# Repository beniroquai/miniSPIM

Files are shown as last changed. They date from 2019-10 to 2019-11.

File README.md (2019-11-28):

# miniSPIM
An attempt to democratize light-sheet microscopy. 

This is the repository for the open-source low-cost light-sheet microscope based on a monochromatic cellphone CMOS sensor and commercially available laser-scanning video projector.

<p align="center">
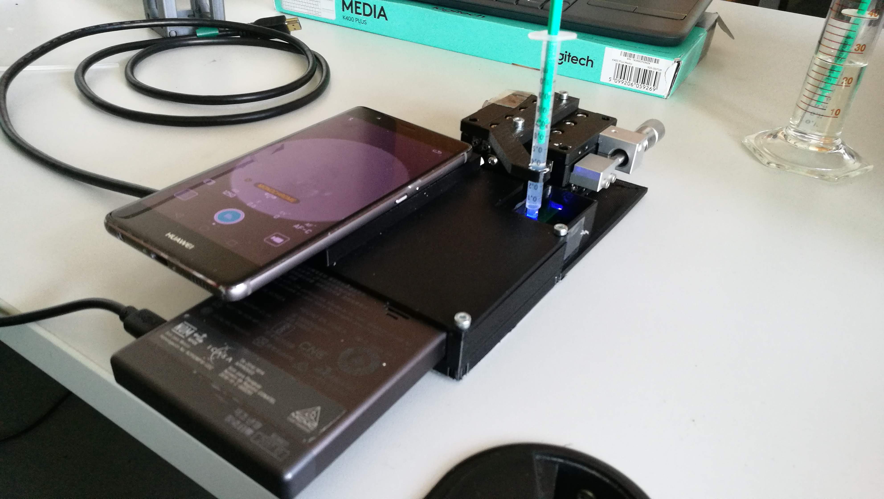
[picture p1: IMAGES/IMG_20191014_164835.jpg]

</p>

Disucssion can also be found in [Twitter](https://twitter.com/beniroquai/status/1185129736726560768)

Everything on your own risk, no guarantees that it works or that it harms you! It's just a fun project without any professional use in mind! 

## Motivation

*  Low price (<500€) 
*  Portable
*  Small footprint
*  ready for the incubator 
*  Isotropic resolution of about 3µm 
*  Excitation Wavelength: 450, 530, 605nm 
*  Mechanical X/Y-Stage for coarse sample movevement 
*  Electrical X/Y-Stage for fine through-focus series of the sample 

## ANDROID APP
**NEW**: Now we support the system with a stand-alone Android App which takes care of the following:

- Image acquisition (monochrome Huawei, RAW, manual texp, ISO-settings)
- Hardware control of the X/Y-stage for through-focus series (MQTT-based) 
- Control of the Light-sheet displayed on the Laser-projector

Everything can be found in the folder [ANDROID](.\ANDROID). It has been tested with a HUAWEI P9.
To display the pattern using a smartphone, one need to connect the laser-projector to the Phone using a HDMI-HML adapter (i.e. USB-c to HDMI), available for 8€ at Ebay. 

The 
<p align="center">
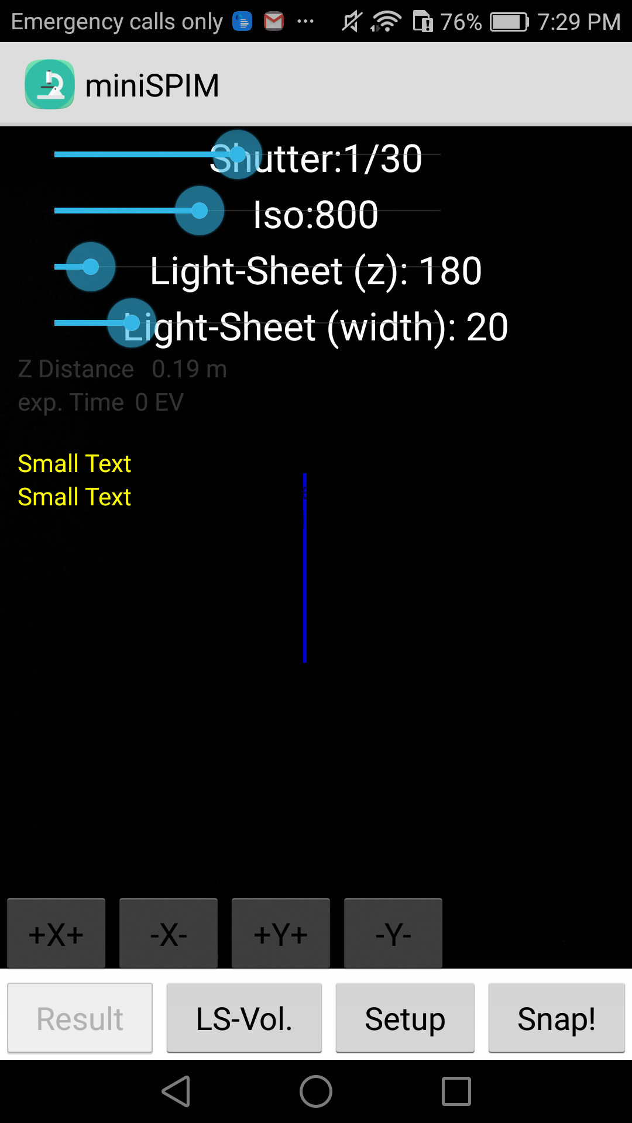
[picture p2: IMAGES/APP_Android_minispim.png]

</p>

The blue stripe is the secondary screen displayed in debug mode. 

## Setup

### Optical Setup

The 
<p align="center">
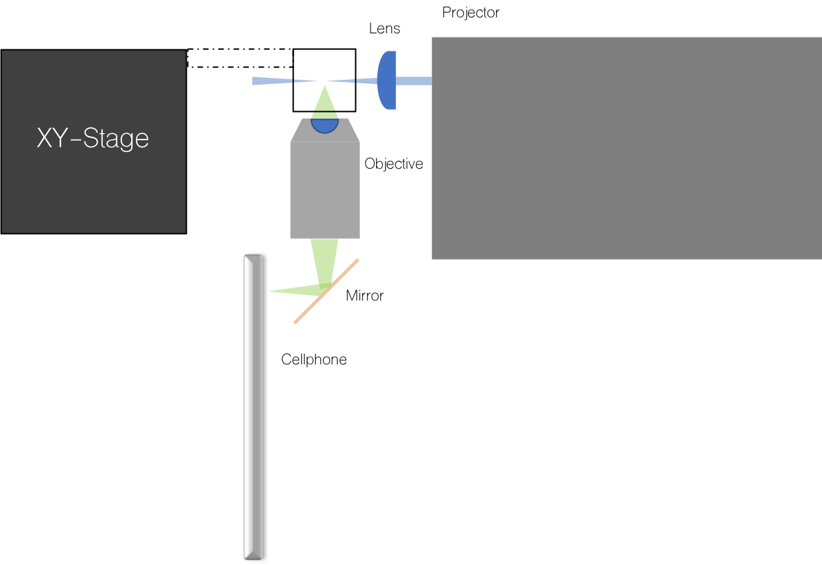
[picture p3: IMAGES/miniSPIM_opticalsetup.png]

</p>

### Remove the lens of the Huawei P9 (at your own risk!!)

In this setup, we had to remove the lens to have bare accessoto the Sony IMX286 monochromatic chip. A minimum set of tools was necessary. A brief description with pictures is shown below

#### Open the cellphone
<p align="center">
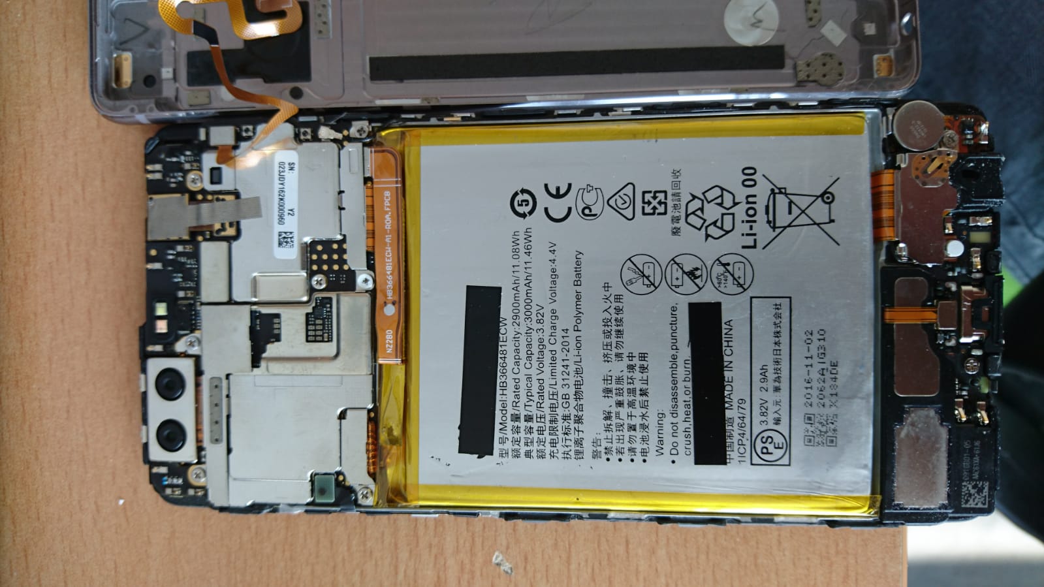
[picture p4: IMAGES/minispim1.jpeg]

</p>

#### Get out the camera module
<p align="center">
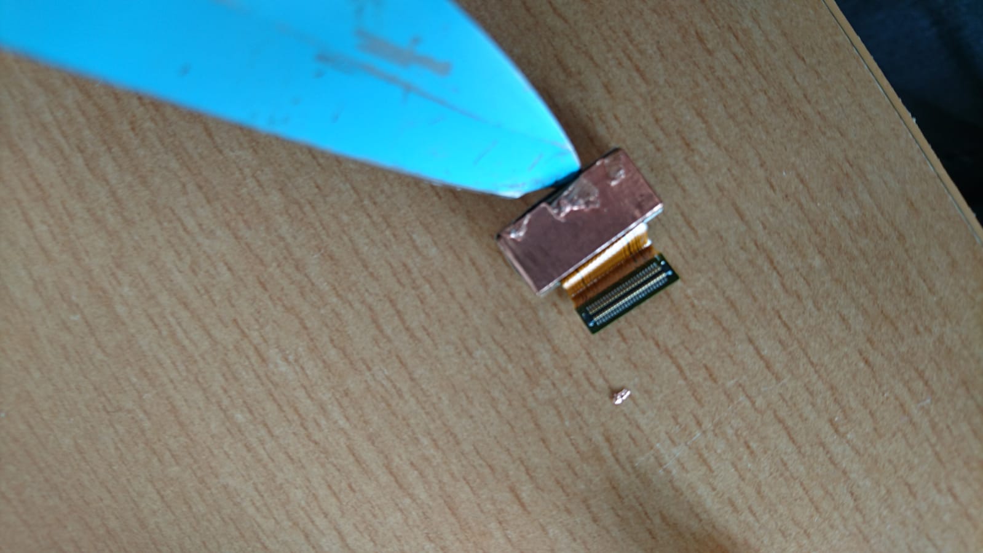
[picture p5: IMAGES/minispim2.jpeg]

</p>

#### Get out the camera module II
<p align="center">
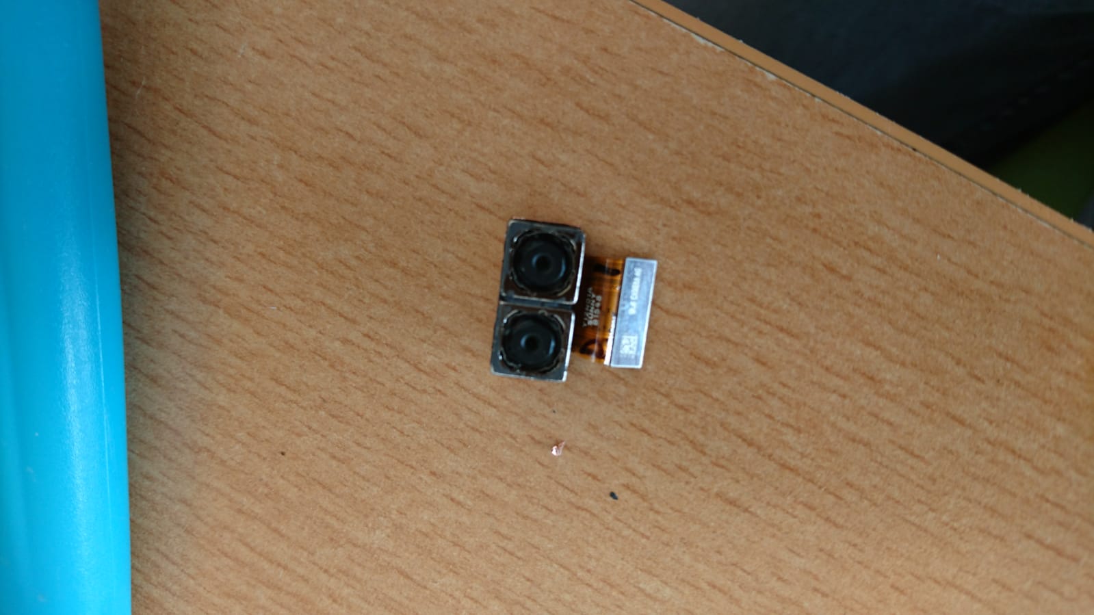
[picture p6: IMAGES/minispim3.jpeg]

</p>

#### Get rid of the left (!) lens module - take a knife to remove the soldering gently (!)
<p align="center">
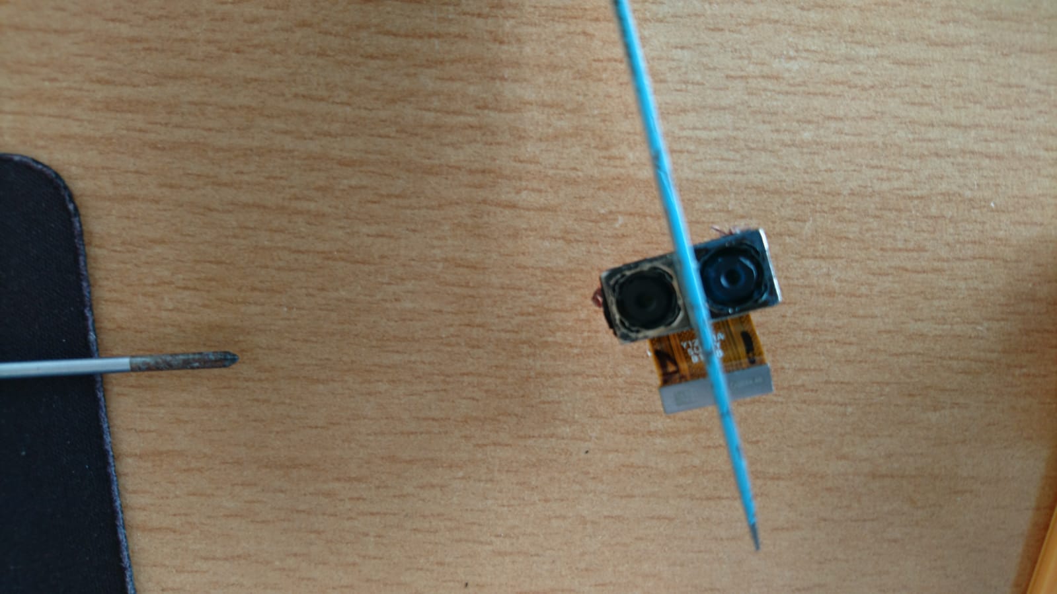
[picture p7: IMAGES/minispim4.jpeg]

</p>

#### Get rid of the lens module 
<p align="center">
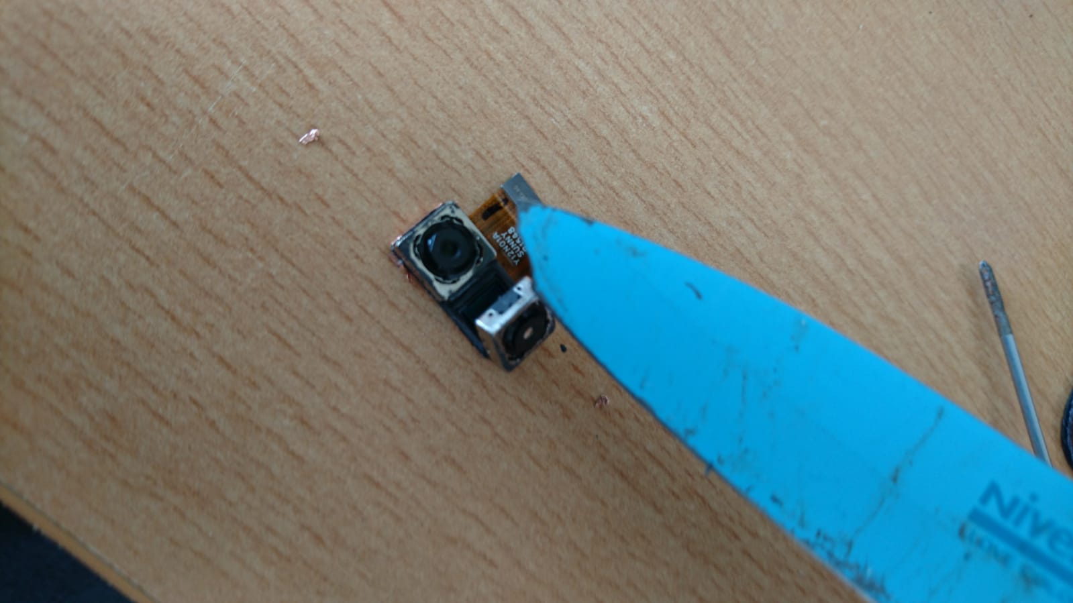
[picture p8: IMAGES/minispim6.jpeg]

</p>

#### Put the lens module back into the cellphone
<p align="center">
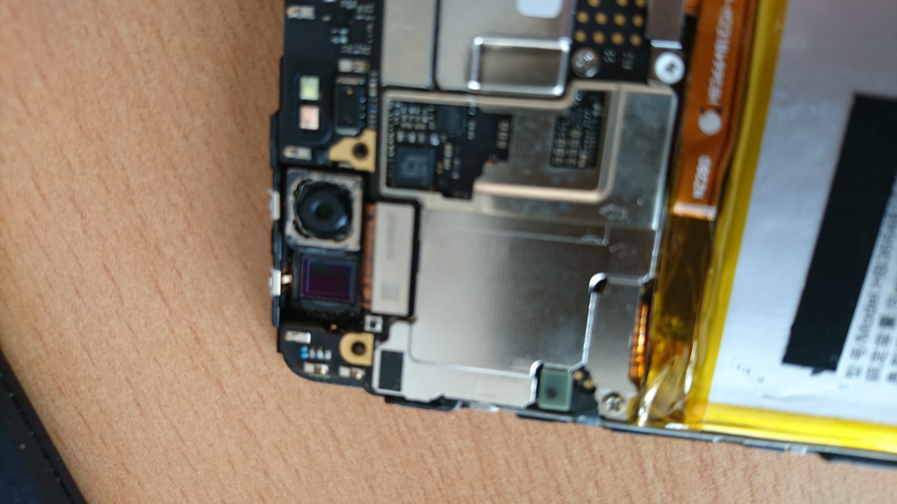
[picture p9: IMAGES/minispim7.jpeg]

</p>

#### Hope that everything went well!
<p align="center">
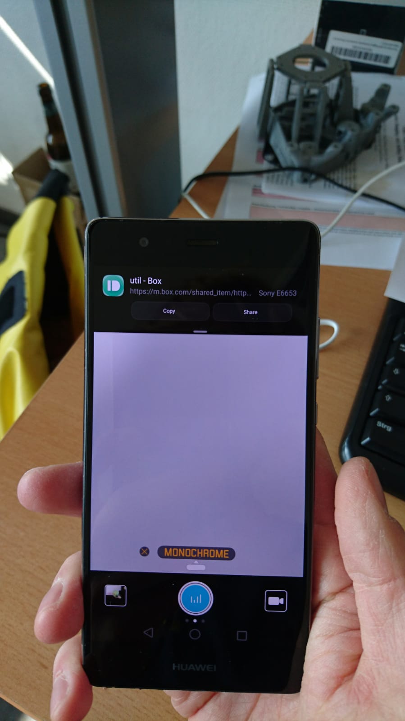
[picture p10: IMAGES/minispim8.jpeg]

</p>

### Mechanical Setup

The Setup is relatively simple to assemble. A base-plate holds the Projector, the lenses (CCTV as objective and 25mm lens as illumination objective) as well as the mirror. The lid holds everything in place and the smartphone adapter keeps the cellphone in the correct distance from the CCTV lens.

#### Sample mount 

One can use asimple syrringe for to prepare a sample e.g. in agarose. To reduce scattering, we provide a simple sample chaber which an be filled with water. The tip of the agarose can be put inside the water. 

### Electronic setup

For the wiring of the two bipolar motors from the low-cost XY-stage, we used an Arduino Nano equipped with two H-bridges directly connected to the motor. 

The following gives you a very brief introduction of the workin principle of the low-cost, but very precise Z-stage which is used in our setups. You can find a more detailed version of the description at [aliexpress](https://aliexpress.com/item/Micro-stepping-motor-cross-platform-small-mobile-digital-microscope-XY-axis-table-experiment-two-slide/32790147861.html) (chineses though). 
I have absolutely no clue where this piece is actually coming from, but it is working really great! 

It is equipped with two bipolar stepper motors for X and Y direction. The wiring follows (from left to right):

	1 -- A+	
	2 -- B+	
	3 -- A-	
	4 -- B-
	
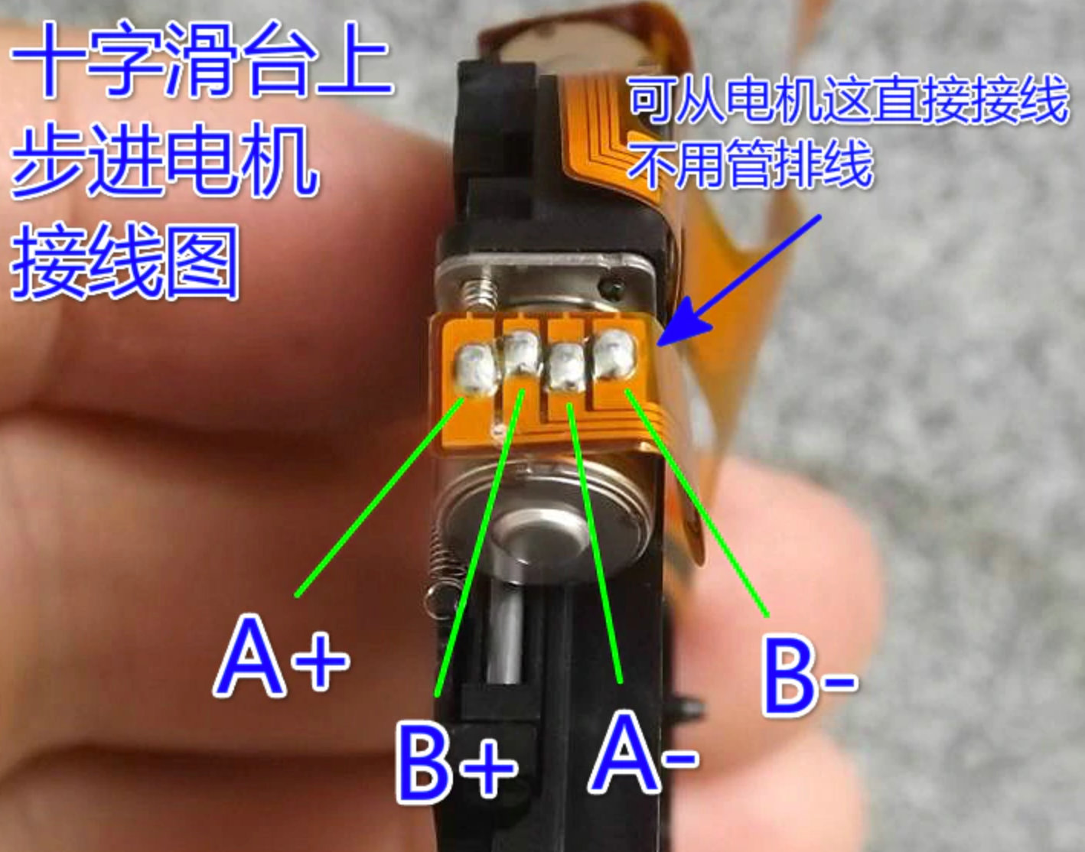
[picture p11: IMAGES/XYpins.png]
xypins


It can be controlled with an ESP32 or Arduino for example. Code is very easy as it relies on the $stepper.h$ library in Arduion IDE. We tested seveal H-Bridges to amplify the current coming from the Arduino GPIOs. The L293m works fine, but the DRV8833 is also good and even much smaller. The complete tutorial for can also be found at [Adafruit](https://learn.adafruit.com/adafruit-drv8833-dc-stepper-motor-driver-breakout-board/stepper-motor-usage). 

The motor can be connected as follows:

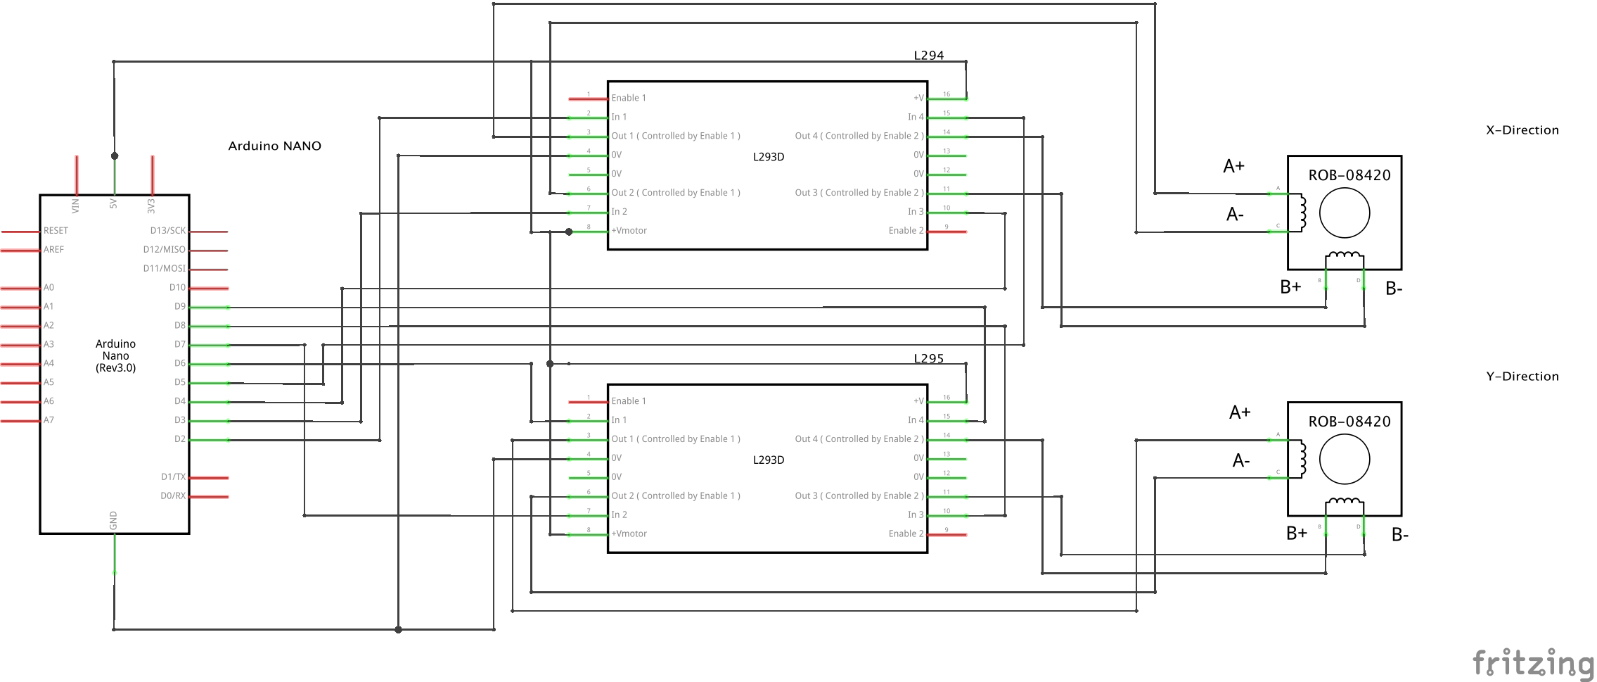
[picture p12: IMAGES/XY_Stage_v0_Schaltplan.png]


If one uses an H-Bridge one simply need to make sure, that A+/A- and B+/B- are connected to MOTOR A and MOTOR B respectively. 

#### Properties
	- Impedance: ~45 ohm
	- Stepsize: 18 degree
	- Voltage: 5 V
	- Peak Current: 100mA 
	- Movement X/Y: 2.4 mm

### Code 
The code is from the Adafruit example with the wiring explained above:

	#include <Stepper.h>
 
	// change this to the number of steps on your motor
	#define STEPS 200
	 
	// create an instance of the stepper class, specifying
	// the number of steps of the motor and the pins it's
	// attached to
	Stepper stepper(STEPS, 4, 5, 6, 7);

	void setup()
	{
	  Serial.begin(9600);
	  Serial.println("Stepper test!");
	  // set the speed of the motor to 30 RPMs
	  stepper.setSpeed(60);
	}
	 
	void loop()
	{
	  Serial.println("Forward");
	  stepper.step(STEPS);
	  Serial.println("Backward");
	  stepper.step(-STEPS);
	}

### NOTES
Make sure you're releasing the Motor after usage, otherwise it can get quiet hot!

## Experiments

In order to perform an experiment one need to do the following steps:

* Generate the light-sheet pattern using a computer by displaying a single-pixel line on a full-screen image (e.g. black screen, blue line (RGB=0,0,255))
* Eventually move the line periodically to find the best position of the light sheet (use the PPT in the presentation folder) 
* Align the smartphone, so that the round-circle is in the center of the CMOS camera sensor (therefore take a light-source and shine light inside the smaple chamber, i.e. inline with the CCTV lens)
* Insert the syringe in the sample holder
* Move the X/Y move so that the sample is in focus by placing a light source perpendicular to the light-sheet or in-line with the detection objective 
* Let the electric X/Y stage oscillate back and forth to acquire a through-focus series 
* Acquire a video sequence of the sample

## Parts 

### 3D printed parts 
All files can be found in the folder [STL](./STL). 

* 1x [Base Plate](./STL/0_MiniSPIM_Base_v1.stl)
* 1x [Sample Chamber](./STL/10_MiniSPIM_Samplechamber.stl)
* 1x [Space for Smartphone](./STL/10_MiniSPIM_Smarthponebase.stl)
* 1x [Lid for the Baseplate](./STL/10_MiniSPIM_Lid.stl)
* 1x [Adapter for the XY-Stage: Arm which holds the syrringe](./STL/10_MiniSPIM_XY_Stageplate.stl)
* 1x [Adapter for the XY-Stage: Arm which holds the electronic XY-stage](./STL/10_MiniSPIM_XY_Stageplate.stl)

### Bill of materials

(Links to the shops are not sponsored!)

* 1x cellphone (Huawei P9, remove the lens from the monochromatic camera) - ***150€***
* 1x XY-Stage (60x60xmm range) - ***60€***
* 1x motorized XY-Stage ([aliexpress](https://aliexpress.com/item/Micro-stepping-motor-cross-platform-small-mobile-digital-microscope-XY-axis-table-experiment-two-slide/32790147861.html) ) - ***3€***
* 1x ESP32 - ***5€***
* Set of M3 screws - ***1€***
* 3x Coverglass, 18x18mm - ***1€***
* 1x Laser-scanning projector, SONY MP-CL1A [Link to Sony](https://www.sony.com/electronics/projector/mp-cl1a) - ***250€***
* Filterset ***1€***
* Wires, USB-Cable, HDMI-Cable - ***15€***
* Comar Mirror d=10mm - ***20€***
* 1x CCTV Lens (f=4mm, f#=1.8) - ***10€***
* 1x 25mm lens, diameter: 15mm

## Results

### Acquisition using the cellphone 

The Huawei P9 does not allow the acquisition of monochromatic videos by default. Therefore we used the open-source app ***FreeDCam*** available from [github](https://github.com/KillerInk/FreeDcam/tree/cellstorm) or the playstore. In order to reduce the bouncing effect caused by intereference of the scan-speed of the laser (60 Hz), one need to select a frame-rate t_exp < 1/60 s respectively. ISO settings should be selected to get enough signal (usally 1000-2000) for high-quality samples. 

### Use MP4 in Fiji 

Since Fiji does not accept ```.mp4```-files by default, one need to transcode the video into a sequence of images which can be imported through Fiji. This can conveniently be done by using ```ffmpeg``` (freely available from Windows, MAC and Linux!). A standard command to extract the frames into a folder is the following: 

```ffmpeg -i MOV_2019_10_24_07_33_13.mp4 -filter:v "crop=1024:1024:512:512" -vsync 0  MOV_2019_10_24_07_33_13/cropped%06d.png```

### Lens-tissue Focus-Sweep

Here a lens-tissue "labelled" with fluorescent marker (Stabilo, Fluorescent Yellow) was swept through the focus. A theater filter blocks the light of the blue exciting laser. 

<p align="center">
<img src="./IMAGES/miniSPIM_Focus_Sweep_Lenstissue.gif" width="400">
</p>

A 3D projection of the result in ClearVolume looks like this: 
<p align="center">
<img src="./IMAGES/miniSPIM_lenstissue.png" width="400">
</p>

### Bright-field and light-sheet mode of Pollen

<p align="center">
<img src="./IMAGES/IMG_20191014_163941.jpg" width="400">
</p>

<p align="center">
<img src="./IMAGES/IMG_20191014_164712.jpg" width="400">
</p>

Better images are coming soon! 

## License
Hardware follows the CERN license. Everything else is licensed under CC-BY-NC. 

Everything is free to use - but we would like to ask you for any suggestions and comments. This makes sure, that we can improve this project. 

Everything was developed in the [@Heintzmann-Lab](www.nanoimaging.de) around Rainer Heintzmann at the IPHT Jena. 

## Contribution

We need proper samples! If you know how to prepare easy to use cleared fluorescent samples ready for the SPIM, please contact us!! :) 

In case you have any questions, please fiel an issue or write us an email. We try to improve the setup. 

There is high potential to automate everything - if you have time and want to do that: We hire (but don't have any money - sorry ;-)

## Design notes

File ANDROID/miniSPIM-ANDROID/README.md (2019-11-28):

Machine-learned Phase-Contrast using a 3D printed microscope based on DPC
=========================================================================

Derived from code snippets used in the paper paper by Lei Tian, Jingyan Wang, and Laura Waller

The app takes a series of images, where the "Presentation API" from Android displays a specific pattern on a projector. The images are getting processed to feed a neural network trained in Tensorflow to produce an optimized illumination shape to enhance the phase contrast of an arbitrary object.

The version here is distributed under the GPL v3 license. If you have any questions, please get back to us by contacting us: https://nanoimaging.de

## INSTRUCTIONS 
A set of instructions can be found here:
[PDF Tutorial:](https://github.com/bionanoimaging/Beamerscope_CAD/blob/master/Beamerscope_Instructions.pdf)

If you need any further details, please contact us via our [website](nanoimaging.de).

CAD Drawing Beamerscope

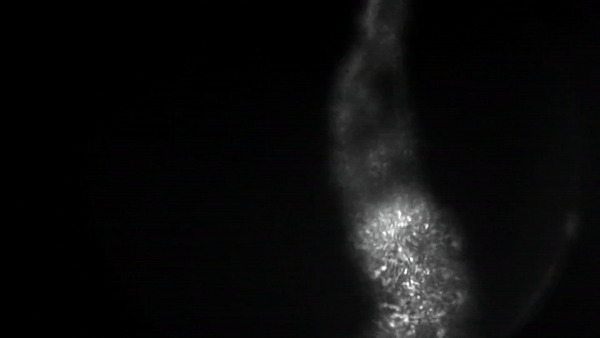
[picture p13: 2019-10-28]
IMAGES/miniSPIM_Focus_Sweep_Lenstissue.gif

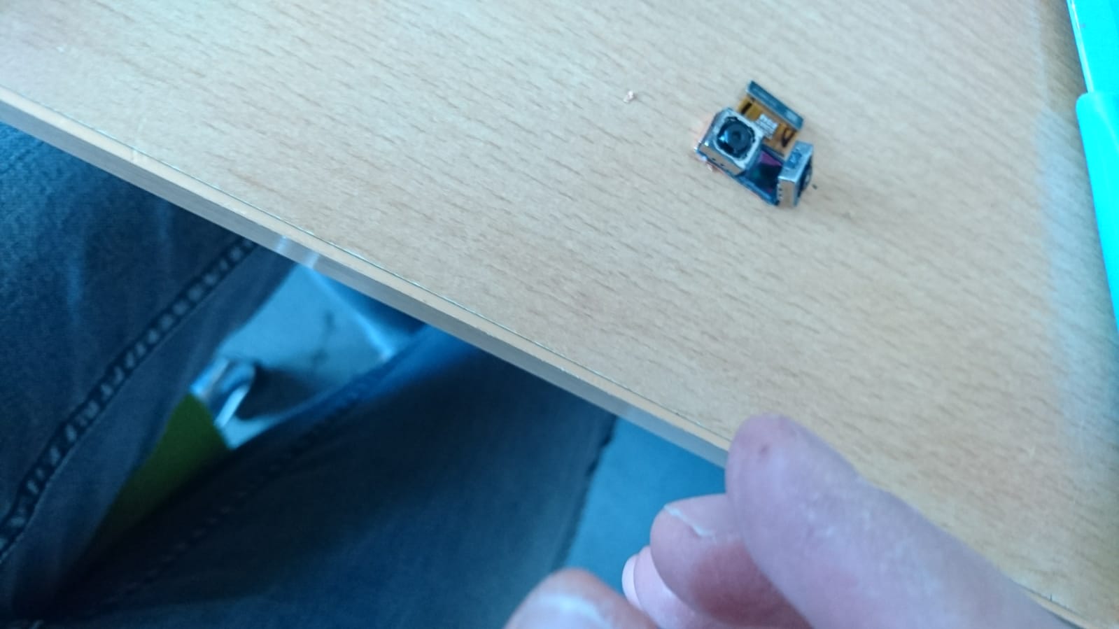
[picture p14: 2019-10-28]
IMAGES/minispim5.jpeg

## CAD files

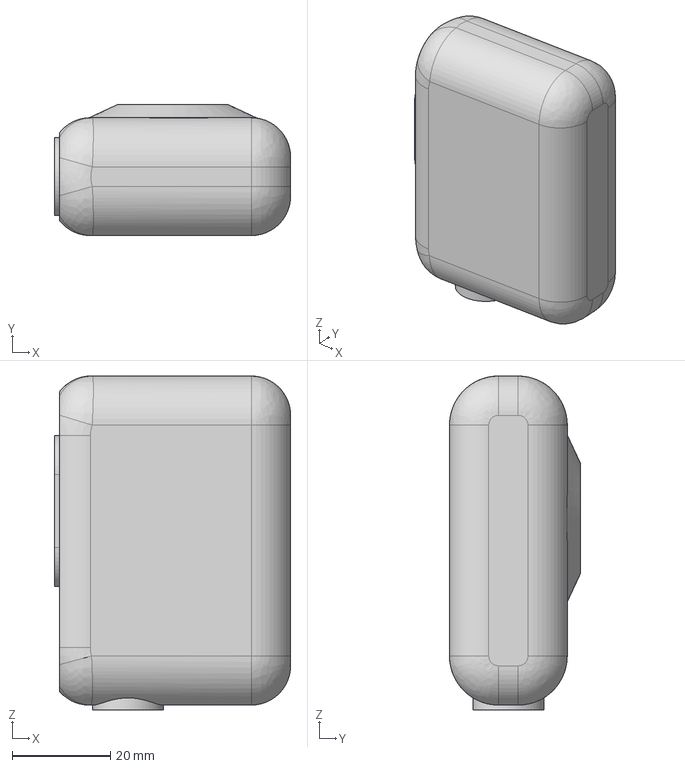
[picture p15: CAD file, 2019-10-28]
INVENTOR/100_DXO_Camera v2.step
48.1 x 26.7 x 68.0 mm

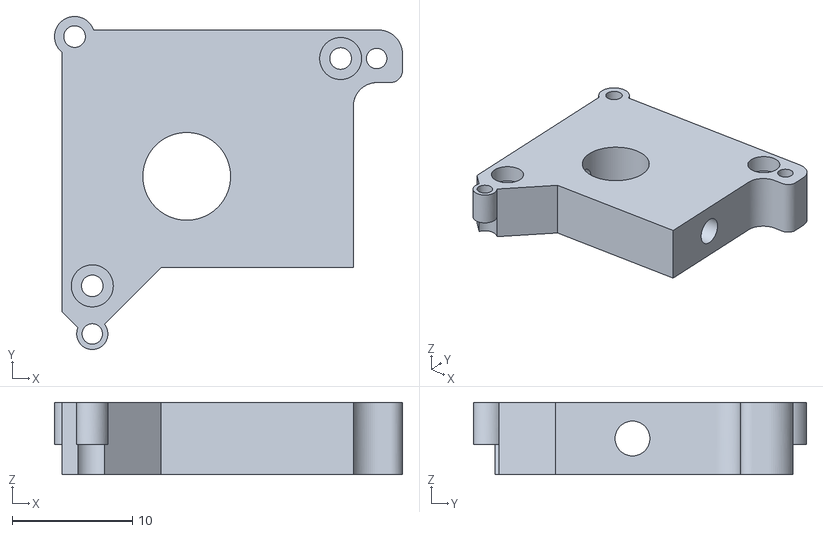
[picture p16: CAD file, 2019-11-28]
STL/110_Syrringeholder_XY_Stage.stl
29.0 x 27.7 x 6.00

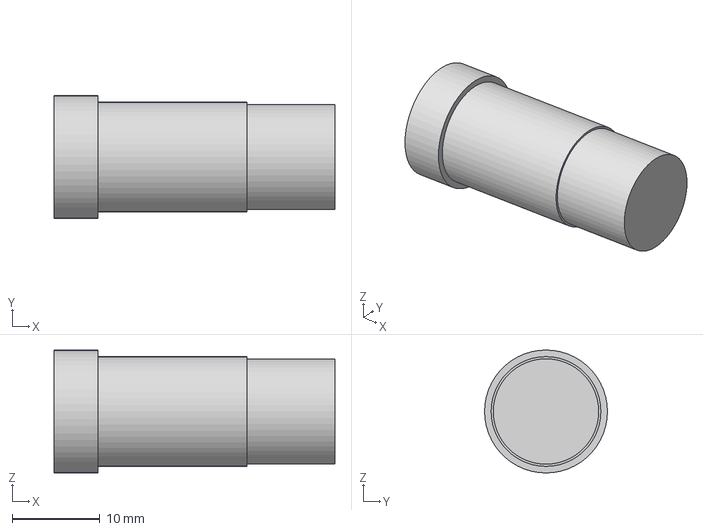
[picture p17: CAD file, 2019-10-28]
INVENTOR/104_CCTV_Lens_f2.8_#1.4 v2.step
32.0 x 14.0 x 14.0 mm

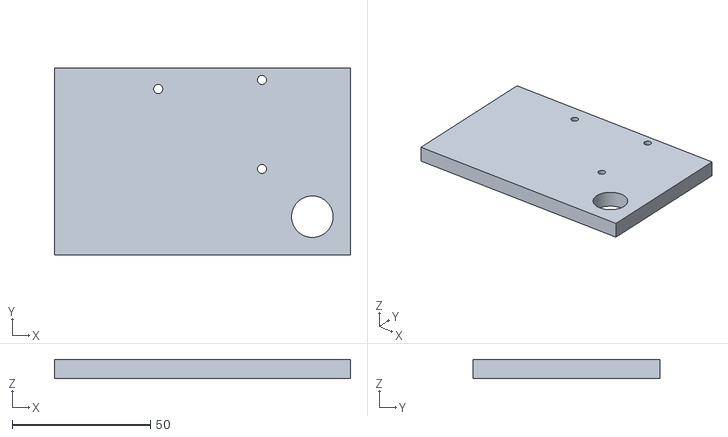
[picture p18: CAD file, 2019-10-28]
STL/10_MiniSPIM_Smarthponebase.stl
107.0 x 67.5 x 6.90

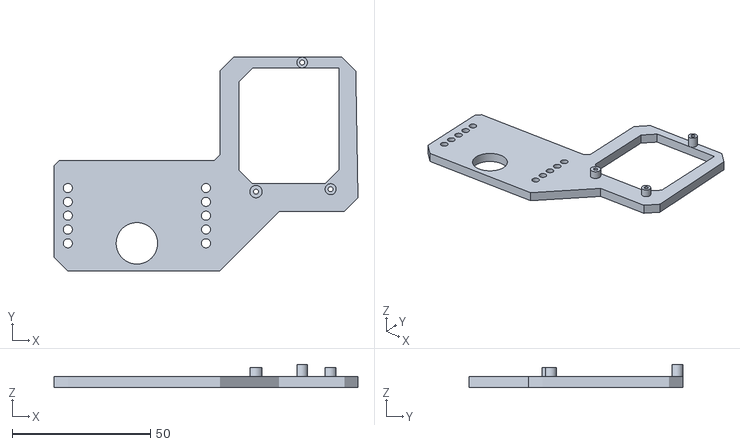
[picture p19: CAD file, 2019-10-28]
STL/10_MiniSPIM_XY_Stageplate.stl
110.0 x 77.3 x 8.50

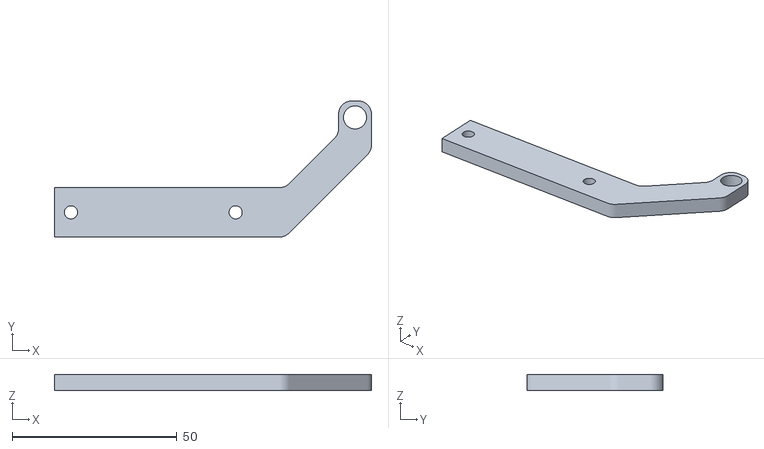
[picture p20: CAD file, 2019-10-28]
STL/10_MiniSPIM_Sampleholder.stl
96.2 x 41.3 x 5.00

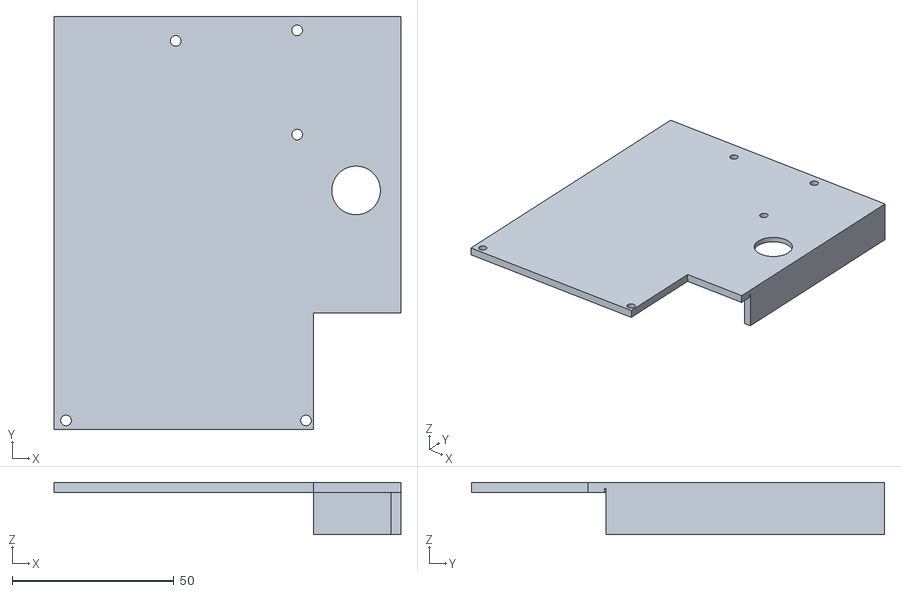
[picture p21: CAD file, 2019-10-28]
STL/10_MiniSPIM_Lid.stl
107.0 x 127.5 x 16.2

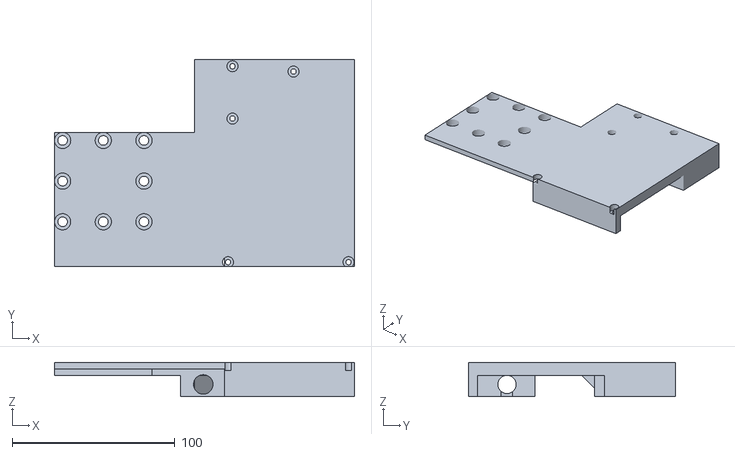
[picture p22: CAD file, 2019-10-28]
STL/10_MiniSPIM_Base_v1.stl
184.4 x 127.5 x 21.1

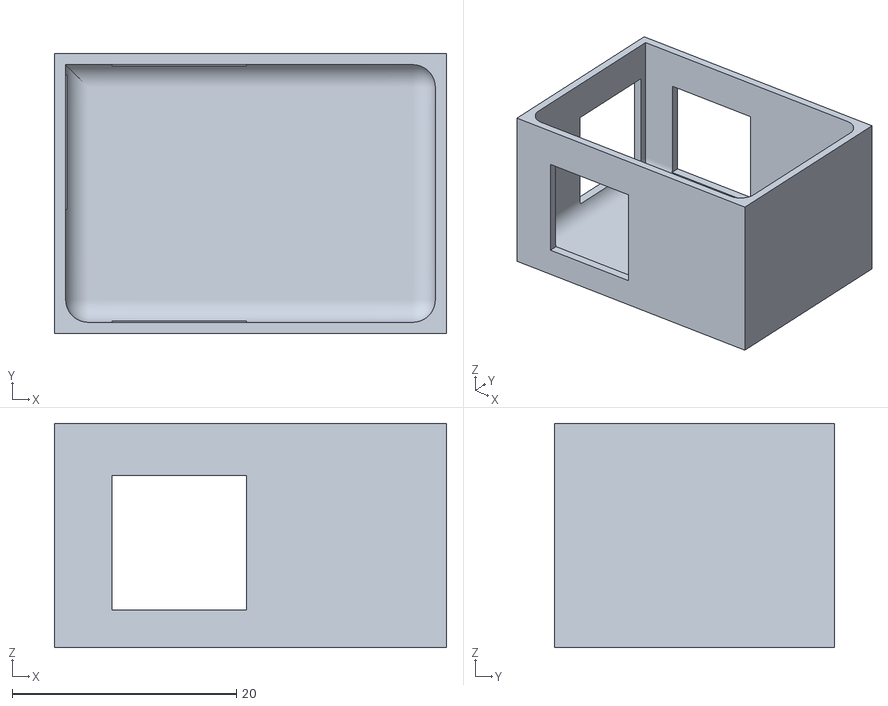
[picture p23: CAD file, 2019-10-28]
STL/10_MiniSPIM_Samplechamber.stl
35.0 x 25.0 x 20.0

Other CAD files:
INVENTOR/00_Huawei_P9.ipt
INVENTOR/00_Laserpointer_450nm_blue.ipt
INVENTOR/00_Lens_f_25mm.ipt
INVENTOR/00_Lightpath.ipt
INVENTOR/00_Mirror_10mmDia.ipt
INVENTOR/00_Sony_MDL_Projector.ipt
INVENTOR/00_XY-Tisch_Chinaware_Benedict-Diederich.ipt
INVENTOR/00_XY_stage-CHUO_SEIKI_LD-647-R1-Bottom.ipt
INVENTOR/00_XY_stage-CHUO_SEIKI_LD-647-R1-Middle.ipt
INVENTOR/00_XY_stage-CHUO_SEIKI_LD-647-R1-Top.ipt
INVENTOR/00_XY_stage-CHUO_SEIKI_LD-647-R1.iam
INVENTOR/100_DXO_Camera v2.ipt
INVENTOR/101_CCTV_Lens_Thread.ipt
INVENTOR/102_Z_Focus_CCTV_Camera.ipt
INVENTOR/103_CCTV_Lens_f2.8_f#1.4 v1.f3d
INVENTOR/103_CCTV_Lens_f2.8_f#1.ipt
INVENTOR/104_CCTV_Lens_f2.8_#1.ipt
INVENTOR/105_CCTV_Lens_f6_f#1.ipt
INVENTOR/106_Glassslab.ipt
INVENTOR/109_Chinese_XY_stage.ipt
INVENTOR/10_Baseplate_Minispim.ipt
INVENTOR/10_Lid_Minispim.ipt
INVENTOR/10_Lidplate_Minispim.ipt
INVENTOR/10_MiniSPIM_Base_v1.ipt
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

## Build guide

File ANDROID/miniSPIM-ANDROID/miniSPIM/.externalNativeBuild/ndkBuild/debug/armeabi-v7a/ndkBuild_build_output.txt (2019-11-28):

rm -f /Users/Bene/Dropbox/Dokumente/OpticalDesign/Beamerscope/Android/BeamerscopeIlloptimization/holoscope/build/intermediates/ndkBuild/debug/lib/armeabi-v7a/lib*.so
rm -f /Users/Bene/Dropbox/Dokumente/OpticalDesign/Beamerscope/Android/BeamerscopeIlloptimization/holoscope/build/intermediates/ndkBuild/debug/lib/armeabi-v7a/gdbserver
rm -f /Users/Bene/Dropbox/Dokumente/OpticalDesign/Beamerscope/Android/BeamerscopeIlloptimization/holoscope/build/intermediates/ndkBuild/debug/lib/armeabi-v7a/gdb.setup
echo [armeabi-v7a] "Compile++ thumb": "native_microscope <= cvComplex.cpp"
/Users/Bene/Library/Android/sdk/ndk-bundle/toolchains/arm-linux-androideabi-4.9/prebuilt/darwin-x86_64/bin/arm-linux-androideabi-g++ -MMD -MP -MF /Users/Bene/Dropbox/Dokumente/OpticalDesign/Beamerscope/Android/BeamerscopeIlloptimization/holoscope/.externalNativeBuild/ndkBuild/debug/obj/local/armeabi-v7a/objs/native_microscope/cvComplex.o.d -fpic -ffunction-sections -funwind-tables -fstack-protector-strong -no-canonical-prefixes  -g -march=armv7-a -mfpu=vfpv3-d16 -mfloat-abi=softfp  -fno-exceptions -fno-rtti -mthumb -Os -DNDEBUG  -I"/Users/Bene/Android/opencv3/sdk/native/jni/include/opencv" -I"/Users/Bene/Android/opencv3/sdk/native/jni/include" -I/Users/Bene/Android/opencv3/sdk/native/jni/include/ -I/Users/Bene/Dropbox/Dokumente/OpticalDesign/Beamerscope/Android/BeamerscopeIlloptimization/holoscope/src/main/jni -I/Users/Bene/Library/Android/sdk/ndk-bundle/sources/cxx-stl/gnu-libstdc++/4.9/include -I/Users/Bene/Library/Android/sdk/ndk-bundle/sources/cxx-stl/gnu-libstdc++/4.9/libs/armeabi-v7a/include -I/Users/Bene/Library/Android/sdk/ndk-bundle/sources/cxx-stl/gnu-libstdc++/4.9/include/backward -I/Users/Bene/Dropbox/Dokumente/OpticalDesign/Beamerscope/Android/BeamerscopeIlloptimization/holoscope/src/main/jni -DANDROID -fPIC -DANDROID -fsigned-char -Wa,--noexecstack -Wformat -Werror=format-security    -frtti -fexceptions  -isystem /Users/Bene/Library/Android/sdk/ndk-bundle/platforms/android-19/arch-arm/usr/include -c  /Users/Bene/Dropbox/Dokumente/OpticalDesign/Beamerscope/Android/BeamerscopeIlloptimization/holoscope/src/main/jni/cvComplex.cpp -o /Users/Bene/Dropbox/Dokumente/OpticalDesign/Beamerscope/Android/BeamerscopeIlloptimization/holoscope/.externalNativeBuild/ndkBuild/debug/obj/local/armeabi-v7a/objs/native_microscope/cvComplex.o 
echo [armeabi-v7a] "Compile++ thumb": "native_microscope <= common.cpp"
/Users/Bene/Library/Android/sdk/ndk-bundle/toolchains/arm-linux-androideabi-4.9/prebuilt/darwin-x86_64/bin/arm-linux-androideabi-g++ -MMD -MP -MF /Users/Bene/Dropbox/Dokumente/OpticalDesign/Beamerscope/Android/BeamerscopeIlloptimization/holoscope/.externalNativeBuild/ndkBuild/debug/obj/local/armeabi-v7a/objs/native_microscope/common.o.d -fpic -ffunction-sections -funwind-tables -fstack-protector-strong -no-canonical-prefixes  -g -march=armv7-a -mfpu=vfpv3-d16 -mfloat-abi=softfp  -fno-exceptions -fno-rtti -mthumb -Os -DNDEBUG  -I"/Users/Bene/Android/opencv3/sdk/native/jni/include/opencv" -I"/Users/Bene/Android/opencv3/sdk/native/jni/include" -I/Users/Bene/Android/opencv3/sdk/native/jni/include/ -I/Users/Bene/Dropbox/Dokumente/OpticalDesign/Beamerscope/Android/BeamerscopeIlloptimization/holoscope/src/main/jni -I/Users/Bene/Library/Android/sdk/ndk-bundle/sources/cxx-stl/gnu-libstdc++/4.9/include -I/Users/Bene/Library/Android/sdk/ndk-bundle/sources/cxx-stl/gnu-libstdc++/4.9/libs/armeabi-v7a/include -I/Users/Bene/Library/Android/sdk/ndk-bundle/sources/cxx-stl/gnu-libstdc++/4.9/include/backward -I/Users/Bene/Dropbox/Dokumente/OpticalDesign/Beamerscope/Android/BeamerscopeIlloptimization/holoscope/src/main/jni -DANDROID -fPIC -DANDROID -fsigned-char -Wa,--noexecstack -Wformat -Werror=format-security    -frtti -fexceptions  -isystem /Users/Bene/Library/Android/sdk/ndk-bundle/platforms/android-19/arch-arm/usr/include -c  /Users/Bene/Dropbox/Dokumente/OpticalDesign/Beamerscope/Android/BeamerscopeIlloptimization/holoscope/src/main/jni/common.cpp -o /Users/Bene/Dropbox/Dokumente/OpticalDesign/Beamerscope/Android/BeamerscopeIlloptimization/holoscope/.externalNativeBuild/ndkBuild/debug/obj/local/armeabi-v7a/objs/native_microscope/common.o 
echo [armeabi-v7a] "Compile++ thumb": "native_microscope <= jni_qDPC.cpp"
/Users/Bene/Library/Android/sdk/ndk-bundle/toolchains/arm-linux-androideabi-4.9/prebuilt/darwin-x86_64/bin/arm-linux-androideabi-g++ -MMD -MP -MF /Users/Bene/Dropbox/Dokumente/OpticalDesign/Beamerscope/Android/BeamerscopeIlloptimization/holoscope/.externalNativeBuild/ndkBuild/debug/obj/local/armeabi-v7a/objs/native_microscope/jni_qDPC.o.d -fpic -ffunction-sections -funwind-tables -fstack-protector-strong -no-canonical-prefixes  -g -march=armv7-a -mfpu=vfpv3-d16 -mfloat-abi=softfp  -fno-exceptions -fno-rtti -mthumb -Os -DNDEBUG  -I"/Users/Bene/Android/opencv3/sdk/native/jni/include/opencv" -I"/Users/Bene/Android/opencv3/sdk/native/jni/include" -I/Users/Bene/Android/opencv3/sdk/native/jni/include/ -I/Users/Bene/Dropbox/Dokumente/OpticalDesign/Beamerscope/Android/BeamerscopeIlloptimization/holoscope/src/main/jni -I/Users/Bene/Library/Android/sdk/ndk-bundle/sources/cxx-stl/gnu-libstdc++/4.9/include -I/Users/Bene/Library/Android/sdk/ndk-bundle/sources/cxx-stl/gnu-libstdc++/4.9/libs/armeabi-v7a/include -I/Users/Bene/Library/Android/sdk/ndk-bundle/sources/cxx-stl/gnu-libstdc++/4.9/include/backward -I/Users/Bene/Dropbox/Dokumente/OpticalDesign/Beamerscope/Android/BeamerscopeIlloptimization/holoscope/src/main/jni -DANDROID -fPIC -DANDROID -fsigned-char -Wa,--noexecstack -Wformat -Werror=format-security    -frtti -fexceptions  -isystem /Users/Bene/Library/Android/sdk/ndk-bundle/platforms/android-19/arch-arm/usr/include -c  /Users/Bene/Dropbox/Dokumente/OpticalDesign/Beamerscope/Android/BeamerscopeIlloptimization/holoscope/src/main/jni/jni_qDPC.cpp -o /Users/Bene/Dropbox/Dokumente/OpticalDesign/Beamerscope/Android/BeamerscopeIlloptimization/holoscope/.externalNativeBuild/ndkBuild/debug/obj/local/armeabi-v7a/objs/native_microscope/jni_qDPC.o 
echo [armeabi-v7a] "Compile++ thumb": "native_microscope <= jni_illpattern.cpp"
/Users/Bene/Library/Android/sdk/ndk-bundle/toolchains/arm-linux-androideabi-4.9/prebuilt/darwin-x86_64/bin/arm-linux-androideabi-g++ -MMD -MP -MF /Users/Bene/Dropbox/Dokumente/OpticalDesign/Beamerscope/Android/BeamerscopeIlloptimization/holoscope/.externalNativeBuild/ndkBuild/debug/obj/local/armeabi-v7a/objs/native_microscope/jni_illpattern.o.d -fpic -ffunction-sections -funwind-tables -fstack-protector-strong -no-canonical-prefixes  -g -march=armv7-a -mfpu=vfpv3-d16 -mfloat-abi=softfp  -fno-exceptions -fno-rtti -mthumb -Os -DNDEBUG  -I"/Users/Bene/Android/opencv3/sdk/native/jni/include/opencv" -I"/Users/Bene/Android/opencv3/sdk/native/jni/include" -I/Users/Bene/Android/opencv3/sdk/native/jni/include/ -I/Users/Bene/Dropbox/Dokumente/OpticalDesign/Beamerscope/Android/BeamerscopeIlloptimization/holoscope/src/main/jni -I/Users/Bene/Library/Android/sdk/ndk-bundle/sources/cxx-stl/gnu-libstdc++/4.9/include -I/Users/Bene/Library/Android/sdk/ndk-bundle/sources/cxx-stl/gnu-libstdc++/4.9/libs/armeabi-v7a/include -I/Users/Bene/Library/Android/sdk/ndk-bundle/sources/cxx-stl/gnu-libstdc++/4.9/include/backward -I/Users/Bene/Dropbox/Dokumente/OpticalDesign/Beamerscope/Android/BeamerscopeIlloptimization/holoscope/src/main/jni -DANDROID -fPIC -DANDROID -fsigned-char -Wa,--noexecstack -Wformat -Werror=format-security    -frtti -fexceptions  -isystem /Users/Bene/Library/Android/sdk/ndk-bundle/platforms/android-19/arch-arm/usr/include -c  /Users/Bene/Dropbox/Dokumente/OpticalDesign/Beamerscope/Android/BeamerscopeIlloptimization/holoscope/src/main/jni/jni_illpattern.cpp -o /Users/Bene/Dropbox/Dokumente/OpticalDesign/Beamerscope/Android/BeamerscopeIlloptimization/holoscope/.externalNativeBuild/ndkBuild/debug/obj/local/armeabi-v7a/objs/native_microscope/jni_illpattern.o 
echo [armeabi-v7a] "Compile++ thumb": "native_microscope <= jni_illparameter.cpp"
/Users/Bene/Library/Android/sdk/ndk-bundle/toolchains/arm-linux-androideabi-4.9/prebuilt/darwin-x86_64/bin/arm-linux-androideabi-g++ -MMD -MP -MF /Users/Bene/Dropbox/Dokumente/OpticalDesign/Beamerscope/Android/BeamerscopeIlloptimization/holoscope/.externalNativeBuild/ndkBuild/debug/obj/local/armeabi-v7a/objs/native_microscope/jni_illparameter.o.d -fpic -ffunction-sections -funwind-tables -fstack-protector-strong -no-canonical-prefixes  -g -march=armv7-a -mfpu=vfpv3-d16 -mfloat-abi=softfp  -fno-exceptions -fno-rtti -mthumb -Os -DNDEBUG  -I"/Users/Bene/Android/opencv3/sdk/native/jni/include/opencv" -I"/Users/Bene/Android/opencv3/sdk/native/jni/include" -I/Users/Bene/Android/opencv3/sdk/native/jni/include/ -I/Users/Bene/Dropbox/Dokumente/OpticalDesign/Beamerscope/Android/BeamerscopeIlloptimization/holoscope/src/main/jni -I/Users/Bene/Library/Android/sdk/ndk-bundle/sources/cxx-stl/gnu-libstdc++/4.9/include -I/Users/Bene/Library/Android/sdk/ndk-bundle/sources/cxx-stl/gnu-libstdc++/4.9/libs/armeabi-v7a/include -I/Users/Bene/Library/Android/sdk/ndk-bundle/sources/cxx-stl/gnu-libstdc++/4.9/include/backward -I/Users/Bene/Dropbox/Dokumente/OpticalDesign/Beamerscope/Android/BeamerscopeIlloptimization/holoscope/src/main/jni -DANDROID -fPIC -DANDROID -fsigned-char -Wa,--noexecstack -Wformat -Werror=format-security    -frtti -fexceptions  -isystem /Users/Bene/Library/Android/sdk/ndk-bundle/platforms/android-19/arch-arm/usr/include -c  /Users/Bene/Dropbox/Dokumente/OpticalDesign/Beamerscope/Android/BeamerscopeIlloptimization/holoscope/src/main/jni/jni_illparameter.cpp -o /Users/Bene/Dropbox/Dokumente/OpticalDesign/Beamerscope/Android/BeamerscopeIlloptimization/holoscope/.externalNativeBuild/ndkBuild/debug/obj/local/armeabi-v7a/objs/native_microscope/jni_illparameter.o 
echo [armeabi-v7a] "SharedLibrary  ": "libnative_microscope.so"
/Users/Bene/Library/Android/sdk/ndk-bundle/toolchains/arm-linux-androideabi-4.9/prebuilt/darwin-x86_64/bin/arm-linux-androideabi-g++ -Wl,-soname,libnative_microscope.so -shared --sysroot=/Users/Bene/Library/Android/sdk/ndk-bundle/platforms/android-19/arch-arm /Users/Bene/Dropbox/Dokumente/OpticalDesign/Beamerscope/Android/BeamerscopeIlloptimization/holoscope/.externalNativeBuild/ndkBuild/debug/obj/local/armeabi-v7a/objs/native_microscope/cvComplex.o /Users/Bene/Dropbox/Dokumente/OpticalDesign/Beamerscope/Android/BeamerscopeIlloptimization/holoscope/.externalNativeBuild/ndkBuild/debug/obj/local/armeabi-v7a/objs/native_microscope/common.o /Users/Bene/Dropbox/Dokumente/OpticalDesign/Beamerscope/Android/BeamerscopeIlloptimization/holoscope/.externalNativeBuild/ndkBuild/debug/obj/local/armeabi-v7a/objs/native_microscope/jni_qDPC.o /Users/Bene/Dropbox/Dokumente/OpticalDesign/Beamerscope/Android/BeamerscopeIlloptimization/holoscope/.externalNativeBuild/ndkBuild/debug/obj/local/armeabi-v7a/objs/native_microscope/jni_illpattern.o /Users/Bene/Dropbox/Dokumente/OpticalDesign/Beamerscope/Android/BeamerscopeIlloptimization/holoscope/.externalNativeBuild/ndkBuild/debug/obj/local/armeabi-v7a/objs/native_microscope/jni_illparameter.o /Users/Bene/Library/Android/sdk/ndk-bundle/sources/cxx-stl/gnu-libstdc++/4.9/libs/armeabi-v7a/libgnustl_static.a -lgcc /Users/Bene/Dropbox/Dokumente/OpticalDesign/Beamerscope/Android/BeamerscopeIlloptimization/holoscope/.externalNativeBuild/ndkBuild/debug/obj/local/armeabi-v7a/libopencv_java3.so -no-canonical-prefixes -march=armv7-a -Wl,--fix-cortex-a8   -Wl,--build-id -Wl,--no-undefined -Wl,-z,noexecstack -Wl,-z,relro -Wl,-z,now -Wl,--warn-shared-textrel -Wl,--fatal-warnings   -L/Users/Bene/Library/Android/sdk/ndk-bundle/platforms/android-19/arch-arm/usr/lib -llog -ldl -lc -lm -o /Users/Bene/Dropbox/Dokumente/OpticalDesign/Beamerscope/Android/BeamerscopeIlloptimization/holoscope/.externalNativeBuild/ndkBuild/debug/obj/local/armeabi-v7a/libnative_microscope.so
echo [armeabi-v7a] "Install        ": "libnative_microscope.so => /Users/Bene/Dropbox/Dokumente/OpticalDesign/Beamerscope/Android/BeamerscopeIlloptimization/holoscope/build/intermediates/ndkBuild/debug/lib/armeabi-v7a/libnative_microscope.so"
install -p /Users/Bene/Dropbox/Dokumente/OpticalDesign/Beamerscope/Android/BeamerscopeIlloptimization/holoscope/.externalNativeBuild/ndkBuild/debug/obj/local/armeabi-v7a/libnative_microscope.so /Users/Bene/Dropbox/Dokumente/OpticalDesign/Beamerscope/Android/BeamerscopeIlloptimization/holoscope/build/intermediates/ndkBuild/debug/lib/armeabi-v7a/libnative_microscope.so
/Users/Bene/Library/Android/sdk/ndk-bundle/toolchains/arm-linux-androideabi-4.9/prebuilt/darwin-x86_64/bin/arm-linux-androideabi-strip --strip-unneeded  /Users/Bene/Dropbox/Dokumente/OpticalDesign/Beamerscope/Android/BeamerscopeIlloptimization/holoscope/build/intermediates/ndkBuild/debug/lib/armeabi-v7a/libnative_microscope.so
echo [armeabi-v7a] "Install        ": "libopencv_java3.so => /Users/Bene/Dropbox/Dokumente/OpticalDesign/Beamerscope/Android/BeamerscopeIlloptimization/holoscope/build/intermediates/ndkBuild/debug/lib/armeabi-v7a/libopencv_java3.so"
install -p /Users/Bene/Dropbox/Dokumente/OpticalDesign/Beamerscope/Android/BeamerscopeIlloptimization/holoscope/.externalNativeBuild/ndkBuild/debug/obj/local/armeabi-v7a/libopencv_java3.so /Users/Bene/Dropbox/Dokumente/OpticalDesign/Beamerscope/Android/BeamerscopeIlloptimization/holoscope/build/intermediates/ndkBuild/debug/lib/armeabi-v7a/libopencv_java3.so
/Users/Bene/Library/Android/sdk/ndk-bundle/toolchains/arm-linux-androideabi-4.9/prebuilt/darwin-x86_64/bin/arm-linux-androideabi-strip --strip-unneeded  /Users/Bene/Dropbox/Dokumente/OpticalDesign/Beamerscope/Android/BeamerscopeIlloptimization/holoscope/build/intermediates/ndkBuild/debug/lib/armeabi-v7a/libopencv_java3.so

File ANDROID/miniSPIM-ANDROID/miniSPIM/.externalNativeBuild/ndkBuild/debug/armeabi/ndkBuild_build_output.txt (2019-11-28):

rm -f /Users/Bene/Dropbox/Dokumente/OpticalDesign/Beamerscope/Android/BeamerscopeIlloptimization/holoscope/build/intermediates/ndkBuild/debug/lib/armeabi/lib*.so
rm -f /Users/Bene/Dropbox/Dokumente/OpticalDesign/Beamerscope/Android/BeamerscopeIlloptimization/holoscope/build/intermediates/ndkBuild/debug/lib/armeabi/gdbserver
rm -f /Users/Bene/Dropbox/Dokumente/OpticalDesign/Beamerscope/Android/BeamerscopeIlloptimization/holoscope/build/intermediates/ndkBuild/debug/lib/armeabi/gdb.setup
echo [armeabi] "Compile++ thumb": "native_microscope <= cvComplex.cpp"
/Users/Bene/Library/Android/sdk/ndk-bundle/toolchains/arm-linux-androideabi-4.9/prebuilt/darwin-x86_64/bin/arm-linux-androideabi-g++ -MMD -MP -MF /Users/Bene/Dropbox/Dokumente/OpticalDesign/Beamerscope/Android/BeamerscopeIlloptimization/holoscope/.externalNativeBuild/ndkBuild/debug/obj/local/armeabi/objs/native_microscope/cvComplex.o.d -fpic -ffunction-sections -funwind-tables -fstack-protector-strong -no-canonical-prefixes  -g -march=armv5te -mtune=xscale -msoft-float  -fno-exceptions -fno-rtti -mthumb -Os -DNDEBUG  -I"/Users/Bene/Android/opencv3/sdk/native/jni/include/opencv" -I"/Users/Bene/Android/opencv3/sdk/native/jni/include" -I/Users/Bene/Android/opencv3/sdk/native/jni/include/ -I/Users/Bene/Dropbox/Dokumente/OpticalDesign/Beamerscope/Android/BeamerscopeIlloptimization/holoscope/src/main/jni -I/Users/Bene/Library/Android/sdk/ndk-bundle/sources/cxx-stl/gnu-libstdc++/4.9/include -I/Users/Bene/Library/Android/sdk/ndk-bundle/sources/cxx-stl/gnu-libstdc++/4.9/libs/armeabi/include -I/Users/Bene/Library/Android/sdk/ndk-bundle/sources/cxx-stl/gnu-libstdc++/4.9/include/backward -I/Users/Bene/Dropbox/Dokumente/OpticalDesign/Beamerscope/Android/BeamerscopeIlloptimization/holoscope/src/main/jni -DANDROID -fPIC -DANDROID -fsigned-char -Wa,--noexecstack -Wformat -Werror=format-security    -frtti -fexceptions  -isystem /Users/Bene/Library/Android/sdk/ndk-bundle/platforms/android-19/arch-arm/usr/include -c  /Users/Bene/Dropbox/Dokumente/OpticalDesign/Beamerscope/Android/BeamerscopeIlloptimization/holoscope/src/main/jni/cvComplex.cpp -o /Users/Bene/Dropbox/Dokumente/OpticalDesign/Beamerscope/Android/BeamerscopeIlloptimization/holoscope/.externalNativeBuild/ndkBuild/debug/obj/local/armeabi/objs/native_microscope/cvComplex.o 
echo [armeabi] "Compile++ thumb": "native_microscope <= common.cpp"
/Users/Bene/Library/Android/sdk/ndk-bundle/toolchains/arm-linux-androideabi-4.9/prebuilt/darwin-x86_64/bin/arm-linux-androideabi-g++ -MMD -MP -MF /Users/Bene/Dropbox/Dokumente/OpticalDesign/Beamerscope/Android/BeamerscopeIlloptimization/holoscope/.externalNativeBuild/ndkBuild/debug/obj/local/armeabi/objs/native_microscope/common.o.d -fpic -ffunction-sections -funwind-tables -fstack-protector-strong -no-canonical-prefixes  -g -march=armv5te -mtune=xscale -msoft-float  -fno-exceptions -fno-rtti -mthumb -Os -DNDEBUG  -I"/Users/Bene/Android/opencv3/sdk/native/jni/include/opencv" -I"/Users/Bene/Android/opencv3/sdk/native/jni/include" -I/Users/Bene/Android/opencv3/sdk/native/jni/include/ -I/Users/Bene/Dropbox/Dokumente/OpticalDesign/Beamerscope/Android/BeamerscopeIlloptimization/holoscope/src/main/jni -I/Users/Bene/Library/Android/sdk/ndk-bundle/sources/cxx-stl/gnu-libstdc++/4.9/include -I/Users/Bene/Library/Android/sdk/ndk-bundle/sources/cxx-stl/gnu-libstdc++/4.9/libs/armeabi/include -I/Users/Bene/Library/Android/sdk/ndk-bundle/sources/cxx-stl/gnu-libstdc++/4.9/include/backward -I/Users/Bene/Dropbox/Dokumente/OpticalDesign/Beamerscope/Android/BeamerscopeIlloptimization/holoscope/src/main/jni -DANDROID -fPIC -DANDROID -fsigned-char -Wa,--noexecstack -Wformat -Werror=format-security    -frtti -fexceptions  -isystem /Users/Bene/Library/Android/sdk/ndk-bundle/platforms/android-19/arch-arm/usr/include -c  /Users/Bene/Dropbox/Dokumente/OpticalDesign/Beamerscope/Android/BeamerscopeIlloptimization/holoscope/src/main/jni/common.cpp -o /Users/Bene/Dropbox/Dokumente/OpticalDesign/Beamerscope/Android/BeamerscopeIlloptimization/holoscope/.externalNativeBuild/ndkBuild/debug/obj/local/armeabi/objs/native_microscope/common.o 
echo [armeabi] "Compile++ thumb": "native_microscope <= jni_qDPC.cpp"
/Users/Bene/Library/Android/sdk/ndk-bundle/toolchains/arm-linux-androideabi-4.9/prebuilt/darwin-x86_64/bin/arm-linux-androideabi-g++ -MMD -MP -MF /Users/Bene/Dropbox/Dokumente/OpticalDesign/Beamerscope/Android/BeamerscopeIlloptimization/holoscope/.externalNativeBuild/ndkBuild/debug/obj/local/armeabi/objs/native_microscope/jni_qDPC.o.d -fpic -ffunction-sections -funwind-tables -fstack-protector-strong -no-canonical-prefixes  -g -march=armv5te -mtune=xscale -msoft-float  -fno-exceptions -fno-rtti -mthumb -Os -DNDEBUG  -I"/Users/Bene/Android/opencv3/sdk/native/jni/include/opencv" -I"/Users/Bene/Android/opencv3/sdk/native/jni/include" -I/Users/Bene/Android/opencv3/sdk/native/jni/include/ -I/Users/Bene/Dropbox/Dokumente/OpticalDesign/Beamerscope/Android/BeamerscopeIlloptimization/holoscope/src/main/jni -I/Users/Bene/Library/Android/sdk/ndk-bundle/sources/cxx-stl/gnu-libstdc++/4.9/include -I/Users/Bene/Library/Android/sdk/ndk-bundle/sources/cxx-stl/gnu-libstdc++/4.9/libs/armeabi/include -I/Users/Bene/Library/Android/sdk/ndk-bundle/sources/cxx-stl/gnu-libstdc++/4.9/include/backward -I/Users/Bene/Dropbox/Dokumente/OpticalDesign/Beamerscope/Android/BeamerscopeIlloptimization/holoscope/src/main/jni -DANDROID -fPIC -DANDROID -fsigned-char -Wa,--noexecstack -Wformat -Werror=format-security    -frtti -fexceptions  -isystem /Users/Bene/Library/Android/sdk/ndk-bundle/platforms/android-19/arch-arm/usr/include -c  /Users/Bene/Dropbox/Dokumente/OpticalDesign/Beamerscope/Android/BeamerscopeIlloptimization/holoscope/src/main/jni/jni_qDPC.cpp -o /Users/Bene/Dropbox/Dokumente/OpticalDesign/Beamerscope/Android/BeamerscopeIlloptimization/holoscope/.externalNativeBuild/ndkBuild/debug/obj/local/armeabi/objs/native_microscope/jni_qDPC.o 
echo [armeabi] "Compile++ thumb": "native_microscope <= jni_illpattern.cpp"
/Users/Bene/Library/Android/sdk/ndk-bundle/toolchains/arm-linux-androideabi-4.9/prebuilt/darwin-x86_64/bin/arm-linux-androideabi-g++ -MMD -MP -MF /Users/Bene/Dropbox/Dokumente/OpticalDesign/Beamerscope/Android/BeamerscopeIlloptimization/holoscope/.externalNativeBuild/ndkBuild/debug/obj/local/armeabi/objs/native_microscope/jni_illpattern.o.d -fpic -ffunction-sections -funwind-tables -fstack-protector-strong -no-canonical-prefixes  -g -march=armv5te -mtune=xscale -msoft-float  -fno-exceptions -fno-rtti -mthumb -Os -DNDEBUG  -I"/Users/Bene/Android/opencv3/sdk/native/jni/include/opencv" -I"/Users/Bene/Android/opencv3/sdk/native/jni/include" -I/Users/Bene/Android/opencv3/sdk/native/jni/include/ -I/Users/Bene/Dropbox/Dokumente/OpticalDesign/Beamerscope/Android/BeamerscopeIlloptimization/holoscope/src/main/jni -I/Users/Bene/Library/Android/sdk/ndk-bundle/sources/cxx-stl/gnu-libstdc++/4.9/include -I/Users/Bene/Library/Android/sdk/ndk-bundle/sources/cxx-stl/gnu-libstdc++/4.9/libs/armeabi/include -I/Users/Bene/Library/Android/sdk/ndk-bundle/sources/cxx-stl/gnu-libstdc++/4.9/include/backward -I/Users/Bene/Dropbox/Dokumente/OpticalDesign/Beamerscope/Android/BeamerscopeIlloptimization/holoscope/src/main/jni -DANDROID -fPIC -DANDROID -fsigned-char -Wa,--noexecstack -Wformat -Werror=format-security    -frtti -fexceptions  -isystem /Users/Bene/Library/Android/sdk/ndk-bundle/platforms/android-19/arch-arm/usr/include -c  /Users/Bene/Dropbox/Dokumente/OpticalDesign/Beamerscope/Android/BeamerscopeIlloptimization/holoscope/src/main/jni/jni_illpattern.cpp -o /Users/Bene/Dropbox/Dokumente/OpticalDesign/Beamerscope/Android/BeamerscopeIlloptimization/holoscope/.externalNativeBuild/ndkBuild/debug/obj/local/armeabi/objs/native_microscope/jni_illpattern.o 
echo [armeabi] "Compile++ thumb": "native_microscope <= jni_illparameter.cpp"
/Users/Bene/Library/Android/sdk/ndk-bundle/toolchains/arm-linux-androideabi-4.9/prebuilt/darwin-x86_64/bin/arm-linux-androideabi-g++ -MMD -MP -MF /Users/Bene/Dropbox/Dokumente/OpticalDesign/Beamerscope/Android/BeamerscopeIlloptimization/holoscope/.externalNativeBuild/ndkBuild/debug/obj/local/armeabi/objs/native_microscope/jni_illparameter.o.d -fpic -ffunction-sections -funwind-tables -fstack-protector-strong -no-canonical-prefixes  -g -march=armv5te -mtune=xscale -msoft-float  -fno-exceptions -fno-rtti -mthumb -Os -DNDEBUG  -I"/Users/Bene/Android/opencv3/sdk/native/jni/include/opencv" -I"/Users/Bene/Android/opencv3/sdk/native/jni/include" -I/Users/Bene/Android/opencv3/sdk/native/jni/include/ -I/Users/Bene/Dropbox/Dokumente/OpticalDesign/Beamerscope/Android/BeamerscopeIlloptimization/holoscope/src/main/jni -I/Users/Bene/Library/Android/sdk/ndk-bundle/sources/cxx-stl/gnu-libstdc++/4.9/include -I/Users/Bene/Library/Android/sdk/ndk-bundle/sources/cxx-stl/gnu-libstdc++/4.9/libs/armeabi/include -I/Users/Bene/Library/Android/sdk/ndk-bundle/sources/cxx-stl/gnu-libstdc++/4.9/include/backward -I/Users/Bene/Dropbox/Dokumente/OpticalDesign/Beamerscope/Android/BeamerscopeIlloptimization/holoscope/src/main/jni -DANDROID -fPIC -DANDROID -fsigned-char -Wa,--noexecstack -Wformat -Werror=format-security    -frtti -fexceptions  -isystem /Users/Bene/Library/Android/sdk/ndk-bundle/platforms/android-19/arch-arm/usr/include -c  /Users/Bene/Dropbox/Dokumente/OpticalDesign/Beamerscope/Android/BeamerscopeIlloptimization/holoscope/src/main/jni/jni_illparameter.cpp -o /Users/Bene/Dropbox/Dokumente/OpticalDesign/Beamerscope/Android/BeamerscopeIlloptimization/holoscope/.externalNativeBuild/ndkBuild/debug/obj/local/armeabi/objs/native_microscope/jni_illparameter.o 
echo [armeabi] "SharedLibrary  ": "libnative_microscope.so"
/Users/Bene/Library/Android/sdk/ndk-bundle/toolchains/arm-linux-androideabi-4.9/prebuilt/darwin-x86_64/bin/arm-linux-androideabi-g++ -Wl,-soname,libnative_microscope.so -shared --sysroot=/Users/Bene/Library/Android/sdk/ndk-bundle/platforms/android-19/arch-arm /Users/Bene/Dropbox/Dokumente/OpticalDesign/Beamerscope/Android/BeamerscopeIlloptimization/holoscope/.externalNativeBuild/ndkBuild/debug/obj/local/armeabi/objs/native_microscope/cvComplex.o /Users/Bene/Dropbox/Dokumente/OpticalDesign/Beamerscope/Android/BeamerscopeIlloptimization/holoscope/.externalNativeBuild/ndkBuild/debug/obj/local/armeabi/objs/native_microscope/common.o /Users/Bene/Dropbox/Dokumente/OpticalDesign/Beamerscope/Android/BeamerscopeIlloptimization/holoscope/.externalNativeBuild/ndkBuild/debug/obj/local/armeabi/objs/native_microscope/jni_qDPC.o /Users/Bene/Dropbox/Dokumente/OpticalDesign/Beamerscope/Android/BeamerscopeIlloptimization/holoscope/.externalNativeBuild/ndkBuild/debug/obj/local/armeabi/objs/native_microscope/jni_illpattern.o /Users/Bene/Dropbox/Dokumente/OpticalDesign/Beamerscope/Android/BeamerscopeIlloptimization/holoscope/.externalNativeBuild/ndkBuild/debug/obj/local/armeabi/objs/native_microscope/jni_illparameter.o /Users/Bene/Library/Android/sdk/ndk-bundle/sources/cxx-stl/gnu-libstdc++/4.9/libs/armeabi/libgnustl_static.a -lgcc /Users/Bene/Dropbox/Dokumente/OpticalDesign/Beamerscope/Android/BeamerscopeIlloptimization/holoscope/.externalNativeBuild/ndkBuild/debug/obj/local/armeabi/libopencv_java3.so -no-canonical-prefixes  -Wl,--build-id -Wl,--no-undefined -Wl,-z,noexecstack -Wl,-z,relro -Wl,-z,now -Wl,--warn-shared-textrel -Wl,--fatal-warnings   -L/Users/Bene/Library/Android/sdk/ndk-bundle/platforms/android-19/arch-arm/usr/lib -llog -ldl -lc -lm -o /Users/Bene/Dropbox/Dokumente/OpticalDesign/Beamerscope/Android/BeamerscopeIlloptimization/holoscope/.externalNativeBuild/ndkBuild/debug/obj/local/armeabi/libnative_microscope.so
mkdir -p /Users/Bene/Dropbox/Dokumente/OpticalDesign/Beamerscope/Android/BeamerscopeIlloptimization/holoscope/build/intermediates/ndkBuild/debug/lib/armeabi
echo [armeabi] "Install        ": "libnative_microscope.so => /Users/Bene/Dropbox/Dokumente/OpticalDesign/Beamerscope/Android/BeamerscopeIlloptimization/holoscope/build/intermediates/ndkBuild/debug/lib/armeabi/libnative_microscope.so"
install -p /Users/Bene/Dropbox/Dokumente/OpticalDesign/Beamerscope/Android/BeamerscopeIlloptimization/holoscope/.externalNativeBuild/ndkBuild/debug/obj/local/armeabi/libnative_microscope.so /Users/Bene/Dropbox/Dokumente/OpticalDesign/Beamerscope/Android/BeamerscopeIlloptimization/holoscope/build/intermediates/ndkBuild/debug/lib/armeabi/libnative_microscope.so
/Users/Bene/Library/Android/sdk/ndk-bundle/toolchains/arm-linux-androideabi-4.9/prebuilt/darwin-x86_64/bin/arm-linux-androideabi-strip --strip-unneeded  /Users/Bene/Dropbox/Dokumente/OpticalDesign/Beamerscope/Android/BeamerscopeIlloptimization/holoscope/build/intermediates/ndkBuild/debug/lib/armeabi/libnative_microscope.so
echo [armeabi] "Install        ": "libopencv_java3.so => /Users/Bene/Dropbox/Dokumente/OpticalDesign/Beamerscope/Android/BeamerscopeIlloptimization/holoscope/build/intermediates/ndkBuild/debug/lib/armeabi/libopencv_java3.so"
install -p /Users/Bene/Dropbox/Dokumente/OpticalDesign/Beamerscope/Android/BeamerscopeIlloptimization/holoscope/.externalNativeBuild/ndkBuild/debug/obj/local/armeabi/libopencv_java3.so /Users/Bene/Dropbox/Dokumente/OpticalDesign/Beamerscope/Android/BeamerscopeIlloptimization/holoscope/build/intermediates/ndkBuild/debug/lib/armeabi/libopencv_java3.so
/Users/Bene/Library/Android/sdk/ndk-bundle/toolchains/arm-linux-androideabi-4.9/prebuilt/darwin-x86_64/bin/arm-linux-androideabi-strip --strip-unneeded  /Users/Bene/Dropbox/Dokumente/OpticalDesign/Beamerscope/Android/BeamerscopeIlloptimization/holoscope/build/intermediates/ndkBuild/debug/lib/armeabi/libopencv_java3.so

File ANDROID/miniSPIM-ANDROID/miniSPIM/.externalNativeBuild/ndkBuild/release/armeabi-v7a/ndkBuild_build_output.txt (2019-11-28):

rm -f /Users/Bene/Dropbox/Dokumente/OpticalDesign/Beamerscope/Android/BeamerscopeIlloptimization/holoscope/build/intermediates/ndkBuild/release/lib/armeabi-v7a/lib*.so
rm -f /Users/Bene/Dropbox/Dokumente/OpticalDesign/Beamerscope/Android/BeamerscopeIlloptimization/holoscope/build/intermediates/ndkBuild/release/lib/armeabi-v7a/gdbserver
rm -f /Users/Bene/Dropbox/Dokumente/OpticalDesign/Beamerscope/Android/BeamerscopeIlloptimization/holoscope/build/intermediates/ndkBuild/release/lib/armeabi-v7a/gdb.setup
mkdir -p /Users/Bene/Dropbox/Dokumente/OpticalDesign/Beamerscope/Android/BeamerscopeIlloptimization/holoscope/.externalNativeBuild/ndkBuild/release/obj/local/armeabi-v7a/objs/native_microscope
echo [armeabi-v7a] "Compile++ thumb": "native_microscope <= cvComplex.cpp"
/Users/Bene/Library/Android/sdk/ndk-bundle/toolchains/arm-linux-androideabi-4.9/prebuilt/darwin-x86_64/bin/arm-linux-androideabi-g++ -MMD -MP -MF /Users/Bene/Dropbox/Dokumente/OpticalDesign/Beamerscope/Android/BeamerscopeIlloptimization/holoscope/.externalNativeBuild/ndkBuild/release/obj/local/armeabi-v7a/objs/native_microscope/cvComplex.o.d -fpic -ffunction-sections -funwind-tables -fstack-protector-strong -no-canonical-prefixes  -g -march=armv7-a -mfpu=vfpv3-d16 -mfloat-abi=softfp  -fno-exceptions -fno-rtti -mthumb -Os -DNDEBUG  -I"/Users/Bene/Android/opencv3/sdk/native/jni/include/opencv" -I"/Users/Bene/Android/opencv3/sdk/native/jni/include" -I/Users/Bene/Android/opencv3/sdk/native/jni/include/ -I/Users/Bene/Dropbox/Dokumente/OpticalDesign/Beamerscope/Android/BeamerscopeIlloptimization/holoscope/src/main/jni -I/Users/Bene/Library/Android/sdk/ndk-bundle/sources/cxx-stl/gnu-libstdc++/4.9/include -I/Users/Bene/Library/Android/sdk/ndk-bundle/sources/cxx-stl/gnu-libstdc++/4.9/libs/armeabi-v7a/include -I/Users/Bene/Library/Android/sdk/ndk-bundle/sources/cxx-stl/gnu-libstdc++/4.9/include/backward -I/Users/Bene/Dropbox/Dokumente/OpticalDesign/Beamerscope/Android/BeamerscopeIlloptimization/holoscope/src/main/jni -DANDROID -fPIC -DANDROID -fsigned-char -Wa,--noexecstack -Wformat -Werror=format-security    -frtti -fexceptions  -isystem /Users/Bene/Library/Android/sdk/ndk-bundle/platforms/android-19/arch-arm/usr/include -c  /Users/Bene/Dropbox/Dokumente/OpticalDesign/Beamerscope/Android/BeamerscopeIlloptimization/holoscope/src/main/jni/cvComplex.cpp -o /Users/Bene/Dropbox/Dokumente/OpticalDesign/Beamerscope/Android/BeamerscopeIlloptimization/holoscope/.externalNativeBuild/ndkBuild/release/obj/local/armeabi-v7a/objs/native_microscope/cvComplex.o 
echo [armeabi-v7a] "Compile++ thumb": "native_microscope <= common.cpp"
/Users/Bene/Library/Android/sdk/ndk-bundle/toolchains/arm-linux-androideabi-4.9/prebuilt/darwin-x86_64/bin/arm-linux-androideabi-g++ -MMD -MP -MF /Users/Bene/Dropbox/Dokumente/OpticalDesign/Beamerscope/Android/BeamerscopeIlloptimization/holoscope/.externalNativeBuild/ndkBuild/release/obj/local/armeabi-v7a/objs/native_microscope/common.o.d -fpic -ffunction-sections -funwind-tables -fstack-protector-strong -no-canonical-prefixes  -g -march=armv7-a -mfpu=vfpv3-d16 -mfloat-abi=softfp  -fno-exceptions -fno-rtti -mthumb -Os -DNDEBUG  -I"/Users/Bene/Android/opencv3/sdk/native/jni/include/opencv" -I"/Users/Bene/Android/opencv3/sdk/native/jni/include" -I/Users/Bene/Android/opencv3/sdk/native/jni/include/ -I/Users/Bene/Dropbox/Dokumente/OpticalDesign/Beamerscope/Android/BeamerscopeIlloptimization/holoscope/src/main/jni -I/Users/Bene/Library/Android/sdk/ndk-bundle/sources/cxx-stl/gnu-libstdc++/4.9/include -I/Users/Bene/Library/Android/sdk/ndk-bundle/sources/cxx-stl/gnu-libstdc++/4.9/libs/armeabi-v7a/include -I/Users/Bene/Library/Android/sdk/ndk-bundle/sources/cxx-stl/gnu-libstdc++/4.9/include/backward -I/Users/Bene/Dropbox/Dokumente/OpticalDesign/Beamerscope/Android/BeamerscopeIlloptimization/holoscope/src/main/jni -DANDROID -fPIC -DANDROID -fsigned-char -Wa,--noexecstack -Wformat -Werror=format-security    -frtti -fexceptions  -isystem /Users/Bene/Library/Android/sdk/ndk-bundle/platforms/android-19/arch-arm/usr/include -c  /Users/Bene/Dropbox/Dokumente/OpticalDesign/Beamerscope/Android/BeamerscopeIlloptimization/holoscope/src/main/jni/common.cpp -o /Users/Bene/Dropbox/Dokumente/OpticalDesign/Beamerscope/Android/BeamerscopeIlloptimization/holoscope/.externalNativeBuild/ndkBuild/release/obj/local/armeabi-v7a/objs/native_microscope/common.o 
echo [armeabi-v7a] "Compile++ thumb": "native_microscope <= jni_qDPC.cpp"
/Users/Bene/Library/Android/sdk/ndk-bundle/toolchains/arm-linux-androideabi-4.9/prebuilt/darwin-x86_64/bin/arm-linux-androideabi-g++ -MMD -MP -MF /Users/Bene/Dropbox/Dokumente/OpticalDesign/Beamerscope/Android/BeamerscopeIlloptimization/holoscope/.externalNativeBuild/ndkBuild/release/obj/local/armeabi-v7a/objs/native_microscope/jni_qDPC.o.d -fpic -ffunction-sections -funwind-tables -fstack-protector-strong -no-canonical-prefixes  -g -march=armv7-a -mfpu=vfpv3-d16 -mfloat-abi=softfp  -fno-exceptions -fno-rtti -mthumb -Os -DNDEBUG  -I"/Users/Bene/Android/opencv3/sdk/native/jni/include/opencv" -I"/Users/Bene/Android/opencv3/sdk/native/jni/include" -I/Users/Bene/Android/opencv3/sdk/native/jni/include/ -I/Users/Bene/Dropbox/Dokumente/OpticalDesign/Beamerscope/Android/BeamerscopeIlloptimization/holoscope/src/main/jni -I/Users/Bene/Library/Android/sdk/ndk-bundle/sources/cxx-stl/gnu-libstdc++/4.9/include -I/Users/Bene/Library/Android/sdk/ndk-bundle/sources/cxx-stl/gnu-libstdc++/4.9/libs/armeabi-v7a/include -I/Users/Bene/Library/Android/sdk/ndk-bundle/sources/cxx-stl/gnu-libstdc++/4.9/include/backward -I/Users/Bene/Dropbox/Dokumente/OpticalDesign/Beamerscope/Android/BeamerscopeIlloptimization/holoscope/src/main/jni -DANDROID -fPIC -DANDROID -fsigned-char -Wa,--noexecstack -Wformat -Werror=format-security    -frtti -fexceptions  -isystem /Users/Bene/Library/Android/sdk/ndk-bundle/platforms/android-19/arch-arm/usr/include -c  /Users/Bene/Dropbox/Dokumente/OpticalDesign/Beamerscope/Android/BeamerscopeIlloptimization/holoscope/src/main/jni/jni_qDPC.cpp -o /Users/Bene/Dropbox/Dokumente/OpticalDesign/Beamerscope/Android/BeamerscopeIlloptimization/holoscope/.externalNativeBuild/ndkBuild/release/obj/local/armeabi-v7a/objs/native_microscope/jni_qDPC.o 
echo [armeabi-v7a] "Compile++ thumb": "native_microscope <= jni_illpattern.cpp"
/Users/Bene/Library/Android/sdk/ndk-bundle/toolchains/arm-linux-androideabi-4.9/prebuilt/darwin-x86_64/bin/arm-linux-androideabi-g++ -MMD -MP -MF /Users/Bene/Dropbox/Dokumente/OpticalDesign/Beamerscope/Android/BeamerscopeIlloptimization/holoscope/.externalNativeBuild/ndkBuild/release/obj/local/armeabi-v7a/objs/native_microscope/jni_illpattern.o.d -fpic -ffunction-sections -funwind-tables -fstack-protector-strong -no-canonical-prefixes  -g -march=armv7-a -mfpu=vfpv3-d16 -mfloat-abi=softfp  -fno-exceptions -fno-rtti -mthumb -Os -DNDEBUG  -I"/Users/Bene/Android/opencv3/sdk/native/jni/include/opencv" -I"/Users/Bene/Android/opencv3/sdk/native/jni/include" -I/Users/Bene/Android/opencv3/sdk/native/jni/include/ -I/Users/Bene/Dropbox/Dokumente/OpticalDesign/Beamerscope/Android/BeamerscopeIlloptimization/holoscope/src/main/jni -I/Users/Bene/Library/Android/sdk/ndk-bundle/sources/cxx-stl/gnu-libstdc++/4.9/include -I/Users/Bene/Library/Android/sdk/ndk-bundle/sources/cxx-stl/gnu-libstdc++/4.9/libs/armeabi-v7a/include -I/Users/Bene/Library/Android/sdk/ndk-bundle/sources/cxx-stl/gnu-libstdc++/4.9/include/backward -I/Users/Bene/Dropbox/Dokumente/OpticalDesign/Beamerscope/Android/BeamerscopeIlloptimization/holoscope/src/main/jni -DANDROID -fPIC -DANDROID -fsigned-char -Wa,--noexecstack -Wformat -Werror=format-security    -frtti -fexceptions  -isystem /Users/Bene/Library/Android/sdk/ndk-bundle/platforms/android-19/arch-arm/usr/include -c  /Users/Bene/Dropbox/Dokumente/OpticalDesign/Beamerscope/Android/BeamerscopeIlloptimization/holoscope/src/main/jni/jni_illpattern.cpp -o /Users/Bene/Dropbox/Dokumente/OpticalDesign/Beamerscope/Android/BeamerscopeIlloptimization/holoscope/.externalNativeBuild/ndkBuild/release/obj/local/armeabi-v7a/objs/native_microscope/jni_illpattern.o 
echo [armeabi-v7a] "Compile++ thumb": "native_microscope <= jni_illparameter.cpp"
/Users/Bene/Library/Android/sdk/ndk-bundle/toolchains/arm-linux-androideabi-4.9/prebuilt/darwin-x86_64/bin/arm-linux-androideabi-g++ -MMD -MP -MF /Users/Bene/Dropbox/Dokumente/OpticalDesign/Beamerscope/Android/BeamerscopeIlloptimization/holoscope/.externalNativeBuild/ndkBuild/release/obj/local/armeabi-v7a/objs/native_microscope/jni_illparameter.o.d -fpic -ffunction-sections -funwind-tables -fstack-protector-strong -no-canonical-prefixes  -g -march=armv7-a -mfpu=vfpv3-d16 -mfloat-abi=softfp  -fno-exceptions -fno-rtti -mthumb -Os -DNDEBUG  -I"/Users/Bene/Android/opencv3/sdk/native/jni/include/opencv" -I"/Users/Bene/Android/opencv3/sdk/native/jni/include" -I/Users/Bene/Android/opencv3/sdk/native/jni/include/ -I/Users/Bene/Dropbox/Dokumente/OpticalDesign/Beamerscope/Android/BeamerscopeIlloptimization/holoscope/src/main/jni -I/Users/Bene/Library/Android/sdk/ndk-bundle/sources/cxx-stl/gnu-libstdc++/4.9/include -I/Users/Bene/Library/Android/sdk/ndk-bundle/sources/cxx-stl/gnu-libstdc++/4.9/libs/armeabi-v7a/include -I/Users/Bene/Library/Android/sdk/ndk-bundle/sources/cxx-stl/gnu-libstdc++/4.9/include/backward -I/Users/Bene/Dropbox/Dokumente/OpticalDesign/Beamerscope/Android/BeamerscopeIlloptimization/holoscope/src/main/jni -DANDROID -fPIC -DANDROID -fsigned-char -Wa,--noexecstack -Wformat -Werror=format-security    -frtti -fexceptions  -isystem /Users/Bene/Library/Android/sdk/ndk-bundle/platforms/android-19/arch-arm/usr/include -c  /Users/Bene/Dropbox/Dokumente/OpticalDesign/Beamerscope/Android/BeamerscopeIlloptimization/holoscope/src/main/jni/jni_illparameter.cpp -o /Users/Bene/Dropbox/Dokumente/OpticalDesign/Beamerscope/Android/BeamerscopeIlloptimization/holoscope/.externalNativeBuild/ndkBuild/release/obj/local/armeabi-v7a/objs/native_microscope/jni_illparameter.o 
mkdir -p /Users/Bene/Dropbox/Dokumente/OpticalDesign/Beamerscope/Android/BeamerscopeIlloptimization/holoscope/.externalNativeBuild/ndkBuild/release/obj/local/armeabi-v7a
echo [armeabi-v7a] "Prebuilt       ": "libopencv_java3.so <= /Users/Bene/Android/opencv3/sdk/native/jni/../libs/armeabi-v7a/"
cp -f /Users/Bene/Android/opencv3/sdk/native/jni/../libs/armeabi-v7a/libopencv_java3.so /Users/Bene/Dropbox/Dokumente/OpticalDesign/Beamerscope/Android/BeamerscopeIlloptimization/holoscope/.externalNativeBuild/ndkBuild/release/obj/local/armeabi-v7a/libopencv_java3.so
echo [armeabi-v7a] "SharedLibrary  ": "libnative_microscope.so"
/Users/Bene/Library/Android/sdk/ndk-bundle/toolchains/arm-linux-androideabi-4.9/prebuilt/darwin-x86_64/bin/arm-linux-androideabi-g++ -Wl,-soname,libnative_microscope.so -shared --sysroot=/Users/Bene/Library/Android/sdk/ndk-bundle/platforms/android-19/arch-arm /Users/Bene/Dropbox/Dokumente/OpticalDesign/Beamerscope/Android/BeamerscopeIlloptimization/holoscope/.externalNativeBuild/ndkBuild/release/obj/local/armeabi-v7a/objs/native_microscope/cvComplex.o /Users/Bene/Dropbox/Dokumente/OpticalDesign/Beamerscope/Android/BeamerscopeIlloptimization/holoscope/.externalNativeBuild/ndkBuild/release/obj/local/armeabi-v7a/objs/native_microscope/common.o /Users/Bene/Dropbox/Dokumente/OpticalDesign/Beamerscope/Android/BeamerscopeIlloptimization/holoscope/.externalNativeBuild/ndkBuild/release/obj/local/armeabi-v7a/objs/native_microscope/jni_qDPC.o /Users/Bene/Dropbox/Dokumente/OpticalDesign/Beamerscope/Android/BeamerscopeIlloptimization/holoscope/.externalNativeBuild/ndkBuild/release/obj/local/armeabi-v7a/objs/native_microscope/jni_illpattern.o /Users/Bene/Dropbox/Dokumente/OpticalDesign/Beamerscope/Android/BeamerscopeIlloptimization/holoscope/.externalNativeBuild/ndkBuild/release/obj/local/armeabi-v7a/objs/native_microscope/jni_illparameter.o /Users/Bene/Library/Android/sdk/ndk-bundle/sources/cxx-stl/gnu-libstdc++/4.9/libs/armeabi-v7a/libgnustl_static.a -lgcc /Users/Bene/Dropbox/Dokumente/OpticalDesign/Beamerscope/Android/BeamerscopeIlloptimization/holoscope/.externalNativeBuild/ndkBuild/release/obj/local/armeabi-v7a/libopencv_java3.so -no-canonical-prefixes -march=armv7-a -Wl,--fix-cortex-a8   -Wl,--build-id -Wl,--no-undefined -Wl,-z,noexecstack -Wl,-z,relro -Wl,-z,now -Wl,--warn-shared-textrel -Wl,--fatal-warnings   -L/Users/Bene/Library/Android/sdk/ndk-bundle/platforms/android-19/arch-arm/usr/lib -llog -ldl -lc -lm -o /Users/Bene/Dropbox/Dokumente/OpticalDesign/Beamerscope/Android/BeamerscopeIlloptimization/holoscope/.externalNativeBuild/ndkBuild/release/obj/local/armeabi-v7a/libnative_microscope.so
mkdir -p /Users/Bene/Dropbox/Dokumente/OpticalDesign/Beamerscope/Android/BeamerscopeIlloptimization/holoscope/build/intermediates/ndkBuild/release/lib/armeabi-v7a
echo [armeabi-v7a] "Install        ": "libnative_microscope.so => /Users/Bene/Dropbox/Dokumente/OpticalDesign/Beamerscope/Android/BeamerscopeIlloptimization/holoscope/build/intermediates/ndkBuild/release/lib/armeabi-v7a/libnative_microscope.so"
install -p /Users/Bene/Dropbox/Dokumente/OpticalDesign/Beamerscope/Android/BeamerscopeIlloptimization/holoscope/.externalNativeBuild/ndkBuild/release/obj/local/armeabi-v7a/libnative_microscope.so /Users/Bene/Dropbox/Dokumente/OpticalDesign/Beamerscope/Android/BeamerscopeIlloptimization/holoscope/build/intermediates/ndkBuild/release/lib/armeabi-v7a/libnative_microscope.so
/Users/Bene/Library/Android/sdk/ndk-bundle/toolchains/arm-linux-androideabi-4.9/prebuilt/darwin-x86_64/bin/arm-linux-androideabi-strip --strip-unneeded  /Users/Bene/Dropbox/Dokumente/OpticalDesign/Beamerscope/Android/BeamerscopeIlloptimization/holoscope/build/intermediates/ndkBuild/release/lib/armeabi-v7a/libnative_microscope.so
echo [armeabi-v7a] "Install        ": "libopencv_java3.so => /Users/Bene/Dropbox/Dokumente/OpticalDesign/Beamerscope/Android/BeamerscopeIlloptimization/holoscope/build/intermediates/ndkBuild/release/lib/armeabi-v7a/libopencv_java3.so"
install -p /Users/Bene/Dropbox/Dokumente/OpticalDesign/Beamerscope/Android/BeamerscopeIlloptimization/holoscope/.externalNativeBuild/ndkBuild/release/obj/local/armeabi-v7a/libopencv_java3.so /Users/Bene/Dropbox/Dokumente/OpticalDesign/Beamerscope/Android/BeamerscopeIlloptimization/holoscope/build/intermediates/ndkBuild/release/lib/armeabi-v7a/libopencv_java3.so
/Users/Bene/Library/Android/sdk/ndk-bundle/toolchains/arm-linux-androideabi-4.9/prebuilt/darwin-x86_64/bin/arm-linux-androideabi-strip --strip-unneeded  /Users/Bene/Dropbox/Dokumente/OpticalDesign/Beamerscope/Android/BeamerscopeIlloptimization/holoscope/build/intermediates/ndkBuild/release/lib/armeabi-v7a/libopencv_java3.so

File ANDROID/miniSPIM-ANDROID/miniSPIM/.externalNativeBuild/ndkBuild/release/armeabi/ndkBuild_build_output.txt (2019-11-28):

rm -f /Users/Bene/Dropbox/Dokumente/OpticalDesign/Beamerscope/Android/BeamerscopeIlloptimization/holoscope/build/intermediates/ndkBuild/release/lib/armeabi/lib*.so
rm -f /Users/Bene/Dropbox/Dokumente/OpticalDesign/Beamerscope/Android/BeamerscopeIlloptimization/holoscope/build/intermediates/ndkBuild/release/lib/armeabi/gdbserver
rm -f /Users/Bene/Dropbox/Dokumente/OpticalDesign/Beamerscope/Android/BeamerscopeIlloptimization/holoscope/build/intermediates/ndkBuild/release/lib/armeabi/gdb.setup
mkdir -p /Users/Bene/Dropbox/Dokumente/OpticalDesign/Beamerscope/Android/BeamerscopeIlloptimization/holoscope/.externalNativeBuild/ndkBuild/release/obj/local/armeabi/objs/native_microscope
echo [armeabi] "Compile++ thumb": "native_microscope <= cvComplex.cpp"
/Users/Bene/Library/Android/sdk/ndk-bundle/toolchains/arm-linux-androideabi-4.9/prebuilt/darwin-x86_64/bin/arm-linux-androideabi-g++ -MMD -MP -MF /Users/Bene/Dropbox/Dokumente/OpticalDesign/Beamerscope/Android/BeamerscopeIlloptimization/holoscope/.externalNativeBuild/ndkBuild/release/obj/local/armeabi/objs/native_microscope/cvComplex.o.d -fpic -ffunction-sections -funwind-tables -fstack-protector-strong -no-canonical-prefixes  -g -march=armv5te -mtune=xscale -msoft-float  -fno-exceptions -fno-rtti -mthumb -Os -DNDEBUG  -I"/Users/Bene/Android/opencv3/sdk/native/jni/include/opencv" -I"/Users/Bene/Android/opencv3/sdk/native/jni/include" -I/Users/Bene/Android/opencv3/sdk/native/jni/include/ -I/Users/Bene/Dropbox/Dokumente/OpticalDesign/Beamerscope/Android/BeamerscopeIlloptimization/holoscope/src/main/jni -I/Users/Bene/Library/Android/sdk/ndk-bundle/sources/cxx-stl/gnu-libstdc++/4.9/include -I/Users/Bene/Library/Android/sdk/ndk-bundle/sources/cxx-stl/gnu-libstdc++/4.9/libs/armeabi/include -I/Users/Bene/Library/Android/sdk/ndk-bundle/sources/cxx-stl/gnu-libstdc++/4.9/include/backward -I/Users/Bene/Dropbox/Dokumente/OpticalDesign/Beamerscope/Android/BeamerscopeIlloptimization/holoscope/src/main/jni -DANDROID -fPIC -DANDROID -fsigned-char -Wa,--noexecstack -Wformat -Werror=format-security    -frtti -fexceptions  -isystem /Users/Bene/Library/Android/sdk/ndk-bundle/platforms/android-19/arch-arm/usr/include -c  /Users/Bene/Dropbox/Dokumente/OpticalDesign/Beamerscope/Android/BeamerscopeIlloptimization/holoscope/src/main/jni/cvComplex.cpp -o /Users/Bene/Dropbox/Dokumente/OpticalDesign/Beamerscope/Android/BeamerscopeIlloptimization/holoscope/.externalNativeBuild/ndkBuild/release/obj/local/armeabi/objs/native_microscope/cvComplex.o 
echo [armeabi] "Compile++ thumb": "native_microscope <= common.cpp"
/Users/Bene/Library/Android/sdk/ndk-bundle/toolchains/arm-linux-androideabi-4.9/prebuilt/darwin-x86_64/bin/arm-linux-androideabi-g++ -MMD -MP -MF /Users/Bene/Dropbox/Dokumente/OpticalDesign/Beamerscope/Android/BeamerscopeIlloptimization/holoscope/.externalNativeBuild/ndkBuild/release/obj/local/armeabi/objs/native_microscope/common.o.d -fpic -ffunction-sections -funwind-tables -fstack-protector-strong -no-canonical-prefixes  -g -march=armv5te -mtune=xscale -msoft-float  -fno-exceptions -fno-rtti -mthumb -Os -DNDEBUG  -I"/Users/Bene/Android/opencv3/sdk/native/jni/include/opencv" -I"/Users/Bene/Android/opencv3/sdk/native/jni/include" -I/Users/Bene/Android/opencv3/sdk/native/jni/include/ -I/Users/Bene/Dropbox/Dokumente/OpticalDesign/Beamerscope/Android/BeamerscopeIlloptimization/holoscope/src/main/jni -I/Users/Bene/Library/Android/sdk/ndk-bundle/sources/cxx-stl/gnu-libstdc++/4.9/include -I/Users/Bene/Library/Android/sdk/ndk-bundle/sources/cxx-stl/gnu-libstdc++/4.9/libs/armeabi/include -I/Users/Bene/Library/Android/sdk/ndk-bundle/sources/cxx-stl/gnu-libstdc++/4.9/include/backward -I/Users/Bene/Dropbox/Dokumente/OpticalDesign/Beamerscope/Android/BeamerscopeIlloptimization/holoscope/src/main/jni -DANDROID -fPIC -DANDROID -fsigned-char -Wa,--noexecstack -Wformat -Werror=format-security    -frtti -fexceptions  -isystem /Users/Bene/Library/Android/sdk/ndk-bundle/platforms/android-19/arch-arm/usr/include -c  /Users/Bene/Dropbox/Dokumente/OpticalDesign/Beamerscope/Android/BeamerscopeIlloptimization/holoscope/src/main/jni/common.cpp -o /Users/Bene/Dropbox/Dokumente/OpticalDesign/Beamerscope/Android/BeamerscopeIlloptimization/holoscope/.externalNativeBuild/ndkBuild/release/obj/local/armeabi/objs/native_microscope/common.o 
echo [armeabi] "Compile++ thumb": "native_microscope <= jni_qDPC.cpp"
/Users/Bene/Library/Android/sdk/ndk-bundle/toolchains/arm-linux-androideabi-4.9/prebuilt/darwin-x86_64/bin/arm-linux-androideabi-g++ -MMD -MP -MF /Users/Bene/Dropbox/Dokumente/OpticalDesign/Beamerscope/Android/BeamerscopeIlloptimization/holoscope/.externalNativeBuild/ndkBuild/release/obj/local/armeabi/objs/native_microscope/jni_qDPC.o.d -fpic -ffunction-sections -funwind-tables -fstack-protector-strong -no-canonical-prefixes  -g -march=armv5te -mtune=xscale -msoft-float  -fno-exceptions -fno-rtti -mthumb -Os -DNDEBUG  -I"/Users/Bene/Android/opencv3/sdk/native/jni/include/opencv" -I"/Users/Bene/Android/opencv3/sdk/native/jni/include" -I/Users/Bene/Android/opencv3/sdk/native/jni/include/ -I/Users/Bene/Dropbox/Dokumente/OpticalDesign/Beamerscope/Android/BeamerscopeIlloptimization/holoscope/src/main/jni -I/Users/Bene/Library/Android/sdk/ndk-bundle/sources/cxx-stl/gnu-libstdc++/4.9/include -I/Users/Bene/Library/Android/sdk/ndk-bundle/sources/cxx-stl/gnu-libstdc++/4.9/libs/armeabi/include -I/Users/Bene/Library/Android/sdk/ndk-bundle/sources/cxx-stl/gnu-libstdc++/4.9/include/backward -I/Users/Bene/Dropbox/Dokumente/OpticalDesign/Beamerscope/Android/BeamerscopeIlloptimization/holoscope/src/main/jni -DANDROID -fPIC -DANDROID -fsigned-char -Wa,--noexecstack -Wformat -Werror=format-security    -frtti -fexceptions  -isystem /Users/Bene/Library/Android/sdk/ndk-bundle/platforms/android-19/arch-arm/usr/include -c  /Users/Bene/Dropbox/Dokumente/OpticalDesign/Beamerscope/Android/BeamerscopeIlloptimization/holoscope/src/main/jni/jni_qDPC.cpp -o /Users/Bene/Dropbox/Dokumente/OpticalDesign/Beamerscope/Android/BeamerscopeIlloptimization/holoscope/.externalNativeBuild/ndkBuild/release/obj/local/armeabi/objs/native_microscope/jni_qDPC.o 
echo [armeabi] "Compile++ thumb": "native_microscope <= jni_illpattern.cpp"
/Users/Bene/Library/Android/sdk/ndk-bundle/toolchains/arm-linux-androideabi-4.9/prebuilt/darwin-x86_64/bin/arm-linux-androideabi-g++ -MMD -MP -MF /Users/Bene/Dropbox/Dokumente/OpticalDesign/Beamerscope/Android/BeamerscopeIlloptimization/holoscope/.externalNativeBuild/ndkBuild/release/obj/local/armeabi/objs/native_microscope/jni_illpattern.o.d -fpic -ffunction-sections -funwind-tables -fstack-protector-strong -no-canonical-prefixes  -g -march=armv5te -mtune=xscale -msoft-float  -fno-exceptions -fno-rtti -mthumb -Os -DNDEBUG  -I"/Users/Bene/Android/opencv3/sdk/native/jni/include/opencv" -I"/Users/Bene/Android/opencv3/sdk/native/jni/include" -I/Users/Bene/Android/opencv3/sdk/native/jni/include/ -I/Users/Bene/Dropbox/Dokumente/OpticalDesign/Beamerscope/Android/BeamerscopeIlloptimization/holoscope/src/main/jni -I/Users/Bene/Library/Android/sdk/ndk-bundle/sources/cxx-stl/gnu-libstdc++/4.9/include -I/Users/Bene/Library/Android/sdk/ndk-bundle/sources/cxx-stl/gnu-libstdc++/4.9/libs/armeabi/include -I/Users/Bene/Library/Android/sdk/ndk-bundle/sources/cxx-stl/gnu-libstdc++/4.9/include/backward -I/Users/Bene/Dropbox/Dokumente/OpticalDesign/Beamerscope/Android/BeamerscopeIlloptimization/holoscope/src/main/jni -DANDROID -fPIC -DANDROID -fsigned-char -Wa,--noexecstack -Wformat -Werror=format-security    -frtti -fexceptions  -isystem /Users/Bene/Library/Android/sdk/ndk-bundle/platforms/android-19/arch-arm/usr/include -c  /Users/Bene/Dropbox/Dokumente/OpticalDesign/Beamerscope/Android/BeamerscopeIlloptimization/holoscope/src/main/jni/jni_illpattern.cpp -o /Users/Bene/Dropbox/Dokumente/OpticalDesign/Beamerscope/Android/BeamerscopeIlloptimization/holoscope/.externalNativeBuild/ndkBuild/release/obj/local/armeabi/objs/native_microscope/jni_illpattern.o 
echo [armeabi] "Compile++ thumb": "native_microscope <= jni_illparameter.cpp"
/Users/Bene/Library/Android/sdk/ndk-bundle/toolchains/arm-linux-androideabi-4.9/prebuilt/darwin-x86_64/bin/arm-linux-androideabi-g++ -MMD -MP -MF /Users/Bene/Dropbox/Dokumente/OpticalDesign/Beamerscope/Android/BeamerscopeIlloptimization/holoscope/.externalNativeBuild/ndkBuild/release/obj/local/armeabi/objs/native_microscope/jni_illparameter.o.d -fpic -ffunction-sections -funwind-tables -fstack-protector-strong -no-canonical-prefixes  -g -march=armv5te -mtune=xscale -msoft-float  -fno-exceptions -fno-rtti -mthumb -Os -DNDEBUG  -I"/Users/Bene/Android/opencv3/sdk/native/jni/include/opencv" -I"/Users/Bene/Android/opencv3/sdk/native/jni/include" -I/Users/Bene/Android/opencv3/sdk/native/jni/include/ -I/Users/Bene/Dropbox/Dokumente/OpticalDesign/Beamerscope/Android/BeamerscopeIlloptimization/holoscope/src/main/jni -I/Users/Bene/Library/Android/sdk/ndk-bundle/sources/cxx-stl/gnu-libstdc++/4.9/include -I/Users/Bene/Library/Android/sdk/ndk-bundle/sources/cxx-stl/gnu-libstdc++/4.9/libs/armeabi/include -I/Users/Bene/Library/Android/sdk/ndk-bundle/sources/cxx-stl/gnu-libstdc++/4.9/include/backward -I/Users/Bene/Dropbox/Dokumente/OpticalDesign/Beamerscope/Android/BeamerscopeIlloptimization/holoscope/src/main/jni -DANDROID -fPIC -DANDROID -fsigned-char -Wa,--noexecstack -Wformat -Werror=format-security    -frtti -fexceptions  -isystem /Users/Bene/Library/Android/sdk/ndk-bundle/platforms/android-19/arch-arm/usr/include -c  /Users/Bene/Dropbox/Dokumente/OpticalDesign/Beamerscope/Android/BeamerscopeIlloptimization/holoscope/src/main/jni/jni_illparameter.cpp -o /Users/Bene/Dropbox/Dokumente/OpticalDesign/Beamerscope/Android/BeamerscopeIlloptimization/holoscope/.externalNativeBuild/ndkBuild/release/obj/local/armeabi/objs/native_microscope/jni_illparameter.o 
mkdir -p /Users/Bene/Dropbox/Dokumente/OpticalDesign/Beamerscope/Android/BeamerscopeIlloptimization/holoscope/.externalNativeBuild/ndkBuild/release/obj/local/armeabi
echo [armeabi] "Prebuilt       ": "libopencv_java3.so <= /Users/Bene/Android/opencv3/sdk/native/jni/../libs/armeabi/"
cp -f /Users/Bene/Android/opencv3/sdk/native/jni/../libs/armeabi/libopencv_java3.so /Users/Bene/Dropbox/Dokumente/OpticalDesign/Beamerscope/Android/BeamerscopeIlloptimization/holoscope/.externalNativeBuild/ndkBuild/release/obj/local/armeabi/libopencv_java3.so
echo [armeabi] "SharedLibrary  ": "libnative_microscope.so"
/Users/Bene/Library/Android/sdk/ndk-bundle/toolchains/arm-linux-androideabi-4.9/prebuilt/darwin-x86_64/bin/arm-linux-androideabi-g++ -Wl,-soname,libnative_microscope.so -shared --sysroot=/Users/Bene/Library/Android/sdk/ndk-bundle/platforms/android-19/arch-arm /Users/Bene/Dropbox/Dokumente/OpticalDesign/Beamerscope/Android/BeamerscopeIlloptimization/holoscope/.externalNativeBuild/ndkBuild/release/obj/local/armeabi/objs/native_microscope/cvComplex.o /Users/Bene/Dropbox/Dokumente/OpticalDesign/Beamerscope/Android/BeamerscopeIlloptimization/holoscope/.externalNativeBuild/ndkBuild/release/obj/local/armeabi/objs/native_microscope/common.o /Users/Bene/Dropbox/Dokumente/OpticalDesign/Beamerscope/Android/BeamerscopeIlloptimization/holoscope/.externalNativeBuild/ndkBuild/release/obj/local/armeabi/objs/native_microscope/jni_qDPC.o /Users/Bene/Dropbox/Dokumente/OpticalDesign/Beamerscope/Android/BeamerscopeIlloptimization/holoscope/.externalNativeBuild/ndkBuild/release/obj/local/armeabi/objs/native_microscope/jni_illpattern.o /Users/Bene/Dropbox/Dokumente/OpticalDesign/Beamerscope/Android/BeamerscopeIlloptimization/holoscope/.externalNativeBuild/ndkBuild/release/obj/local/armeabi/objs/native_microscope/jni_illparameter.o /Users/Bene/Library/Android/sdk/ndk-bundle/sources/cxx-stl/gnu-libstdc++/4.9/libs/armeabi/libgnustl_static.a -lgcc /Users/Bene/Dropbox/Dokumente/OpticalDesign/Beamerscope/Android/BeamerscopeIlloptimization/holoscope/.externalNativeBuild/ndkBuild/release/obj/local/armeabi/libopencv_java3.so -no-canonical-prefixes  -Wl,--build-id -Wl,--no-undefined -Wl,-z,noexecstack -Wl,-z,relro -Wl,-z,now -Wl,--warn-shared-textrel -Wl,--fatal-warnings   -L/Users/Bene/Library/Android/sdk/ndk-bundle/platforms/android-19/arch-arm/usr/lib -llog -ldl -lc -lm -o /Users/Bene/Dropbox/Dokumente/OpticalDesign/Beamerscope/Android/BeamerscopeIlloptimization/holoscope/.externalNativeBuild/ndkBuild/release/obj/local/armeabi/libnative_microscope.so
mkdir -p /Users/Bene/Dropbox/Dokumente/OpticalDesign/Beamerscope/Android/BeamerscopeIlloptimization/holoscope/build/intermediates/ndkBuild/release/lib/armeabi
echo [armeabi] "Install        ": "libnative_microscope.so => /Users/Bene/Dropbox/Dokumente/OpticalDesign/Beamerscope/Android/BeamerscopeIlloptimization/holoscope/build/intermediates/ndkBuild/release/lib/armeabi/libnative_microscope.so"
install -p /Users/Bene/Dropbox/Dokumente/OpticalDesign/Beamerscope/Android/BeamerscopeIlloptimization/holoscope/.externalNativeBuild/ndkBuild/release/obj/local/armeabi/libnative_microscope.so /Users/Bene/Dropbox/Dokumente/OpticalDesign/Beamerscope/Android/BeamerscopeIlloptimization/holoscope/build/intermediates/ndkBuild/release/lib/armeabi/libnative_microscope.so
/Users/Bene/Library/Android/sdk/ndk-bundle/toolchains/arm-linux-androideabi-4.9/prebuilt/darwin-x86_64/bin/arm-linux-androideabi-strip --strip-unneeded  /Users/Bene/Dropbox/Dokumente/OpticalDesign/Beamerscope/Android/BeamerscopeIlloptimization/holoscope/build/intermediates/ndkBuild/release/lib/armeabi/libnative_microscope.so
echo [armeabi] "Install        ": "libopencv_java3.so => /Users/Bene/Dropbox/Dokumente/OpticalDesign/Beamerscope/Android/BeamerscopeIlloptimization/holoscope/build/intermediates/ndkBuild/release/lib/armeabi/libopencv_java3.so"
install -p /Users/Bene/Dropbox/Dokumente/OpticalDesign/Beamerscope/Android/BeamerscopeIlloptimization/holoscope/.externalNativeBuild/ndkBuild/release/obj/local/armeabi/libopencv_java3.so /Users/Bene/Dropbox/Dokumente/OpticalDesign/Beamerscope/Android/BeamerscopeIlloptimization/holoscope/build/intermediates/ndkBuild/release/lib/armeabi/libopencv_java3.so
/Users/Bene/Library/Android/sdk/ndk-bundle/toolchains/arm-linux-androideabi-4.9/prebuilt/darwin-x86_64/bin/arm-linux-androideabi-strip --strip-unneeded  /Users/Bene/Dropbox/Dokumente/OpticalDesign/Beamerscope/Android/BeamerscopeIlloptimization/holoscope/build/intermediates/ndkBuild/release/lib/armeabi/libopencv_java3.so

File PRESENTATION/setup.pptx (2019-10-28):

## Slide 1

Lens

Objective

Projector

XY-Stage

Cellphone

Mirror

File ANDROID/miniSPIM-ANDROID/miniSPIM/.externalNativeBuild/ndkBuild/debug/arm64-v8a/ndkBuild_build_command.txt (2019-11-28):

Executable : /Users/Bene/Library/Android/sdk/ndk-bundle/ndk-build
arguments : 
NDK_PROJECT_PATH=null
APP_BUILD_SCRIPT=/Users/Bene/Dropbox/Dokumente/OpticalDesign/Beamerscope/Android/BeamerscopeIlloptimization/holoscope/src/main/jni/Android.mk
NDK_APPLICATION_MK=/Users/Bene/Dropbox/Dokumente/OpticalDesign/Beamerscope/Android/BeamerscopeIlloptimization/holoscope/src/main/jni/Application.mk
APP_ABI=arm64-v8a
NDK_ALL_ABIS=arm64-v8a
NDEBUG=1
APP_PLATFORM=android-21
NDK_OUT=/Users/Bene/Dropbox/Dokumente/OpticalDesign/Beamerscope/Android/BeamerscopeIlloptimization/holoscope/.externalNativeBuild/ndkBuild/debug/obj
NDK_LIBS_OUT=/Users/Bene/Dropbox/Dokumente/OpticalDesign/Beamerscope/Android/BeamerscopeIlloptimization/holoscope/build/intermediates/ndkBuild/debug/lib
-n
jvmArgs :

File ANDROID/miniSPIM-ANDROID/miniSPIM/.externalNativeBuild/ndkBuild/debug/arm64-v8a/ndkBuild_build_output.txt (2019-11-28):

rm -f /Users/Bene/Dropbox/Dokumente/OpticalDesign/Beamerscope/Android/BeamerscopeIlloptimization/holoscope/build/intermediates/ndkBuild/debug/lib/arm64-v8a/lib*.so
rm -f /Users/Bene/Dropbox/Dokumente/OpticalDesign/Beamerscope/Android/BeamerscopeIlloptimization/holoscope/build/intermediates/ndkBuild/debug/lib/arm64-v8a/gdbserver
rm -f /Users/Bene/Dropbox/Dokumente/OpticalDesign/Beamerscope/Android/BeamerscopeIlloptimization/holoscope/build/intermediates/ndkBuild/debug/lib/arm64-v8a/gdb.setup
echo [arm64-v8a] "Compile++      ": "native_microscope <= cvComplex.cpp"
/Users/Bene/Library/Android/sdk/ndk-bundle/toolchains/aarch64-linux-android-4.9/prebuilt/darwin-x86_64/bin/aarch64-linux-android-g++ -MMD -MP -MF /Users/Bene/Dropbox/Dokumente/OpticalDesign/Beamerscope/Android/BeamerscopeIlloptimization/holoscope/.externalNativeBuild/ndkBuild/debug/obj/local/arm64-v8a/objs/native_microscope/cvComplex.o.d -fpic -ffunction-sections -funwind-tables -fstack-protector-strong -no-canonical-prefixes  -g -fno-exceptions -fno-rtti -O2 -DNDEBUG  -I"/Users/Bene/Android/opencv3/sdk/native/jni/include/opencv" -I"/Users/Bene/Android/opencv3/sdk/native/jni/include" -I/Users/Bene/Android/opencv3/sdk/native/jni/include/ -I/Users/Bene/Dropbox/Dokumente/OpticalDesign/Beamerscope/Android/BeamerscopeIlloptimization/holoscope/src/main/jni -I/Users/Bene/Library/Android/sdk/ndk-bundle/sources/cxx-stl/gnu-libstdc++/4.9/include -I/Users/Bene/Library/Android/sdk/ndk-bundle/sources/cxx-stl/gnu-libstdc++/4.9/libs/arm64-v8a/include -I/Users/Bene/Library/Android/sdk/ndk-bundle/sources/cxx-stl/gnu-libstdc++/4.9/include/backward -I/Users/Bene/Dropbox/Dokumente/OpticalDesign/Beamerscope/Android/BeamerscopeIlloptimization/holoscope/src/main/jni -DANDROID -fPIC -DANDROID -fsigned-char -Wa,--noexecstack -Wformat -Werror=format-security    -frtti -fexceptions  -isystem /Users/Bene/Library/Android/sdk/ndk-bundle/platforms/android-21/arch-arm64/usr/include -c  /Users/Bene/Dropbox/Dokumente/OpticalDesign/Beamerscope/Android/BeamerscopeIlloptimization/holoscope/src/main/jni/cvComplex.cpp -o /Users/Bene/Dropbox/Dokumente/OpticalDesign/Beamerscope/Android/BeamerscopeIlloptimization/holoscope/.externalNativeBuild/ndkBuild/debug/obj/local/arm64-v8a/objs/native_microscope/cvComplex.o 
echo [arm64-v8a] "Compile++      ": "native_microscope <= common.cpp"
/Users/Bene/Library/Android/sdk/ndk-bundle/toolchains/aarch64-linux-android-4.9/prebuilt/darwin-x86_64/bin/aarch64-linux-android-g++ -MMD -MP -MF /Users/Bene/Dropbox/Dokumente/OpticalDesign/Beamerscope/Android/BeamerscopeIlloptimization/holoscope/.externalNativeBuild/ndkBuild/debug/obj/local/arm64-v8a/objs/native_microscope/common.o.d -fpic -ffunction-sections -funwind-tables -fstack-protector-strong -no-canonical-prefixes  -g -fno-exceptions -fno-rtti -O2 -DNDEBUG  -I"/Users/Bene/Android/opencv3/sdk/native/jni/include/opencv" -I"/Users/Bene/Android/opencv3/sdk/native/jni/include" -I/Users/Bene/Android/opencv3/sdk/native/jni/include/ -I/Users/Bene/Dropbox/Dokumente/OpticalDesign/Beamerscope/Android/BeamerscopeIlloptimization/holoscope/src/main/jni -I/Users/Bene/Library/Android/sdk/ndk-bundle/sources/cxx-stl/gnu-libstdc++/4.9/include -I/Users/Bene/Library/Android/sdk/ndk-bundle/sources/cxx-stl/gnu-libstdc++/4.9/libs/arm64-v8a/include -I/Users/Bene/Library/Android/sdk/ndk-bundle/sources/cxx-stl/gnu-libstdc++/4.9/include/backward -I/Users/Bene/Dropbox/Dokumente/OpticalDesign/Beamerscope/Android/BeamerscopeIlloptimization/holoscope/src/main/jni -DANDROID -fPIC -DANDROID -fsigned-char -Wa,--noexecstack -Wformat -Werror=format-security    -frtti -fexceptions  -isystem /Users/Bene/Library/Android/sdk/ndk-bundle/platforms/android-21/arch-arm64/usr/include -c  /Users/Bene/Dropbox/Dokumente/OpticalDesign/Beamerscope/Android/BeamerscopeIlloptimization/holoscope/src/main/jni/common.cpp -o /Users/Bene/Dropbox/Dokumente/OpticalDesign/Beamerscope/Android/BeamerscopeIlloptimization/holoscope/.externalNativeBuild/ndkBuild/debug/obj/local/arm64-v8a/objs/native_microscope/common.o 
echo [arm64-v8a] "Compile++      ": "native_microscope <= jni_qDPC.cpp"
/Users/Bene/Library/Android/sdk/ndk-bundle/toolchains/aarch64-linux-android-4.9/prebuilt/darwin-x86_64/bin/aarch64-linux-android-g++ -MMD -MP -MF /Users/Bene/Dropbox/Dokumente/OpticalDesign/Beamerscope/Android/BeamerscopeIlloptimization/holoscope/.externalNativeBuild/ndkBuild/debug/obj/local/arm64-v8a/objs/native_microscope/jni_qDPC.o.d -fpic -ffunction-sections -funwind-tables -fstack-protector-strong -no-canonical-prefixes  -g -fno-exceptions -fno-rtti -O2 -DNDEBUG  -I"/Users/Bene/Android/opencv3/sdk/native/jni/include/opencv" -I"/Users/Bene/Android/opencv3/sdk/native/jni/include" -I/Users/Bene/Android/opencv3/sdk/native/jni/include/ -I/Users/Bene/Dropbox/Dokumente/OpticalDesign/Beamerscope/Android/BeamerscopeIlloptimization/holoscope/src/main/jni -I/Users/Bene/Library/Android/sdk/ndk-bundle/sources/cxx-stl/gnu-libstdc++/4.9/include -I/Users/Bene/Library/Android/sdk/ndk-bundle/sources/cxx-stl/gnu-libstdc++/4.9/libs/arm64-v8a/include -I/Users/Bene/Library/Android/sdk/ndk-bundle/sources/cxx-stl/gnu-libstdc++/4.9/include/backward -I/Users/Bene/Dropbox/Dokumente/OpticalDesign/Beamerscope/Android/BeamerscopeIlloptimization/holoscope/src/main/jni -DANDROID -fPIC -DANDROID -fsigned-char -Wa,--noexecstack -Wformat -Werror=format-security    -frtti -fexceptions  -isystem /Users/Bene/Library/Android/sdk/ndk-bundle/platforms/android-21/arch-arm64/usr/include -c  /Users/Bene/Dropbox/Dokumente/OpticalDesign/Beamerscope/Android/BeamerscopeIlloptimization/holoscope/src/main/jni/jni_qDPC.cpp -o /Users/Bene/Dropbox/Dokumente/OpticalDesign/Beamerscope/Android/BeamerscopeIlloptimization/holoscope/.externalNativeBuild/ndkBuild/debug/obj/local/arm64-v8a/objs/native_microscope/jni_qDPC.o 
echo [arm64-v8a] "Compile++      ": "native_microscope <= jni_illpattern.cpp"
/Users/Bene/Library/Android/sdk/ndk-bundle/toolchains/aarch64-linux-android-4.9/prebuilt/darwin-x86_64/bin/aarch64-linux-android-g++ -MMD -MP -MF /Users/Bene/Dropbox/Dokumente/OpticalDesign/Beamerscope/Android/BeamerscopeIlloptimization/holoscope/.externalNativeBuild/ndkBuild/debug/obj/local/arm64-v8a/objs/native_microscope/jni_illpattern.o.d -fpic -ffunction-sections -funwind-tables -fstack-protector-strong -no-canonical-prefixes  -g -fno-exceptions -fno-rtti -O2 -DNDEBUG  -I"/Users/Bene/Android/opencv3/sdk/native/jni/include/opencv" -I"/Users/Bene/Android/opencv3/sdk/native/jni/include" -I/Users/Bene/Android/opencv3/sdk/native/jni/include/ -I/Users/Bene/Dropbox/Dokumente/OpticalDesign/Beamerscope/Android/BeamerscopeIlloptimization/holoscope/src/main/jni -I/Users/Bene/Library/Android/sdk/ndk-bundle/sources/cxx-stl/gnu-libstdc++/4.9/include -I/Users/Bene/Library/Android/sdk/ndk-bundle/sources/cxx-stl/gnu-libstdc++/4.9/libs/arm64-v8a/include -I/Users/Bene/Library/Android/sdk/ndk-bundle/sources/cxx-stl/gnu-libstdc++/4.9/include/backward -I/Users/Bene/Dropbox/Dokumente/OpticalDesign/Beamerscope/Android/BeamerscopeIlloptimization/holoscope/src/main/jni -DANDROID -fPIC -DANDROID -fsigned-char -Wa,--noexecstack -Wformat -Werror=format-security    -frtti -fexceptions  -isystem /Users/Bene/Library/Android/sdk/ndk-bundle/platforms/android-21/arch-arm64/usr/include -c  /Users/Bene/Dropbox/Dokumente/OpticalDesign/Beamerscope/Android/BeamerscopeIlloptimization/holoscope/src/main/jni/jni_illpattern.cpp -o /Users/Bene/Dropbox/Dokumente/OpticalDesign/Beamerscope/Android/BeamerscopeIlloptimization/holoscope/.externalNativeBuild/ndkBuild/debug/obj/local/arm64-v8a/objs/native_microscope/jni_illpattern.o 
echo [arm64-v8a] "Compile++      ": "native_microscope <= jni_illparameter.cpp"
/Users/Bene/Library/Android/sdk/ndk-bundle/toolchains/aarch64-linux-android-4.9/prebuilt/darwin-x86_64/bin/aarch64-linux-android-g++ -MMD -MP -MF /Users/Bene/Dropbox/Dokumente/OpticalDesign/Beamerscope/Android/BeamerscopeIlloptimization/holoscope/.externalNativeBuild/ndkBuild/debug/obj/local/arm64-v8a/objs/native_microscope/jni_illparameter.o.d -fpic -ffunction-sections -funwind-tables -fstack-protector-strong -no-canonical-prefixes  -g -fno-exceptions -fno-rtti -O2 -DNDEBUG  -I"/Users/Bene/Android/opencv3/sdk/native/jni/include/opencv" -I"/Users/Bene/Android/opencv3/sdk/native/jni/include" -I/Users/Bene/Android/opencv3/sdk/native/jni/include/ -I/Users/Bene/Dropbox/Dokumente/OpticalDesign/Beamerscope/Android/BeamerscopeIlloptimization/holoscope/src/main/jni -I/Users/Bene/Library/Android/sdk/ndk-bundle/sources/cxx-stl/gnu-libstdc++/4.9/include -I/Users/Bene/Library/Android/sdk/ndk-bundle/sources/cxx-stl/gnu-libstdc++/4.9/libs/arm64-v8a/include -I/Users/Bene/Library/Android/sdk/ndk-bundle/sources/cxx-stl/gnu-libstdc++/4.9/include/backward -I/Users/Bene/Dropbox/Dokumente/OpticalDesign/Beamerscope/Android/BeamerscopeIlloptimization/holoscope/src/main/jni -DANDROID -fPIC -DANDROID -fsigned-char -Wa,--noexecstack -Wformat -Werror=format-security    -frtti -fexceptions  -isystem /Users/Bene/Library/Android/sdk/ndk-bundle/platforms/android-21/arch-arm64/usr/include -c  /Users/Bene/Dropbox/Dokumente/OpticalDesign/Beamerscope/Android/BeamerscopeIlloptimization/holoscope/src/main/jni/jni_illparameter.cpp -o /Users/Bene/Dropbox/Dokumente/OpticalDesign/Beamerscope/Android/BeamerscopeIlloptimization/holoscope/.externalNativeBuild/ndkBuild/debug/obj/local/arm64-v8a/objs/native_microscope/jni_illparameter.o 
echo [arm64-v8a] "SharedLibrary  ": "libnative_microscope.so"
/Users/Bene/Library/Android/sdk/ndk-bundle/toolchains/aarch64-linux-android-4.9/prebuilt/darwin-x86_64/bin/aarch64-linux-android-g++ -Wl,-soname,libnative_microscope.so -shared --sysroot=/Users/Bene/Library/Android/sdk/ndk-bundle/platforms/android-21/arch-arm64 /Users/Bene/Dropbox/Dokumente/OpticalDesign/Beamerscope/Android/BeamerscopeIlloptimization/holoscope/.externalNativeBuild/ndkBuild/debug/obj/local/arm64-v8a/objs/native_microscope/cvComplex.o /Users/Bene/Dropbox/Dokumente/OpticalDesign/Beamerscope/Android/BeamerscopeIlloptimization/holoscope/.externalNativeBuild/ndkBuild/debug/obj/local/arm64-v8a/objs/native_microscope/common.o /Users/Bene/Dropbox/Dokumente/OpticalDesign/Beamerscope/Android/BeamerscopeIlloptimization/holoscope/.externalNativeBuild/ndkBuild/debug/obj/local/arm64-v8a/objs/native_microscope/jni_qDPC.o /Users/Bene/Dropbox/Dokumente/OpticalDesign/Beamerscope/Android/BeamerscopeIlloptimization/holoscope/.externalNativeBuild/ndkBuild/debug/obj/local/arm64-v8a/objs/native_microscope/jni_illpattern.o /Users/Bene/Dropbox/Dokumente/OpticalDesign/Beamerscope/Android/BeamerscopeIlloptimization/holoscope/.externalNativeBuild/ndkBuild/debug/obj/local/arm64-v8a/objs/native_microscope/jni_illparameter.o /Users/Bene/Library/Android/sdk/ndk-bundle/sources/cxx-stl/gnu-libstdc++/4.9/libs/arm64-v8a/libgnustl_static.a -lgcc /Users/Bene/Dropbox/Dokumente/OpticalDesign/Beamerscope/Android/BeamerscopeIlloptimization/holoscope/.externalNativeBuild/ndkBuild/debug/obj/local/arm64-v8a/libopencv_java3.so -no-canonical-prefixes  -Wl,--build-id -Wl,--no-undefined -Wl,-z,noexecstack -Wl,-z,relro -Wl,-z,now -Wl,--warn-shared-textrel -Wl,--fatal-warnings  -L/Users/Bene/Library/Android/sdk/ndk-bundle/platforms/android-21/arch-arm64/usr/lib -llog -ldl -lc -lm -o /Users/Bene/Dropbox/Dokumente/OpticalDesign/Beamerscope/Android/BeamerscopeIlloptimization/holoscope/.externalNativeBuild/ndkBuild/debug/obj/local/arm64-v8a/libnative_microscope.so
echo [arm64-v8a] "Install        ": "libnative_microscope.so => /Users/Bene/Dropbox/Dokumente/OpticalDesign/Beamerscope/Android/BeamerscopeIlloptimization/holoscope/build/intermediates/ndkBuild/debug/lib/arm64-v8a/libnative_microscope.so"
install -p /Users/Bene/Dropbox/Dokumente/OpticalDesign/Beamerscope/Android/BeamerscopeIlloptimization/holoscope/.externalNativeBuild/ndkBuild/debug/obj/local/arm64-v8a/libnative_microscope.so /Users/Bene/Dropbox/Dokumente/OpticalDesign/Beamerscope/Android/BeamerscopeIlloptimization/holoscope/build/intermediates/ndkBuild/debug/lib/arm64-v8a/libnative_microscope.so
/Users/Bene/Library/Android/sdk/ndk-bundle/toolchains/aarch64-linux-android-4.9/prebuilt/darwin-x86_64/bin/aarch64-linux-android-strip --strip-unneeded  /Users/Bene/Dropbox/Dokumente/OpticalDesign/Beamerscope/Android/BeamerscopeIlloptimization/holoscope/build/intermediates/ndkBuild/debug/lib/arm64-v8a/libnative_microscope.so
echo [arm64-v8a] "Install        ": "libopencv_java3.so => /Users/Bene/Dropbox/Dokumente/OpticalDesign/Beamerscope/Android/BeamerscopeIlloptimization/holoscope/build/intermediates/ndkBuild/debug/lib/arm64-v8a/libopencv_java3.so"
install -p /Users/Bene/Dropbox/Dokumente/OpticalDesign/Beamerscope/Android/BeamerscopeIlloptimization/holoscope/.externalNativeBuild/ndkBuild/debug/obj/local/arm64-v8a/libopencv_java3.so /Users/Bene/Dropbox/Dokumente/OpticalDesign/Beamerscope/Android/BeamerscopeIlloptimization/holoscope/build/intermediates/ndkBuild/debug/lib/arm64-v8a/libopencv_java3.so
/Users/Bene/Library/Android/sdk/ndk-bundle/toolchains/aarch64-linux-android-4.9/prebuilt/darwin-x86_64/bin/aarch64-linux-android-strip --strip-unneeded  /Users/Bene/Dropbox/Dokumente/OpticalDesign/Beamerscope/Android/BeamerscopeIlloptimization/holoscope/build/intermediates/ndkBuild/debug/lib/arm64-v8a/libopencv_java3.so

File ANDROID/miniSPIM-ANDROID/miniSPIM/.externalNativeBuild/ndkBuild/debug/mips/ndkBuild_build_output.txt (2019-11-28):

rm -f /Users/Bene/Dropbox/Dokumente/OpticalDesign/Beamerscope/Android/BeamerscopeIlloptimization/holoscope/build/intermediates/ndkBuild/debug/lib/mips/lib*.so
rm -f /Users/Bene/Dropbox/Dokumente/OpticalDesign/Beamerscope/Android/BeamerscopeIlloptimization/holoscope/build/intermediates/ndkBuild/debug/lib/mips/gdbserver
rm -f /Users/Bene/Dropbox/Dokumente/OpticalDesign/Beamerscope/Android/BeamerscopeIlloptimization/holoscope/build/intermediates/ndkBuild/debug/lib/mips/gdb.setup
echo [mips] "Compile++      ": "native_microscope <= cvComplex.cpp"
/Users/Bene/Library/Android/sdk/ndk-bundle/toolchains/mipsel-linux-android-4.9/prebuilt/darwin-x86_64/bin/mipsel-linux-android-g++ -MMD -MP -MF /Users/Bene/Dropbox/Dokumente/OpticalDesign/Beamerscope/Android/BeamerscopeIlloptimization/holoscope/.externalNativeBuild/ndkBuild/debug/obj/local/mips/objs/native_microscope/cvComplex.o.d -fpic -finline-functions -ffunction-sections -funwind-tables -fstack-protector-strong -fmessage-length=0 -fno-inline-functions-called-once -fgcse-after-reload -frerun-cse-after-loop -frename-registers -no-canonical-prefixes  -g -fno-exceptions -fno-rtti -O2 -DNDEBUG  -I"/Users/Bene/Android/opencv3/sdk/native/jni/include/opencv" -I"/Users/Bene/Android/opencv3/sdk/native/jni/include" -I/Users/Bene/Android/opencv3/sdk/native/jni/include/ -I/Users/Bene/Dropbox/Dokumente/OpticalDesign/Beamerscope/Android/BeamerscopeIlloptimization/holoscope/src/main/jni -I/Users/Bene/Library/Android/sdk/ndk-bundle/sources/cxx-stl/gnu-libstdc++/4.9/include -I/Users/Bene/Library/Android/sdk/ndk-bundle/sources/cxx-stl/gnu-libstdc++/4.9/libs/mips/include -I/Users/Bene/Library/Android/sdk/ndk-bundle/sources/cxx-stl/gnu-libstdc++/4.9/include/backward -I/Users/Bene/Dropbox/Dokumente/OpticalDesign/Beamerscope/Android/BeamerscopeIlloptimization/holoscope/src/main/jni -DANDROID -fPIC -DANDROID -fsigned-char -Wa,--noexecstack -Wformat -Werror=format-security    -frtti -fexceptions  -isystem /Users/Bene/Library/Android/sdk/ndk-bundle/platforms/android-19/arch-mips/usr/include -c  /Users/Bene/Dropbox/Dokumente/OpticalDesign/Beamerscope/Android/BeamerscopeIlloptimization/holoscope/src/main/jni/cvComplex.cpp -o /Users/Bene/Dropbox/Dokumente/OpticalDesign/Beamerscope/Android/BeamerscopeIlloptimization/holoscope/.externalNativeBuild/ndkBuild/debug/obj/local/mips/objs/native_microscope/cvComplex.o 
echo [mips] "Compile++      ": "native_microscope <= common.cpp"
/Users/Bene/Library/Android/sdk/ndk-bundle/toolchains/mipsel-linux-android-4.9/prebuilt/darwin-x86_64/bin/mipsel-linux-android-g++ -MMD -MP -MF /Users/Bene/Dropbox/Dokumente/OpticalDesign/Beamerscope/Android/BeamerscopeIlloptimization/holoscope/.externalNativeBuild/ndkBuild/debug/obj/local/mips/objs/native_microscope/common.o.d -fpic -finline-functions -ffunction-sections -funwind-tables -fstack-protector-strong -fmessage-length=0 -fno-inline-functions-called-once -fgcse-after-reload -frerun-cse-after-loop -frename-registers -no-canonical-prefixes  -g -fno-exceptions -fno-rtti -O2 -DNDEBUG  -I"/Users/Bene/Android/opencv3/sdk/native/jni/include/opencv" -I"/Users/Bene/Android/opencv3/sdk/native/jni/include" -I/Users/Bene/Android/opencv3/sdk/native/jni/include/ -I/Users/Bene/Dropbox/Dokumente/OpticalDesign/Beamerscope/Android/BeamerscopeIlloptimization/holoscope/src/main/jni -I/Users/Bene/Library/Android/sdk/ndk-bundle/sources/cxx-stl/gnu-libstdc++/4.9/include -I/Users/Bene/Library/Android/sdk/ndk-bundle/sources/cxx-stl/gnu-libstdc++/4.9/libs/mips/include -I/Users/Bene/Library/Android/sdk/ndk-bundle/sources/cxx-stl/gnu-libstdc++/4.9/include/backward -I/Users/Bene/Dropbox/Dokumente/OpticalDesign/Beamerscope/Android/BeamerscopeIlloptimization/holoscope/src/main/jni -DANDROID -fPIC -DANDROID -fsigned-char -Wa,--noexecstack -Wformat -Werror=format-security    -frtti -fexceptions  -isystem /Users/Bene/Library/Android/sdk/ndk-bundle/platforms/android-19/arch-mips/usr/include -c  /Users/Bene/Dropbox/Dokumente/OpticalDesign/Beamerscope/Android/BeamerscopeIlloptimization/holoscope/src/main/jni/common.cpp -o /Users/Bene/Dropbox/Dokumente/OpticalDesign/Beamerscope/Android/BeamerscopeIlloptimization/holoscope/.externalNativeBuild/ndkBuild/debug/obj/local/mips/objs/native_microscope/common.o 
echo [mips] "Compile++      ": "native_microscope <= jni_qDPC.cpp"
/Users/Bene/Library/Android/sdk/ndk-bundle/toolchains/mipsel-linux-android-4.9/prebuilt/darwin-x86_64/bin/mipsel-linux-android-g++ -MMD -MP -MF /Users/Bene/Dropbox/Dokumente/OpticalDesign/Beamerscope/Android/BeamerscopeIlloptimization/holoscope/.externalNativeBuild/ndkBuild/debug/obj/local/mips/objs/native_microscope/jni_qDPC.o.d -fpic -finline-functions -ffunction-sections -funwind-tables -fstack-protector-strong -fmessage-length=0 -fno-inline-functions-called-once -fgcse-after-reload -frerun-cse-after-loop -frename-registers -no-canonical-prefixes  -g -fno-exceptions -fno-rtti -O2 -DNDEBUG  -I"/Users/Bene/Android/opencv3/sdk/native/jni/include/opencv" -I"/Users/Bene/Android/opencv3/sdk/native/jni/include" -I/Users/Bene/Android/opencv3/sdk/native/jni/include/ -I/Users/Bene/Dropbox/Dokumente/OpticalDesign/Beamerscope/Android/BeamerscopeIlloptimization/holoscope/src/main/jni -I/Users/Bene/Library/Android/sdk/ndk-bundle/sources/cxx-stl/gnu-libstdc++/4.9/include -I/Users/Bene/Library/Android/sdk/ndk-bundle/sources/cxx-stl/gnu-libstdc++/4.9/libs/mips/include -I/Users/Bene/Library/Android/sdk/ndk-bundle/sources/cxx-stl/gnu-libstdc++/4.9/include/backward -I/Users/Bene/Dropbox/Dokumente/OpticalDesign/Beamerscope/Android/BeamerscopeIlloptimization/holoscope/src/main/jni -DANDROID -fPIC -DANDROID -fsigned-char -Wa,--noexecstack -Wformat -Werror=format-security    -frtti -fexceptions  -isystem /Users/Bene/Library/Android/sdk/ndk-bundle/platforms/android-19/arch-mips/usr/include -c  /Users/Bene/Dropbox/Dokumente/OpticalDesign/Beamerscope/Android/BeamerscopeIlloptimization/holoscope/src/main/jni/jni_qDPC.cpp -o /Users/Bene/Dropbox/Dokumente/OpticalDesign/Beamerscope/Android/BeamerscopeIlloptimization/holoscope/.externalNativeBuild/ndkBuild/debug/obj/local/mips/objs/native_microscope/jni_qDPC.o 
echo [mips] "Compile++      ": "native_microscope <= jni_illpattern.cpp"
/Users/Bene/Library/Android/sdk/ndk-bundle/toolchains/mipsel-linux-android-4.9/prebuilt/darwin-x86_64/bin/mipsel-linux-android-g++ -MMD -MP -MF /Users/Bene/Dropbox/Dokumente/OpticalDesign/Beamerscope/Android/BeamerscopeIlloptimization/holoscope/.externalNativeBuild/ndkBuild/debug/obj/local/mips/objs/native_microscope/jni_illpattern.o.d -fpic -finline-functions -ffunction-sections -funwind-tables -fstack-protector-strong -fmessage-length=0 -fno-inline-functions-called-once -fgcse-after-reload -frerun-cse-after-loop -frename-registers -no-canonical-prefixes  -g -fno-exceptions -fno-rtti -O2 -DNDEBUG  -I"/Users/Bene/Android/opencv3/sdk/native/jni/include/opencv" -I"/Users/Bene/Android/opencv3/sdk/native/jni/include" -I/Users/Bene/Android/opencv3/sdk/native/jni/include/ -I/Users/Bene/Dropbox/Dokumente/OpticalDesign/Beamerscope/Android/BeamerscopeIlloptimization/holoscope/src/main/jni -I/Users/Bene/Library/Android/sdk/ndk-bundle/sources/cxx-stl/gnu-libstdc++/4.9/include -I/Users/Bene/Library/Android/sdk/ndk-bundle/sources/cxx-stl/gnu-libstdc++/4.9/libs/mips/include -I/Users/Bene/Library/Android/sdk/ndk-bundle/sources/cxx-stl/gnu-libstdc++/4.9/include/backward -I/Users/Bene/Dropbox/Dokumente/OpticalDesign/Beamerscope/Android/BeamerscopeIlloptimization/holoscope/src/main/jni -DANDROID -fPIC -DANDROID -fsigned-char -Wa,--noexecstack -Wformat -Werror=format-security    -frtti -fexceptions  -isystem /Users/Bene/Library/Android/sdk/ndk-bundle/platforms/android-19/arch-mips/usr/include -c  /Users/Bene/Dropbox/Dokumente/OpticalDesign/Beamerscope/Android/BeamerscopeIlloptimization/holoscope/src/main/jni/jni_illpattern.cpp -o /Users/Bene/Dropbox/Dokumente/OpticalDesign/Beamerscope/Android/BeamerscopeIlloptimization/holoscope/.externalNativeBuild/ndkBuild/debug/obj/local/mips/objs/native_microscope/jni_illpattern.o 
echo [mips] "Compile++      ": "native_microscope <= jni_illparameter.cpp"
/Users/Bene/Library/Android/sdk/ndk-bundle/toolchains/mipsel-linux-android-4.9/prebuilt/darwin-x86_64/bin/mipsel-linux-android-g++ -MMD -MP -MF /Users/Bene/Dropbox/Dokumente/OpticalDesign/Beamerscope/Android/BeamerscopeIlloptimization/holoscope/.externalNativeBuild/ndkBuild/debug/obj/local/mips/objs/native_microscope/jni_illparameter.o.d -fpic -finline-functions -ffunction-sections -funwind-tables -fstack-protector-strong -fmessage-length=0 -fno-inline-functions-called-once -fgcse-after-reload -frerun-cse-after-loop -frename-registers -no-canonical-prefixes  -g -fno-exceptions -fno-rtti -O2 -DNDEBUG  -I"/Users/Bene/Android/opencv3/sdk/native/jni/include/opencv" -I"/Users/Bene/Android/opencv3/sdk/native/jni/include" -I/Users/Bene/Android/opencv3/sdk/native/jni/include/ -I/Users/Bene/Dropbox/Dokumente/OpticalDesign/Beamerscope/Android/BeamerscopeIlloptimization/holoscope/src/main/jni -I/Users/Bene/Library/Android/sdk/ndk-bundle/sources/cxx-stl/gnu-libstdc++/4.9/include -I/Users/Bene/Library/Android/sdk/ndk-bundle/sources/cxx-stl/gnu-libstdc++/4.9/libs/mips/include -I/Users/Bene/Library/Android/sdk/ndk-bundle/sources/cxx-stl/gnu-libstdc++/4.9/include/backward -I/Users/Bene/Dropbox/Dokumente/OpticalDesign/Beamerscope/Android/BeamerscopeIlloptimization/holoscope/src/main/jni -DANDROID -fPIC -DANDROID -fsigned-char -Wa,--noexecstack -Wformat -Werror=format-security    -frtti -fexceptions  -isystem /Users/Bene/Library/Android/sdk/ndk-bundle/platforms/android-19/arch-mips/usr/include -c  /Users/Bene/Dropbox/Dokumente/OpticalDesign/Beamerscope/Android/BeamerscopeIlloptimization/holoscope/src/main/jni/jni_illparameter.cpp -o /Users/Bene/Dropbox/Dokumente/OpticalDesign/Beamerscope/Android/BeamerscopeIlloptimization/holoscope/.externalNativeBuild/ndkBuild/debug/obj/local/mips/objs/native_microscope/jni_illparameter.o 
echo [mips] "SharedLibrary  ": "libnative_microscope.so"
/Users/Bene/Library/Android/sdk/ndk-bundle/toolchains/mipsel-linux-android-4.9/prebuilt/darwin-x86_64/bin/mipsel-linux-android-g++ -Wl,-soname,libnative_microscope.so -shared --sysroot=/Users/Bene/Library/Android/sdk/ndk-bundle/platforms/android-19/arch-mips /Users/Bene/Dropbox/Dokumente/OpticalDesign/Beamerscope/Android/BeamerscopeIlloptimization/holoscope/.externalNativeBuild/ndkBuild/debug/obj/local/mips/objs/native_microscope/cvComplex.o /Users/Bene/Dropbox/Dokumente/OpticalDesign/Beamerscope/Android/BeamerscopeIlloptimization/holoscope/.externalNativeBuild/ndkBuild/debug/obj/local/mips/objs/native_microscope/common.o /Users/Bene/Dropbox/Dokumente/OpticalDesign/Beamerscope/Android/BeamerscopeIlloptimization/holoscope/.externalNativeBuild/ndkBuild/debug/obj/local/mips/objs/native_microscope/jni_qDPC.o /Users/Bene/Dropbox/Dokumente/OpticalDesign/Beamerscope/Android/BeamerscopeIlloptimization/holoscope/.externalNativeBuild/ndkBuild/debug/obj/local/mips/objs/native_microscope/jni_illpattern.o /Users/Bene/Dropbox/Dokumente/OpticalDesign/Beamerscope/Android/BeamerscopeIlloptimization/holoscope/.externalNativeBuild/ndkBuild/debug/obj/local/mips/objs/native_microscope/jni_illparameter.o /Users/Bene/Library/Android/sdk/ndk-bundle/sources/cxx-stl/gnu-libstdc++/4.9/libs/mips/libgnustl_static.a -lgcc /Users/Bene/Dropbox/Dokumente/OpticalDesign/Beamerscope/Android/BeamerscopeIlloptimization/holoscope/.externalNativeBuild/ndkBuild/debug/obj/local/mips/libopencv_java3.so -no-canonical-prefixes  -Wl,--build-id -Wl,--no-undefined -Wl,-z,noexecstack -Wl,-z,relro -Wl,-z,now -Wl,--warn-shared-textrel -Wl,--fatal-warnings  -L/Users/Bene/Library/Android/sdk/ndk-bundle/platforms/android-19/arch-mips/usr/lib -llog -ldl -lc -lm -o /Users/Bene/Dropbox/Dokumente/OpticalDesign/Beamerscope/Android/BeamerscopeIlloptimization/holoscope/.externalNativeBuild/ndkBuild/debug/obj/local/mips/libnative_microscope.so
echo [mips] "Install        ": "libnative_microscope.so => /Users/Bene/Dropbox/Dokumente/OpticalDesign/Beamerscope/Android/BeamerscopeIlloptimization/holoscope/build/intermediates/ndkBuild/debug/lib/mips/libnative_microscope.so"
install -p /Users/Bene/Dropbox/Dokumente/OpticalDesign/Beamerscope/Android/BeamerscopeIlloptimization/holoscope/.externalNativeBuild/ndkBuild/debug/obj/local/mips/libnative_microscope.so /Users/Bene/Dropbox/Dokumente/OpticalDesign/Beamerscope/Android/BeamerscopeIlloptimization/holoscope/build/intermediates/ndkBuild/debug/lib/mips/libnative_microscope.so
/Users/Bene/Library/Android/sdk/ndk-bundle/toolchains/mipsel-linux-android-4.9/prebuilt/darwin-x86_64/bin/mipsel-linux-android-strip --strip-unneeded  /Users/Bene/Dropbox/Dokumente/OpticalDesign/Beamerscope/Android/BeamerscopeIlloptimization/holoscope/build/intermediates/ndkBuild/debug/lib/mips/libnative_microscope.so
echo [mips] "Install        ": "libopencv_java3.so => /Users/Bene/Dropbox/Dokumente/OpticalDesign/Beamerscope/Android/BeamerscopeIlloptimization/holoscope/build/intermediates/ndkBuild/debug/lib/mips/libopencv_java3.so"
install -p /Users/Bene/Dropbox/Dokumente/OpticalDesign/Beamerscope/Android/BeamerscopeIlloptimization/holoscope/.externalNativeBuild/ndkBuild/debug/obj/local/mips/libopencv_java3.so /Users/Bene/Dropbox/Dokumente/OpticalDesign/Beamerscope/Android/BeamerscopeIlloptimization/holoscope/build/intermediates/ndkBuild/debug/lib/mips/libopencv_java3.so
/Users/Bene/Library/Android/sdk/ndk-bundle/toolchains/mipsel-linux-android-4.9/prebuilt/darwin-x86_64/bin/mipsel-linux-android-strip --strip-unneeded  /Users/Bene/Dropbox/Dokumente/OpticalDesign/Beamerscope/Android/BeamerscopeIlloptimization/holoscope/build/intermediates/ndkBuild/debug/lib/mips/libopencv_java3.so

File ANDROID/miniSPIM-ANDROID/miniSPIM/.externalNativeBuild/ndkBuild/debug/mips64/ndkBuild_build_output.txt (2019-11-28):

rm -f /Users/Bene/Dropbox/Dokumente/OpticalDesign/Beamerscope/Android/BeamerscopeIlloptimization/holoscope/build/intermediates/ndkBuild/debug/lib/mips64/lib*.so
rm -f /Users/Bene/Dropbox/Dokumente/OpticalDesign/Beamerscope/Android/BeamerscopeIlloptimization/holoscope/build/intermediates/ndkBuild/debug/lib/mips64/gdbserver
rm -f /Users/Bene/Dropbox/Dokumente/OpticalDesign/Beamerscope/Android/BeamerscopeIlloptimization/holoscope/build/intermediates/ndkBuild/debug/lib/mips64/gdb.setup
echo [mips64] "Compile++      ": "native_microscope <= cvComplex.cpp"
/Users/Bene/Library/Android/sdk/ndk-bundle/toolchains/mips64el-linux-android-4.9/prebuilt/darwin-x86_64/bin/mips64el-linux-android-g++ -MMD -MP -MF /Users/Bene/Dropbox/Dokumente/OpticalDesign/Beamerscope/Android/BeamerscopeIlloptimization/holoscope/.externalNativeBuild/ndkBuild/debug/obj/local/mips64/objs/native_microscope/cvComplex.o.d -fpic -finline-functions -ffunction-sections -funwind-tables -fstack-protector-strong -fmessage-length=0 -fno-inline-functions-called-once -fgcse-after-reload -frerun-cse-after-loop -frename-registers -no-canonical-prefixes  -g -fno-exceptions -fno-rtti -O2 -DNDEBUG  -I"/Users/Bene/Android/opencv3/sdk/native/jni/include/opencv" -I"/Users/Bene/Android/opencv3/sdk/native/jni/include" -I/Users/Bene/Android/opencv3/sdk/native/jni/include/ -I/Users/Bene/Dropbox/Dokumente/OpticalDesign/Beamerscope/Android/BeamerscopeIlloptimization/holoscope/src/main/jni -I/Users/Bene/Library/Android/sdk/ndk-bundle/sources/cxx-stl/gnu-libstdc++/4.9/include -I/Users/Bene/Library/Android/sdk/ndk-bundle/sources/cxx-stl/gnu-libstdc++/4.9/libs/mips64/include -I/Users/Bene/Library/Android/sdk/ndk-bundle/sources/cxx-stl/gnu-libstdc++/4.9/include/backward -I/Users/Bene/Dropbox/Dokumente/OpticalDesign/Beamerscope/Android/BeamerscopeIlloptimization/holoscope/src/main/jni -DANDROID -fPIC -DANDROID -fsigned-char -Wa,--noexecstack -Wformat -Werror=format-security    -frtti -fexceptions  -isystem /Users/Bene/Library/Android/sdk/ndk-bundle/platforms/android-21/arch-mips64/usr/include -c  /Users/Bene/Dropbox/Dokumente/OpticalDesign/Beamerscope/Android/BeamerscopeIlloptimization/holoscope/src/main/jni/cvComplex.cpp -o /Users/Bene/Dropbox/Dokumente/OpticalDesign/Beamerscope/Android/BeamerscopeIlloptimization/holoscope/.externalNativeBuild/ndkBuild/debug/obj/local/mips64/objs/native_microscope/cvComplex.o 
echo [mips64] "Compile++      ": "native_microscope <= common.cpp"
/Users/Bene/Library/Android/sdk/ndk-bundle/toolchains/mips64el-linux-android-4.9/prebuilt/darwin-x86_64/bin/mips64el-linux-android-g++ -MMD -MP -MF /Users/Bene/Dropbox/Dokumente/OpticalDesign/Beamerscope/Android/BeamerscopeIlloptimization/holoscope/.externalNativeBuild/ndkBuild/debug/obj/local/mips64/objs/native_microscope/common.o.d -fpic -finline-functions -ffunction-sections -funwind-tables -fstack-protector-strong -fmessage-length=0 -fno-inline-functions-called-once -fgcse-after-reload -frerun-cse-after-loop -frename-registers -no-canonical-prefixes  -g -fno-exceptions -fno-rtti -O2 -DNDEBUG  -I"/Users/Bene/Android/opencv3/sdk/native/jni/include/opencv" -I"/Users/Bene/Android/opencv3/sdk/native/jni/include" -I/Users/Bene/Android/opencv3/sdk/native/jni/include/ -I/Users/Bene/Dropbox/Dokumente/OpticalDesign/Beamerscope/Android/BeamerscopeIlloptimization/holoscope/src/main/jni -I/Users/Bene/Library/Android/sdk/ndk-bundle/sources/cxx-stl/gnu-libstdc++/4.9/include -I/Users/Bene/Library/Android/sdk/ndk-bundle/sources/cxx-stl/gnu-libstdc++/4.9/libs/mips64/include -I/Users/Bene/Library/Android/sdk/ndk-bundle/sources/cxx-stl/gnu-libstdc++/4.9/include/backward -I/Users/Bene/Dropbox/Dokumente/OpticalDesign/Beamerscope/Android/BeamerscopeIlloptimization/holoscope/src/main/jni -DANDROID -fPIC -DANDROID -fsigned-char -Wa,--noexecstack -Wformat -Werror=format-security    -frtti -fexceptions  -isystem /Users/Bene/Library/Android/sdk/ndk-bundle/platforms/android-21/arch-mips64/usr/include -c  /Users/Bene/Dropbox/Dokumente/OpticalDesign/Beamerscope/Android/BeamerscopeIlloptimization/holoscope/src/main/jni/common.cpp -o /Users/Bene/Dropbox/Dokumente/OpticalDesign/Beamerscope/Android/BeamerscopeIlloptimization/holoscope/.externalNativeBuild/ndkBuild/debug/obj/local/mips64/objs/native_microscope/common.o 
echo [mips64] "Compile++      ": "native_microscope <= jni_qDPC.cpp"
/Users/Bene/Library/Android/sdk/ndk-bundle/toolchains/mips64el-linux-android-4.9/prebuilt/darwin-x86_64/bin/mips64el-linux-android-g++ -MMD -MP -MF /Users/Bene/Dropbox/Dokumente/OpticalDesign/Beamerscope/Android/BeamerscopeIlloptimization/holoscope/.externalNativeBuild/ndkBuild/debug/obj/local/mips64/objs/native_microscope/jni_qDPC.o.d -fpic -finline-functions -ffunction-sections -funwind-tables -fstack-protector-strong -fmessage-length=0 -fno-inline-functions-called-once -fgcse-after-reload -frerun-cse-after-loop -frename-registers -no-canonical-prefixes  -g -fno-exceptions -fno-rtti -O2 -DNDEBUG  -I"/Users/Bene/Android/opencv3/sdk/native/jni/include/opencv" -I"/Users/Bene/Android/opencv3/sdk/native/jni/include" -I/Users/Bene/Android/opencv3/sdk/native/jni/include/ -I/Users/Bene/Dropbox/Dokumente/OpticalDesign/Beamerscope/Android/BeamerscopeIlloptimization/holoscope/src/main/jni -I/Users/Bene/Library/Android/sdk/ndk-bundle/sources/cxx-stl/gnu-libstdc++/4.9/include -I/Users/Bene/Library/Android/sdk/ndk-bundle/sources/cxx-stl/gnu-libstdc++/4.9/libs/mips64/include -I/Users/Bene/Library/Android/sdk/ndk-bundle/sources/cxx-stl/gnu-libstdc++/4.9/include/backward -I/Users/Bene/Dropbox/Dokumente/OpticalDesign/Beamerscope/Android/BeamerscopeIlloptimization/holoscope/src/main/jni -DANDROID -fPIC -DANDROID -fsigned-char -Wa,--noexecstack -Wformat -Werror=format-security    -frtti -fexceptions  -isystem /Users/Bene/Library/Android/sdk/ndk-bundle/platforms/android-21/arch-mips64/usr/include -c  /Users/Bene/Dropbox/Dokumente/OpticalDesign/Beamerscope/Android/BeamerscopeIlloptimization/holoscope/src/main/jni/jni_qDPC.cpp -o /Users/Bene/Dropbox/Dokumente/OpticalDesign/Beamerscope/Android/BeamerscopeIlloptimization/holoscope/.externalNativeBuild/ndkBuild/debug/obj/local/mips64/objs/native_microscope/jni_qDPC.o 
echo [mips64] "Compile++      ": "native_microscope <= jni_illpattern.cpp"
/Users/Bene/Library/Android/sdk/ndk-bundle/toolchains/mips64el-linux-android-4.9/prebuilt/darwin-x86_64/bin/mips64el-linux-android-g++ -MMD -MP -MF /Users/Bene/Dropbox/Dokumente/OpticalDesign/Beamerscope/Android/BeamerscopeIlloptimization/holoscope/.externalNativeBuild/ndkBuild/debug/obj/local/mips64/objs/native_microscope/jni_illpattern.o.d -fpic -finline-functions -ffunction-sections -funwind-tables -fstack-protector-strong -fmessage-length=0 -fno-inline-functions-called-once -fgcse-after-reload -frerun-cse-after-loop -frename-registers -no-canonical-prefixes  -g -fno-exceptions -fno-rtti -O2 -DNDEBUG  -I"/Users/Bene/Android/opencv3/sdk/native/jni/include/opencv" -I"/Users/Bene/Android/opencv3/sdk/native/jni/include" -I/Users/Bene/Android/opencv3/sdk/native/jni/include/ -I/Users/Bene/Dropbox/Dokumente/OpticalDesign/Beamerscope/Android/BeamerscopeIlloptimization/holoscope/src/main/jni -I/Users/Bene/Library/Android/sdk/ndk-bundle/sources/cxx-stl/gnu-libstdc++/4.9/include -I/Users/Bene/Library/Android/sdk/ndk-bundle/sources/cxx-stl/gnu-libstdc++/4.9/libs/mips64/include -I/Users/Bene/Library/Android/sdk/ndk-bundle/sources/cxx-stl/gnu-libstdc++/4.9/include/backward -I/Users/Bene/Dropbox/Dokumente/OpticalDesign/Beamerscope/Android/BeamerscopeIlloptimization/holoscope/src/main/jni -DANDROID -fPIC -DANDROID -fsigned-char -Wa,--noexecstack -Wformat -Werror=format-security    -frtti -fexceptions  -isystem /Users/Bene/Library/Android/sdk/ndk-bundle/platforms/android-21/arch-mips64/usr/include -c  /Users/Bene/Dropbox/Dokumente/OpticalDesign/Beamerscope/Android/BeamerscopeIlloptimization/holoscope/src/main/jni/jni_illpattern.cpp -o /Users/Bene/Dropbox/Dokumente/OpticalDesign/Beamerscope/Android/BeamerscopeIlloptimization/holoscope/.externalNativeBuild/ndkBuild/debug/obj/local/mips64/objs/native_microscope/jni_illpattern.o 
echo [mips64] "Compile++      ": "native_microscope <= jni_illparameter.cpp"
/Users/Bene/Library/Android/sdk/ndk-bundle/toolchains/mips64el-linux-android-4.9/prebuilt/darwin-x86_64/bin/mips64el-linux-android-g++ -MMD -MP -MF /Users/Bene/Dropbox/Dokumente/OpticalDesign/Beamerscope/Android/BeamerscopeIlloptimization/holoscope/.externalNativeBuild/ndkBuild/debug/obj/local/mips64/objs/native_microscope/jni_illparameter.o.d -fpic -finline-functions -ffunction-sections -funwind-tables -fstack-protector-strong -fmessage-length=0 -fno-inline-functions-called-once -fgcse-after-reload -frerun-cse-after-loop -frename-registers -no-canonical-prefixes  -g -fno-exceptions -fno-rtti -O2 -DNDEBUG  -I"/Users/Bene/Android/opencv3/sdk/native/jni/include/opencv" -I"/Users/Bene/Android/opencv3/sdk/native/jni/include" -I/Users/Bene/Android/opencv3/sdk/native/jni/include/ -I/Users/Bene/Dropbox/Dokumente/OpticalDesign/Beamerscope/Android/BeamerscopeIlloptimization/holoscope/src/main/jni -I/Users/Bene/Library/Android/sdk/ndk-bundle/sources/cxx-stl/gnu-libstdc++/4.9/include -I/Users/Bene/Library/Android/sdk/ndk-bundle/sources/cxx-stl/gnu-libstdc++/4.9/libs/mips64/include -I/Users/Bene/Library/Android/sdk/ndk-bundle/sources/cxx-stl/gnu-libstdc++/4.9/include/backward -I/Users/Bene/Dropbox/Dokumente/OpticalDesign/Beamerscope/Android/BeamerscopeIlloptimization/holoscope/src/main/jni -DANDROID -fPIC -DANDROID -fsigned-char -Wa,--noexecstack -Wformat -Werror=format-security    -frtti -fexceptions  -isystem /Users/Bene/Library/Android/sdk/ndk-bundle/platforms/android-21/arch-mips64/usr/include -c  /Users/Bene/Dropbox/Dokumente/OpticalDesign/Beamerscope/Android/BeamerscopeIlloptimization/holoscope/src/main/jni/jni_illparameter.cpp -o /Users/Bene/Dropbox/Dokumente/OpticalDesign/Beamerscope/Android/BeamerscopeIlloptimization/holoscope/.externalNativeBuild/ndkBuild/debug/obj/local/mips64/objs/native_microscope/jni_illparameter.o 
echo [mips64] "SharedLibrary  ": "libnative_microscope.so"
/Users/Bene/Library/Android/sdk/ndk-bundle/toolchains/mips64el-linux-android-4.9/prebuilt/darwin-x86_64/bin/mips64el-linux-android-g++ -Wl,-soname,libnative_microscope.so -shared --sysroot=/Users/Bene/Library/Android/sdk/ndk-bundle/platforms/android-21/arch-mips64 /Users/Bene/Dropbox/Dokumente/OpticalDesign/Beamerscope/Android/BeamerscopeIlloptimization/holoscope/.externalNativeBuild/ndkBuild/debug/obj/local/mips64/objs/native_microscope/cvComplex.o /Users/Bene/Dropbox/Dokumente/OpticalDesign/Beamerscope/Android/BeamerscopeIlloptimization/holoscope/.externalNativeBuild/ndkBuild/debug/obj/local/mips64/objs/native_microscope/common.o /Users/Bene/Dropbox/Dokumente/OpticalDesign/Beamerscope/Android/BeamerscopeIlloptimization/holoscope/.externalNativeBuild/ndkBuild/debug/obj/local/mips64/objs/native_microscope/jni_qDPC.o /Users/Bene/Dropbox/Dokumente/OpticalDesign/Beamerscope/Android/BeamerscopeIlloptimization/holoscope/.externalNativeBuild/ndkBuild/debug/obj/local/mips64/objs/native_microscope/jni_illpattern.o /Users/Bene/Dropbox/Dokumente/OpticalDesign/Beamerscope/Android/BeamerscopeIlloptimization/holoscope/.externalNativeBuild/ndkBuild/debug/obj/local/mips64/objs/native_microscope/jni_illparameter.o /Users/Bene/Library/Android/sdk/ndk-bundle/sources/cxx-stl/gnu-libstdc++/4.9/libs/mips64/libgnustl_static.a -lgcc /Users/Bene/Dropbox/Dokumente/OpticalDesign/Beamerscope/Android/BeamerscopeIlloptimization/holoscope/.externalNativeBuild/ndkBuild/debug/obj/local/mips64/libopencv_java3.so -no-canonical-prefixes  -Wl,--build-id -Wl,--no-undefined -Wl,-z,noexecstack -Wl,-z,relro -Wl,-z,now -Wl,--warn-shared-textrel -Wl,--fatal-warnings  -L/Users/Bene/Library/Android/sdk/ndk-bundle/platforms/android-21/arch-mips64/usr/lib64 -L/Users/Bene/Library/Android/sdk/ndk-bundle/platforms/android-21/arch-mips64/usr/lib -llog -ldl -lc -lm -o /Users/Bene/Dropbox/Dokumente/OpticalDesign/Beamerscope/Android/BeamerscopeIlloptimization/holoscope/.externalNativeBuild/ndkBuild/debug/obj/local/mips64/libnative_microscope.so
echo [mips64] "Install        ": "libnative_microscope.so => /Users/Bene/Dropbox/Dokumente/OpticalDesign/Beamerscope/Android/BeamerscopeIlloptimization/holoscope/build/intermediates/ndkBuild/debug/lib/mips64/libnative_microscope.so"
install -p /Users/Bene/Dropbox/Dokumente/OpticalDesign/Beamerscope/Android/BeamerscopeIlloptimization/holoscope/.externalNativeBuild/ndkBuild/debug/obj/local/mips64/libnative_microscope.so /Users/Bene/Dropbox/Dokumente/OpticalDesign/Beamerscope/Android/BeamerscopeIlloptimization/holoscope/build/intermediates/ndkBuild/debug/lib/mips64/libnative_microscope.so
/Users/Bene/Library/Android/sdk/ndk-bundle/toolchains/mips64el-linux-android-4.9/prebuilt/darwin-x86_64/bin/mips64el-linux-android-strip --strip-unneeded  /Users/Bene/Dropbox/Dokumente/OpticalDesign/Beamerscope/Android/BeamerscopeIlloptimization/holoscope/build/intermediates/ndkBuild/debug/lib/mips64/libnative_microscope.so
echo [mips64] "Install        ": "libopencv_java3.so => /Users/Bene/Dropbox/Dokumente/OpticalDesign/Beamerscope/Android/BeamerscopeIlloptimization/holoscope/build/intermediates/ndkBuild/debug/lib/mips64/libopencv_java3.so"
install -p /Users/Bene/Dropbox/Dokumente/OpticalDesign/Beamerscope/Android/BeamerscopeIlloptimization/holoscope/.externalNativeBuild/ndkBuild/debug/obj/local/mips64/libopencv_java3.so /Users/Bene/Dropbox/Dokumente/OpticalDesign/Beamerscope/Android/BeamerscopeIlloptimization/holoscope/build/intermediates/ndkBuild/debug/lib/mips64/libopencv_java3.so
/Users/Bene/Library/Android/sdk/ndk-bundle/toolchains/mips64el-linux-android-4.9/prebuilt/darwin-x86_64/bin/mips64el-linux-android-strip --strip-unneeded  /Users/Bene/Dropbox/Dokumente/OpticalDesign/Beamerscope/Android/BeamerscopeIlloptimization/holoscope/build/intermediates/ndkBuild/debug/lib/mips64/libopencv_java3.so

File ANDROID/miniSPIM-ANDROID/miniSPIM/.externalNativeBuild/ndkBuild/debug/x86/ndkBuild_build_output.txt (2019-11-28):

rm -f /Users/Bene/Dropbox/Dokumente/OpticalDesign/Beamerscope/Android/BeamerscopeIlloptimization/holoscope/build/intermediates/ndkBuild/debug/lib/x86/lib*.so
rm -f /Users/Bene/Dropbox/Dokumente/OpticalDesign/Beamerscope/Android/BeamerscopeIlloptimization/holoscope/build/intermediates/ndkBuild/debug/lib/x86/gdbserver
rm -f /Users/Bene/Dropbox/Dokumente/OpticalDesign/Beamerscope/Android/BeamerscopeIlloptimization/holoscope/build/intermediates/ndkBuild/debug/lib/x86/gdb.setup
echo [x86] "Compile++      ": "native_microscope <= cvComplex.cpp"
/Users/Bene/Library/Android/sdk/ndk-bundle/toolchains/x86-4.9/prebuilt/darwin-x86_64/bin/i686-linux-android-g++ -MMD -MP -MF /Users/Bene/Dropbox/Dokumente/OpticalDesign/Beamerscope/Android/BeamerscopeIlloptimization/holoscope/.externalNativeBuild/ndkBuild/debug/obj/local/x86/objs/native_microscope/cvComplex.o.d -ffunction-sections -funwind-tables -no-canonical-prefixes  -g -fstack-protector-strong -fno-exceptions -fno-rtti -O2 -DNDEBUG  -I"/Users/Bene/Android/opencv3/sdk/native/jni/include/opencv" -I"/Users/Bene/Android/opencv3/sdk/native/jni/include" -I/Users/Bene/Android/opencv3/sdk/native/jni/include/ -I/Users/Bene/Dropbox/Dokumente/OpticalDesign/Beamerscope/Android/BeamerscopeIlloptimization/holoscope/src/main/jni -I/Users/Bene/Library/Android/sdk/ndk-bundle/sources/cxx-stl/gnu-libstdc++/4.9/include -I/Users/Bene/Library/Android/sdk/ndk-bundle/sources/cxx-stl/gnu-libstdc++/4.9/libs/x86/include -I/Users/Bene/Library/Android/sdk/ndk-bundle/sources/cxx-stl/gnu-libstdc++/4.9/include/backward -I/Users/Bene/Dropbox/Dokumente/OpticalDesign/Beamerscope/Android/BeamerscopeIlloptimization/holoscope/src/main/jni -DANDROID -fPIC -DANDROID -fsigned-char -Wa,--noexecstack -Wformat -Werror=format-security    -frtti -fexceptions  -isystem /Users/Bene/Library/Android/sdk/ndk-bundle/platforms/android-19/arch-x86/usr/include -c  /Users/Bene/Dropbox/Dokumente/OpticalDesign/Beamerscope/Android/BeamerscopeIlloptimization/holoscope/src/main/jni/cvComplex.cpp -o /Users/Bene/Dropbox/Dokumente/OpticalDesign/Beamerscope/Android/BeamerscopeIlloptimization/holoscope/.externalNativeBuild/ndkBuild/debug/obj/local/x86/objs/native_microscope/cvComplex.o 
echo [x86] "Compile++      ": "native_microscope <= common.cpp"
/Users/Bene/Library/Android/sdk/ndk-bundle/toolchains/x86-4.9/prebuilt/darwin-x86_64/bin/i686-linux-android-g++ -MMD -MP -MF /Users/Bene/Dropbox/Dokumente/OpticalDesign/Beamerscope/Android/BeamerscopeIlloptimization/holoscope/.externalNativeBuild/ndkBuild/debug/obj/local/x86/objs/native_microscope/common.o.d -ffunction-sections -funwind-tables -no-canonical-prefixes  -g -fstack-protector-strong -fno-exceptions -fno-rtti -O2 -DNDEBUG  -I"/Users/Bene/Android/opencv3/sdk/native/jni/include/opencv" -I"/Users/Bene/Android/opencv3/sdk/native/jni/include" -I/Users/Bene/Android/opencv3/sdk/native/jni/include/ -I/Users/Bene/Dropbox/Dokumente/OpticalDesign/Beamerscope/Android/BeamerscopeIlloptimization/holoscope/src/main/jni -I/Users/Bene/Library/Android/sdk/ndk-bundle/sources/cxx-stl/gnu-libstdc++/4.9/include -I/Users/Bene/Library/Android/sdk/ndk-bundle/sources/cxx-stl/gnu-libstdc++/4.9/libs/x86/include -I/Users/Bene/Library/Android/sdk/ndk-bundle/sources/cxx-stl/gnu-libstdc++/4.9/include/backward -I/Users/Bene/Dropbox/Dokumente/OpticalDesign/Beamerscope/Android/BeamerscopeIlloptimization/holoscope/src/main/jni -DANDROID -fPIC -DANDROID -fsigned-char -Wa,--noexecstack -Wformat -Werror=format-security    -frtti -fexceptions  -isystem /Users/Bene/Library/Android/sdk/ndk-bundle/platforms/android-19/arch-x86/usr/include -c  /Users/Bene/Dropbox/Dokumente/OpticalDesign/Beamerscope/Android/BeamerscopeIlloptimization/holoscope/src/main/jni/common.cpp -o /Users/Bene/Dropbox/Dokumente/OpticalDesign/Beamerscope/Android/BeamerscopeIlloptimization/holoscope/.externalNativeBuild/ndkBuild/debug/obj/local/x86/objs/native_microscope/common.o 
echo [x86] "Compile++      ": "native_microscope <= jni_qDPC.cpp"
/Users/Bene/Library/Android/sdk/ndk-bundle/toolchains/x86-4.9/prebuilt/darwin-x86_64/bin/i686-linux-android-g++ -MMD -MP -MF /Users/Bene/Dropbox/Dokumente/OpticalDesign/Beamerscope/Android/BeamerscopeIlloptimization/holoscope/.externalNativeBuild/ndkBuild/debug/obj/local/x86/objs/native_microscope/jni_qDPC.o.d -ffunction-sections -funwind-tables -no-canonical-prefixes  -g -fstack-protector-strong -fno-exceptions -fno-rtti -O2 -DNDEBUG  -I"/Users/Bene/Android/opencv3/sdk/native/jni/include/opencv" -I"/Users/Bene/Android/opencv3/sdk/native/jni/include" -I/Users/Bene/Android/opencv3/sdk/native/jni/include/ -I/Users/Bene/Dropbox/Dokumente/OpticalDesign/Beamerscope/Android/BeamerscopeIlloptimization/holoscope/src/main/jni -I/Users/Bene/Library/Android/sdk/ndk-bundle/sources/cxx-stl/gnu-libstdc++/4.9/include -I/Users/Bene/Library/Android/sdk/ndk-bundle/sources/cxx-stl/gnu-libstdc++/4.9/libs/x86/include -I/Users/Bene/Library/Android/sdk/ndk-bundle/sources/cxx-stl/gnu-libstdc++/4.9/include/backward -I/Users/Bene/Dropbox/Dokumente/OpticalDesign/Beamerscope/Android/BeamerscopeIlloptimization/holoscope/src/main/jni -DANDROID -fPIC -DANDROID -fsigned-char -Wa,--noexecstack -Wformat -Werror=format-security    -frtti -fexceptions  -isystem /Users/Bene/Library/Android/sdk/ndk-bundle/platforms/android-19/arch-x86/usr/include -c  /Users/Bene/Dropbox/Dokumente/OpticalDesign/Beamerscope/Android/BeamerscopeIlloptimization/holoscope/src/main/jni/jni_qDPC.cpp -o /Users/Bene/Dropbox/Dokumente/OpticalDesign/Beamerscope/Android/BeamerscopeIlloptimization/holoscope/.externalNativeBuild/ndkBuild/debug/obj/local/x86/objs/native_microscope/jni_qDPC.o 
echo [x86] "Compile++      ": "native_microscope <= jni_illpattern.cpp"
/Users/Bene/Library/Android/sdk/ndk-bundle/toolchains/x86-4.9/prebuilt/darwin-x86_64/bin/i686-linux-android-g++ -MMD -MP -MF /Users/Bene/Dropbox/Dokumente/OpticalDesign/Beamerscope/Android/BeamerscopeIlloptimization/holoscope/.externalNativeBuild/ndkBuild/debug/obj/local/x86/objs/native_microscope/jni_illpattern.o.d -ffunction-sections -funwind-tables -no-canonical-prefixes  -g -fstack-protector-strong -fno-exceptions -fno-rtti -O2 -DNDEBUG  -I"/Users/Bene/Android/opencv3/sdk/native/jni/include/opencv" -I"/Users/Bene/Android/opencv3/sdk/native/jni/include" -I/Users/Bene/Android/opencv3/sdk/native/jni/include/ -I/Users/Bene/Dropbox/Dokumente/OpticalDesign/Beamerscope/Android/BeamerscopeIlloptimization/holoscope/src/main/jni -I/Users/Bene/Library/Android/sdk/ndk-bundle/sources/cxx-stl/gnu-libstdc++/4.9/include -I/Users/Bene/Library/Android/sdk/ndk-bundle/sources/cxx-stl/gnu-libstdc++/4.9/libs/x86/include -I/Users/Bene/Library/Android/sdk/ndk-bundle/sources/cxx-stl/gnu-libstdc++/4.9/include/backward -I/Users/Bene/Dropbox/Dokumente/OpticalDesign/Beamerscope/Android/BeamerscopeIlloptimization/holoscope/src/main/jni -DANDROID -fPIC -DANDROID -fsigned-char -Wa,--noexecstack -Wformat -Werror=format-security    -frtti -fexceptions  -isystem /Users/Bene/Library/Android/sdk/ndk-bundle/platforms/android-19/arch-x86/usr/include -c  /Users/Bene/Dropbox/Dokumente/OpticalDesign/Beamerscope/Android/BeamerscopeIlloptimization/holoscope/src/main/jni/jni_illpattern.cpp -o /Users/Bene/Dropbox/Dokumente/OpticalDesign/Beamerscope/Android/BeamerscopeIlloptimization/holoscope/.externalNativeBuild/ndkBuild/debug/obj/local/x86/objs/native_microscope/jni_illpattern.o 
echo [x86] "Compile++      ": "native_microscope <= jni_illparameter.cpp"
/Users/Bene/Library/Android/sdk/ndk-bundle/toolchains/x86-4.9/prebuilt/darwin-x86_64/bin/i686-linux-android-g++ -MMD -MP -MF /Users/Bene/Dropbox/Dokumente/OpticalDesign/Beamerscope/Android/BeamerscopeIlloptimization/holoscope/.externalNativeBuild/ndkBuild/debug/obj/local/x86/objs/native_microscope/jni_illparameter.o.d -ffunction-sections -funwind-tables -no-canonical-prefixes  -g -fstack-protector-strong -fno-exceptions -fno-rtti -O2 -DNDEBUG  -I"/Users/Bene/Android/opencv3/sdk/native/jni/include/opencv" -I"/Users/Bene/Android/opencv3/sdk/native/jni/include" -I/Users/Bene/Android/opencv3/sdk/native/jni/include/ -I/Users/Bene/Dropbox/Dokumente/OpticalDesign/Beamerscope/Android/BeamerscopeIlloptimization/holoscope/src/main/jni -I/Users/Bene/Library/Android/sdk/ndk-bundle/sources/cxx-stl/gnu-libstdc++/4.9/include -I/Users/Bene/Library/Android/sdk/ndk-bundle/sources/cxx-stl/gnu-libstdc++/4.9/libs/x86/include -I/Users/Bene/Library/Android/sdk/ndk-bundle/sources/cxx-stl/gnu-libstdc++/4.9/include/backward -I/Users/Bene/Dropbox/Dokumente/OpticalDesign/Beamerscope/Android/BeamerscopeIlloptimization/holoscope/src/main/jni -DANDROID -fPIC -DANDROID -fsigned-char -Wa,--noexecstack -Wformat -Werror=format-security    -frtti -fexceptions  -isystem /Users/Bene/Library/Android/sdk/ndk-bundle/platforms/android-19/arch-x86/usr/include -c  /Users/Bene/Dropbox/Dokumente/OpticalDesign/Beamerscope/Android/BeamerscopeIlloptimization/holoscope/src/main/jni/jni_illparameter.cpp -o /Users/Bene/Dropbox/Dokumente/OpticalDesign/Beamerscope/Android/BeamerscopeIlloptimization/holoscope/.externalNativeBuild/ndkBuild/debug/obj/local/x86/objs/native_microscope/jni_illparameter.o 
echo [x86] "SharedLibrary  ": "libnative_microscope.so"
/Users/Bene/Library/Android/sdk/ndk-bundle/toolchains/x86-4.9/prebuilt/darwin-x86_64/bin/i686-linux-android-g++ -Wl,-soname,libnative_microscope.so -shared --sysroot=/Users/Bene/Library/Android/sdk/ndk-bundle/platforms/android-19/arch-x86 /Users/Bene/Dropbox/Dokumente/OpticalDesign/Beamerscope/Android/BeamerscopeIlloptimization/holoscope/.externalNativeBuild/ndkBuild/debug/obj/local/x86/objs/native_microscope/cvComplex.o /Users/Bene/Dropbox/Dokumente/OpticalDesign/Beamerscope/Android/BeamerscopeIlloptimization/holoscope/.externalNativeBuild/ndkBuild/debug/obj/local/x86/objs/native_microscope/common.o /Users/Bene/Dropbox/Dokumente/OpticalDesign/Beamerscope/Android/BeamerscopeIlloptimization/holoscope/.externalNativeBuild/ndkBuild/debug/obj/local/x86/objs/native_microscope/jni_qDPC.o /Users/Bene/Dropbox/Dokumente/OpticalDesign/Beamerscope/Android/BeamerscopeIlloptimization/holoscope/.externalNativeBuild/ndkBuild/debug/obj/local/x86/objs/native_microscope/jni_illpattern.o /Users/Bene/Dropbox/Dokumente/OpticalDesign/Beamerscope/Android/BeamerscopeIlloptimization/holoscope/.externalNativeBuild/ndkBuild/debug/obj/local/x86/objs/native_microscope/jni_illparameter.o /Users/Bene/Library/Android/sdk/ndk-bundle/sources/cxx-stl/gnu-libstdc++/4.9/libs/x86/libgnustl_static.a -lgcc /Users/Bene/Dropbox/Dokumente/OpticalDesign/Beamerscope/Android/BeamerscopeIlloptimization/holoscope/.externalNativeBuild/ndkBuild/debug/obj/local/x86/libopencv_java3.so -no-canonical-prefixes  -Wl,--build-id -Wl,--no-undefined -Wl,-z,noexecstack -Wl,-z,relro -Wl,-z,now -Wl,--warn-shared-textrel -Wl,--fatal-warnings  -L/Users/Bene/Library/Android/sdk/ndk-bundle/platforms/android-19/arch-x86/usr/lib -llog -ldl -lc -lm -o /Users/Bene/Dropbox/Dokumente/OpticalDesign/Beamerscope/Android/BeamerscopeIlloptimization/holoscope/.externalNativeBuild/ndkBuild/debug/obj/local/x86/libnative_microscope.so
echo [x86] "Install        ": "libnative_microscope.so => /Users/Bene/Dropbox/Dokumente/OpticalDesign/Beamerscope/Android/BeamerscopeIlloptimization/holoscope/build/intermediates/ndkBuild/debug/lib/x86/libnative_microscope.so"
install -p /Users/Bene/Dropbox/Dokumente/OpticalDesign/Beamerscope/Android/BeamerscopeIlloptimization/holoscope/.externalNativeBuild/ndkBuild/debug/obj/local/x86/libnative_microscope.so /Users/Bene/Dropbox/Dokumente/OpticalDesign/Beamerscope/Android/BeamerscopeIlloptimization/holoscope/build/intermediates/ndkBuild/debug/lib/x86/libnative_microscope.so
/Users/Bene/Library/Android/sdk/ndk-bundle/toolchains/x86-4.9/prebuilt/darwin-x86_64/bin/i686-linux-android-strip --strip-unneeded  /Users/Bene/Dropbox/Dokumente/OpticalDesign/Beamerscope/Android/BeamerscopeIlloptimization/holoscope/build/intermediates/ndkBuild/debug/lib/x86/libnative_microscope.so
echo [x86] "Install        ": "libopencv_java3.so => /Users/Bene/Dropbox/Dokumente/OpticalDesign/Beamerscope/Android/BeamerscopeIlloptimization/holoscope/build/intermediates/ndkBuild/debug/lib/x86/libopencv_java3.so"
install -p /Users/Bene/Dropbox/Dokumente/OpticalDesign/Beamerscope/Android/BeamerscopeIlloptimization/holoscope/.externalNativeBuild/ndkBuild/debug/obj/local/x86/libopencv_java3.so /Users/Bene/Dropbox/Dokumente/OpticalDesign/Beamerscope/Android/BeamerscopeIlloptimization/holoscope/build/intermediates/ndkBuild/debug/lib/x86/libopencv_java3.so
/Users/Bene/Library/Android/sdk/ndk-bundle/toolchains/x86-4.9/prebuilt/darwin-x86_64/bin/i686-linux-android-strip --strip-unneeded  /Users/Bene/Dropbox/Dokumente/OpticalDesign/Beamerscope/Android/BeamerscopeIlloptimization/holoscope/build/intermediates/ndkBuild/debug/lib/x86/libopencv_java3.so

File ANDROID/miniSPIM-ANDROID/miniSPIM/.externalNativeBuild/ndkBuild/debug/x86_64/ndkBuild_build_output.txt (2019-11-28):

rm -f /Users/Bene/Dropbox/Dokumente/OpticalDesign/Beamerscope/Android/BeamerscopeIlloptimization/holoscope/build/intermediates/ndkBuild/debug/lib/x86_64/lib*.so
rm -f /Users/Bene/Dropbox/Dokumente/OpticalDesign/Beamerscope/Android/BeamerscopeIlloptimization/holoscope/build/intermediates/ndkBuild/debug/lib/x86_64/gdbserver
rm -f /Users/Bene/Dropbox/Dokumente/OpticalDesign/Beamerscope/Android/BeamerscopeIlloptimization/holoscope/build/intermediates/ndkBuild/debug/lib/x86_64/gdb.setup
echo [x86_64] "Compile++      ": "native_microscope <= cvComplex.cpp"
/Users/Bene/Library/Android/sdk/ndk-bundle/toolchains/x86_64-4.9/prebuilt/darwin-x86_64/bin/x86_64-linux-android-g++ -MMD -MP -MF /Users/Bene/Dropbox/Dokumente/OpticalDesign/Beamerscope/Android/BeamerscopeIlloptimization/holoscope/.externalNativeBuild/ndkBuild/debug/obj/local/x86_64/objs/native_microscope/cvComplex.o.d -ffunction-sections -funwind-tables -fstack-protector-strong -no-canonical-prefixes  -g -fno-exceptions -fno-rtti -O2 -DNDEBUG  -I"/Users/Bene/Android/opencv3/sdk/native/jni/include/opencv" -I"/Users/Bene/Android/opencv3/sdk/native/jni/include" -I/Users/Bene/Android/opencv3/sdk/native/jni/include/ -I/Users/Bene/Dropbox/Dokumente/OpticalDesign/Beamerscope/Android/BeamerscopeIlloptimization/holoscope/src/main/jni -I/Users/Bene/Library/Android/sdk/ndk-bundle/sources/cxx-stl/gnu-libstdc++/4.9/include -I/Users/Bene/Library/Android/sdk/ndk-bundle/sources/cxx-stl/gnu-libstdc++/4.9/libs/x86_64/include -I/Users/Bene/Library/Android/sdk/ndk-bundle/sources/cxx-stl/gnu-libstdc++/4.9/include/backward -I/Users/Bene/Dropbox/Dokumente/OpticalDesign/Beamerscope/Android/BeamerscopeIlloptimization/holoscope/src/main/jni -DANDROID -fPIC -DANDROID -fsigned-char -Wa,--noexecstack -Wformat -Werror=format-security    -frtti -fexceptions  -isystem /Users/Bene/Library/Android/sdk/ndk-bundle/platforms/android-21/arch-x86_64/usr/include -c  /Users/Bene/Dropbox/Dokumente/OpticalDesign/Beamerscope/Android/BeamerscopeIlloptimization/holoscope/src/main/jni/cvComplex.cpp -o /Users/Bene/Dropbox/Dokumente/OpticalDesign/Beamerscope/Android/BeamerscopeIlloptimization/holoscope/.externalNativeBuild/ndkBuild/debug/obj/local/x86_64/objs/native_microscope/cvComplex.o 
echo [x86_64] "Compile++      ": "native_microscope <= common.cpp"
/Users/Bene/Library/Android/sdk/ndk-bundle/toolchains/x86_64-4.9/prebuilt/darwin-x86_64/bin/x86_64-linux-android-g++ -MMD -MP -MF /Users/Bene/Dropbox/Dokumente/OpticalDesign/Beamerscope/Android/BeamerscopeIlloptimization/holoscope/.externalNativeBuild/ndkBuild/debug/obj/local/x86_64/objs/native_microscope/common.o.d -ffunction-sections -funwind-tables -fstack-protector-strong -no-canonical-prefixes  -g -fno-exceptions -fno-rtti -O2 -DNDEBUG  -I"/Users/Bene/Android/opencv3/sdk/native/jni/include/opencv" -I"/Users/Bene/Android/opencv3/sdk/native/jni/include" -I/Users/Bene/Android/opencv3/sdk/native/jni/include/ -I/Users/Bene/Dropbox/Dokumente/OpticalDesign/Beamerscope/Android/BeamerscopeIlloptimization/holoscope/src/main/jni -I/Users/Bene/Library/Android/sdk/ndk-bundle/sources/cxx-stl/gnu-libstdc++/4.9/include -I/Users/Bene/Library/Android/sdk/ndk-bundle/sources/cxx-stl/gnu-libstdc++/4.9/libs/x86_64/include -I/Users/Bene/Library/Android/sdk/ndk-bundle/sources/cxx-stl/gnu-libstdc++/4.9/include/backward -I/Users/Bene/Dropbox/Dokumente/OpticalDesign/Beamerscope/Android/BeamerscopeIlloptimization/holoscope/src/main/jni -DANDROID -fPIC -DANDROID -fsigned-char -Wa,--noexecstack -Wformat -Werror=format-security    -frtti -fexceptions  -isystem /Users/Bene/Library/Android/sdk/ndk-bundle/platforms/android-21/arch-x86_64/usr/include -c  /Users/Bene/Dropbox/Dokumente/OpticalDesign/Beamerscope/Android/BeamerscopeIlloptimization/holoscope/src/main/jni/common.cpp -o /Users/Bene/Dropbox/Dokumente/OpticalDesign/Beamerscope/Android/BeamerscopeIlloptimization/holoscope/.externalNativeBuild/ndkBuild/debug/obj/local/x86_64/objs/native_microscope/common.o 
echo [x86_64] "Compile++      ": "native_microscope <= jni_qDPC.cpp"
/Users/Bene/Library/Android/sdk/ndk-bundle/toolchains/x86_64-4.9/prebuilt/darwin-x86_64/bin/x86_64-linux-android-g++ -MMD -MP -MF /Users/Bene/Dropbox/Dokumente/OpticalDesign/Beamerscope/Android/BeamerscopeIlloptimization/holoscope/.externalNativeBuild/ndkBuild/debug/obj/local/x86_64/objs/native_microscope/jni_qDPC.o.d -ffunction-sections -funwind-tables -fstack-protector-strong -no-canonical-prefixes  -g -fno-exceptions -fno-rtti -O2 -DNDEBUG  -I"/Users/Bene/Android/opencv3/sdk/native/jni/include/opencv" -I"/Users/Bene/Android/opencv3/sdk/native/jni/include" -I/Users/Bene/Android/opencv3/sdk/native/jni/include/ -I/Users/Bene/Dropbox/Dokumente/OpticalDesign/Beamerscope/Android/BeamerscopeIlloptimization/holoscope/src/main/jni -I/Users/Bene/Library/Android/sdk/ndk-bundle/sources/cxx-stl/gnu-libstdc++/4.9/include -I/Users/Bene/Library/Android/sdk/ndk-bundle/sources/cxx-stl/gnu-libstdc++/4.9/libs/x86_64/include -I/Users/Bene/Library/Android/sdk/ndk-bundle/sources/cxx-stl/gnu-libstdc++/4.9/include/backward -I/Users/Bene/Dropbox/Dokumente/OpticalDesign/Beamerscope/Android/BeamerscopeIlloptimization/holoscope/src/main/jni -DANDROID -fPIC -DANDROID -fsigned-char -Wa,--noexecstack -Wformat -Werror=format-security    -frtti -fexceptions  -isystem /Users/Bene/Library/Android/sdk/ndk-bundle/platforms/android-21/arch-x86_64/usr/include -c  /Users/Bene/Dropbox/Dokumente/OpticalDesign/Beamerscope/Android/BeamerscopeIlloptimization/holoscope/src/main/jni/jni_qDPC.cpp -o /Users/Bene/Dropbox/Dokumente/OpticalDesign/Beamerscope/Android/BeamerscopeIlloptimization/holoscope/.externalNativeBuild/ndkBuild/debug/obj/local/x86_64/objs/native_microscope/jni_qDPC.o 
echo [x86_64] "Compile++      ": "native_microscope <= jni_illpattern.cpp"
/Users/Bene/Library/Android/sdk/ndk-bundle/toolchains/x86_64-4.9/prebuilt/darwin-x86_64/bin/x86_64-linux-android-g++ -MMD -MP -MF /Users/Bene/Dropbox/Dokumente/OpticalDesign/Beamerscope/Android/BeamerscopeIlloptimization/holoscope/.externalNativeBuild/ndkBuild/debug/obj/local/x86_64/objs/native_microscope/jni_illpattern.o.d -ffunction-sections -funwind-tables -fstack-protector-strong -no-canonical-prefixes  -g -fno-exceptions -fno-rtti -O2 -DNDEBUG  -I"/Users/Bene/Android/opencv3/sdk/native/jni/include/opencv" -I"/Users/Bene/Android/opencv3/sdk/native/jni/include" -I/Users/Bene/Android/opencv3/sdk/native/jni/include/ -I/Users/Bene/Dropbox/Dokumente/OpticalDesign/Beamerscope/Android/BeamerscopeIlloptimization/holoscope/src/main/jni -I/Users/Bene/Library/Android/sdk/ndk-bundle/sources/cxx-stl/gnu-libstdc++/4.9/include -I/Users/Bene/Library/Android/sdk/ndk-bundle/sources/cxx-stl/gnu-libstdc++/4.9/libs/x86_64/include -I/Users/Bene/Library/Android/sdk/ndk-bundle/sources/cxx-stl/gnu-libstdc++/4.9/include/backward -I/Users/Bene/Dropbox/Dokumente/OpticalDesign/Beamerscope/Android/BeamerscopeIlloptimization/holoscope/src/main/jni -DANDROID -fPIC -DANDROID -fsigned-char -Wa,--noexecstack -Wformat -Werror=format-security    -frtti -fexceptions  -isystem /Users/Bene/Library/Android/sdk/ndk-bundle/platforms/android-21/arch-x86_64/usr/include -c  /Users/Bene/Dropbox/Dokumente/OpticalDesign/Beamerscope/Android/BeamerscopeIlloptimization/holoscope/src/main/jni/jni_illpattern.cpp -o /Users/Bene/Dropbox/Dokumente/OpticalDesign/Beamerscope/Android/BeamerscopeIlloptimization/holoscope/.externalNativeBuild/ndkBuild/debug/obj/local/x86_64/objs/native_microscope/jni_illpattern.o 
echo [x86_64] "Compile++      ": "native_microscope <= jni_illparameter.cpp"
/Users/Bene/Library/Android/sdk/ndk-bundle/toolchains/x86_64-4.9/prebuilt/darwin-x86_64/bin/x86_64-linux-android-g++ -MMD -MP -MF /Users/Bene/Dropbox/Dokumente/OpticalDesign/Beamerscope/Android/BeamerscopeIlloptimization/holoscope/.externalNativeBuild/ndkBuild/debug/obj/local/x86_64/objs/native_microscope/jni_illparameter.o.d -ffunction-sections -funwind-tables -fstack-protector-strong -no-canonical-prefixes  -g -fno-exceptions -fno-rtti -O2 -DNDEBUG  -I"/Users/Bene/Android/opencv3/sdk/native/jni/include/opencv" -I"/Users/Bene/Android/opencv3/sdk/native/jni/include" -I/Users/Bene/Android/opencv3/sdk/native/jni/include/ -I/Users/Bene/Dropbox/Dokumente/OpticalDesign/Beamerscope/Android/BeamerscopeIlloptimization/holoscope/src/main/jni -I/Users/Bene/Library/Android/sdk/ndk-bundle/sources/cxx-stl/gnu-libstdc++/4.9/include -I/Users/Bene/Library/Android/sdk/ndk-bundle/sources/cxx-stl/gnu-libstdc++/4.9/libs/x86_64/include -I/Users/Bene/Library/Android/sdk/ndk-bundle/sources/cxx-stl/gnu-libstdc++/4.9/include/backward -I/Users/Bene/Dropbox/Dokumente/OpticalDesign/Beamerscope/Android/BeamerscopeIlloptimization/holoscope/src/main/jni -DANDROID -fPIC -DANDROID -fsigned-char -Wa,--noexecstack -Wformat -Werror=format-security    -frtti -fexceptions  -isystem /Users/Bene/Library/Android/sdk/ndk-bundle/platforms/android-21/arch-x86_64/usr/include -c  /Users/Bene/Dropbox/Dokumente/OpticalDesign/Beamerscope/Android/BeamerscopeIlloptimization/holoscope/src/main/jni/jni_illparameter.cpp -o /Users/Bene/Dropbox/Dokumente/OpticalDesign/Beamerscope/Android/BeamerscopeIlloptimization/holoscope/.externalNativeBuild/ndkBuild/debug/obj/local/x86_64/objs/native_microscope/jni_illparameter.o 
echo [x86_64] "SharedLibrary  ": "libnative_microscope.so"
/Users/Bene/Library/Android/sdk/ndk-bundle/toolchains/x86_64-4.9/prebuilt/darwin-x86_64/bin/x86_64-linux-android-g++ -Wl,-soname,libnative_microscope.so -shared --sysroot=/Users/Bene/Library/Android/sdk/ndk-bundle/platforms/android-21/arch-x86_64 /Users/Bene/Dropbox/Dokumente/OpticalDesign/Beamerscope/Android/BeamerscopeIlloptimization/holoscope/.externalNativeBuild/ndkBuild/debug/obj/local/x86_64/objs/native_microscope/cvComplex.o /Users/Bene/Dropbox/Dokumente/OpticalDesign/Beamerscope/Android/BeamerscopeIlloptimization/holoscope/.externalNativeBuild/ndkBuild/debug/obj/local/x86_64/objs/native_microscope/common.o /Users/Bene/Dropbox/Dokumente/OpticalDesign/Beamerscope/Android/BeamerscopeIlloptimization/holoscope/.externalNativeBuild/ndkBuild/debug/obj/local/x86_64/objs/native_microscope/jni_qDPC.o /Users/Bene/Dropbox/Dokumente/OpticalDesign/Beamerscope/Android/BeamerscopeIlloptimization/holoscope/.externalNativeBuild/ndkBuild/debug/obj/local/x86_64/objs/native_microscope/jni_illpattern.o /Users/Bene/Dropbox/Dokumente/OpticalDesign/Beamerscope/Android/BeamerscopeIlloptimization/holoscope/.externalNativeBuild/ndkBuild/debug/obj/local/x86_64/objs/native_microscope/jni_illparameter.o /Users/Bene/Library/Android/sdk/ndk-bundle/sources/cxx-stl/gnu-libstdc++/4.9/libs/x86_64/libgnustl_static.a -lgcc /Users/Bene/Dropbox/Dokumente/OpticalDesign/Beamerscope/Android/BeamerscopeIlloptimization/holoscope/.externalNativeBuild/ndkBuild/debug/obj/local/x86_64/libopencv_java3.so -no-canonical-prefixes  -Wl,--build-id -Wl,--no-undefined -Wl,-z,noexecstack -Wl,-z,relro -Wl,-z,now -Wl,--warn-shared-textrel -Wl,--fatal-warnings  -L/Users/Bene/Library/Android/sdk/ndk-bundle/platforms/android-21/arch-x86_64/usr/lib64 -L/Users/Bene/Library/Android/sdk/ndk-bundle/platforms/android-21/arch-x86_64/usr/lib -llog -ldl -lc -lm -o /Users/Bene/Dropbox/Dokumente/OpticalDesign/Beamerscope/Android/BeamerscopeIlloptimization/holoscope/.externalNativeBuild/ndkBuild/debug/obj/local/x86_64/libnative_microscope.so
echo [x86_64] "Install        ": "libnative_microscope.so => /Users/Bene/Dropbox/Dokumente/OpticalDesign/Beamerscope/Android/BeamerscopeIlloptimization/holoscope/build/intermediates/ndkBuild/debug/lib/x86_64/libnative_microscope.so"
install -p /Users/Bene/Dropbox/Dokumente/OpticalDesign/Beamerscope/Android/BeamerscopeIlloptimization/holoscope/.externalNativeBuild/ndkBuild/debug/obj/local/x86_64/libnative_microscope.so /Users/Bene/Dropbox/Dokumente/OpticalDesign/Beamerscope/Android/BeamerscopeIlloptimization/holoscope/build/intermediates/ndkBuild/debug/lib/x86_64/libnative_microscope.so
/Users/Bene/Library/Android/sdk/ndk-bundle/toolchains/x86_64-4.9/prebuilt/darwin-x86_64/bin/x86_64-linux-android-strip --strip-unneeded  /Users/Bene/Dropbox/Dokumente/OpticalDesign/Beamerscope/Android/BeamerscopeIlloptimization/holoscope/build/intermediates/ndkBuild/debug/lib/x86_64/libnative_microscope.so
echo [x86_64] "Install        ": "libopencv_java3.so => /Users/Bene/Dropbox/Dokumente/OpticalDesign/Beamerscope/Android/BeamerscopeIlloptimization/holoscope/build/intermediates/ndkBuild/debug/lib/x86_64/libopencv_java3.so"
install -p /Users/Bene/Dropbox/Dokumente/OpticalDesign/Beamerscope/Android/BeamerscopeIlloptimization/holoscope/.externalNativeBuild/ndkBuild/debug/obj/local/x86_64/libopencv_java3.so /Users/Bene/Dropbox/Dokumente/OpticalDesign/Beamerscope/Android/BeamerscopeIlloptimization/holoscope/build/intermediates/ndkBuild/debug/lib/x86_64/libopencv_java3.so
/Users/Bene/Library/Android/sdk/ndk-bundle/toolchains/x86_64-4.9/prebuilt/darwin-x86_64/bin/x86_64-linux-android-strip --strip-unneeded  /Users/Bene/Dropbox/Dokumente/OpticalDesign/Beamerscope/Android/BeamerscopeIlloptimization/holoscope/build/intermediates/ndkBuild/debug/lib/x86_64/libopencv_java3.so

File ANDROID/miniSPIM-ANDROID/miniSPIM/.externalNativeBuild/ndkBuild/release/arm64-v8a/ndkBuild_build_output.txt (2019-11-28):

rm -f /Users/Bene/Dropbox/Dokumente/OpticalDesign/Beamerscope/Android/BeamerscopeIlloptimization/holoscope/build/intermediates/ndkBuild/release/lib/arm64-v8a/lib*.so
rm -f /Users/Bene/Dropbox/Dokumente/OpticalDesign/Beamerscope/Android/BeamerscopeIlloptimization/holoscope/build/intermediates/ndkBuild/release/lib/arm64-v8a/gdbserver
rm -f /Users/Bene/Dropbox/Dokumente/OpticalDesign/Beamerscope/Android/BeamerscopeIlloptimization/holoscope/build/intermediates/ndkBuild/release/lib/arm64-v8a/gdb.setup
mkdir -p /Users/Bene/Dropbox/Dokumente/OpticalDesign/Beamerscope/Android/BeamerscopeIlloptimization/holoscope/.externalNativeBuild/ndkBuild/release/obj/local/arm64-v8a/objs/native_microscope
echo [arm64-v8a] "Compile++      ": "native_microscope <= cvComplex.cpp"
/Users/Bene/Library/Android/sdk/ndk-bundle/toolchains/aarch64-linux-android-4.9/prebuilt/darwin-x86_64/bin/aarch64-linux-android-g++ -MMD -MP -MF /Users/Bene/Dropbox/Dokumente/OpticalDesign/Beamerscope/Android/BeamerscopeIlloptimization/holoscope/.externalNativeBuild/ndkBuild/release/obj/local/arm64-v8a/objs/native_microscope/cvComplex.o.d -fpic -ffunction-sections -funwind-tables -fstack-protector-strong -no-canonical-prefixes  -g -fno-exceptions -fno-rtti -O2 -DNDEBUG  -I"/Users/Bene/Android/opencv3/sdk/native/jni/include/opencv" -I"/Users/Bene/Android/opencv3/sdk/native/jni/include" -I/Users/Bene/Android/opencv3/sdk/native/jni/include/ -I/Users/Bene/Dropbox/Dokumente/OpticalDesign/Beamerscope/Android/BeamerscopeIlloptimization/holoscope/src/main/jni -I/Users/Bene/Library/Android/sdk/ndk-bundle/sources/cxx-stl/gnu-libstdc++/4.9/include -I/Users/Bene/Library/Android/sdk/ndk-bundle/sources/cxx-stl/gnu-libstdc++/4.9/libs/arm64-v8a/include -I/Users/Bene/Library/Android/sdk/ndk-bundle/sources/cxx-stl/gnu-libstdc++/4.9/include/backward -I/Users/Bene/Dropbox/Dokumente/OpticalDesign/Beamerscope/Android/BeamerscopeIlloptimization/holoscope/src/main/jni -DANDROID -fPIC -DANDROID -fsigned-char -Wa,--noexecstack -Wformat -Werror=format-security    -frtti -fexceptions  -isystem /Users/Bene/Library/Android/sdk/ndk-bundle/platforms/android-21/arch-arm64/usr/include -c  /Users/Bene/Dropbox/Dokumente/OpticalDesign/Beamerscope/Android/BeamerscopeIlloptimization/holoscope/src/main/jni/cvComplex.cpp -o /Users/Bene/Dropbox/Dokumente/OpticalDesign/Beamerscope/Android/BeamerscopeIlloptimization/holoscope/.externalNativeBuild/ndkBuild/release/obj/local/arm64-v8a/objs/native_microscope/cvComplex.o 
echo [arm64-v8a] "Compile++      ": "native_microscope <= common.cpp"
/Users/Bene/Library/Android/sdk/ndk-bundle/toolchains/aarch64-linux-android-4.9/prebuilt/darwin-x86_64/bin/aarch64-linux-android-g++ -MMD -MP -MF /Users/Bene/Dropbox/Dokumente/OpticalDesign/Beamerscope/Android/BeamerscopeIlloptimization/holoscope/.externalNativeBuild/ndkBuild/release/obj/local/arm64-v8a/objs/native_microscope/common.o.d -fpic -ffunction-sections -funwind-tables -fstack-protector-strong -no-canonical-prefixes  -g -fno-exceptions -fno-rtti -O2 -DNDEBUG  -I"/Users/Bene/Android/opencv3/sdk/native/jni/include/opencv" -I"/Users/Bene/Android/opencv3/sdk/native/jni/include" -I/Users/Bene/Android/opencv3/sdk/native/jni/include/ -I/Users/Bene/Dropbox/Dokumente/OpticalDesign/Beamerscope/Android/BeamerscopeIlloptimization/holoscope/src/main/jni -I/Users/Bene/Library/Android/sdk/ndk-bundle/sources/cxx-stl/gnu-libstdc++/4.9/include -I/Users/Bene/Library/Android/sdk/ndk-bundle/sources/cxx-stl/gnu-libstdc++/4.9/libs/arm64-v8a/include -I/Users/Bene/Library/Android/sdk/ndk-bundle/sources/cxx-stl/gnu-libstdc++/4.9/include/backward -I/Users/Bene/Dropbox/Dokumente/OpticalDesign/Beamerscope/Android/BeamerscopeIlloptimization/holoscope/src/main/jni -DANDROID -fPIC -DANDROID -fsigned-char -Wa,--noexecstack -Wformat -Werror=format-security    -frtti -fexceptions  -isystem /Users/Bene/Library/Android/sdk/ndk-bundle/platforms/android-21/arch-arm64/usr/include -c  /Users/Bene/Dropbox/Dokumente/OpticalDesign/Beamerscope/Android/BeamerscopeIlloptimization/holoscope/src/main/jni/common.cpp -o /Users/Bene/Dropbox/Dokumente/OpticalDesign/Beamerscope/Android/BeamerscopeIlloptimization/holoscope/.externalNativeBuild/ndkBuild/release/obj/local/arm64-v8a/objs/native_microscope/common.o 
echo [arm64-v8a] "Compile++      ": "native_microscope <= jni_qDPC.cpp"
/Users/Bene/Library/Android/sdk/ndk-bundle/toolchains/aarch64-linux-android-4.9/prebuilt/darwin-x86_64/bin/aarch64-linux-android-g++ -MMD -MP -MF /Users/Bene/Dropbox/Dokumente/OpticalDesign/Beamerscope/Android/BeamerscopeIlloptimization/holoscope/.externalNativeBuild/ndkBuild/release/obj/local/arm64-v8a/objs/native_microscope/jni_qDPC.o.d -fpic -ffunction-sections -funwind-tables -fstack-protector-strong -no-canonical-prefixes  -g -fno-exceptions -fno-rtti -O2 -DNDEBUG  -I"/Users/Bene/Android/opencv3/sdk/native/jni/include/opencv" -I"/Users/Bene/Android/opencv3/sdk/native/jni/include" -I/Users/Bene/Android/opencv3/sdk/native/jni/include/ -I/Users/Bene/Dropbox/Dokumente/OpticalDesign/Beamerscope/Android/BeamerscopeIlloptimization/holoscope/src/main/jni -I/Users/Bene/Library/Android/sdk/ndk-bundle/sources/cxx-stl/gnu-libstdc++/4.9/include -I/Users/Bene/Library/Android/sdk/ndk-bundle/sources/cxx-stl/gnu-libstdc++/4.9/libs/arm64-v8a/include -I/Users/Bene/Library/Android/sdk/ndk-bundle/sources/cxx-stl/gnu-libstdc++/4.9/include/backward -I/Users/Bene/Dropbox/Dokumente/OpticalDesign/Beamerscope/Android/BeamerscopeIlloptimization/holoscope/src/main/jni -DANDROID -fPIC -DANDROID -fsigned-char -Wa,--noexecstack -Wformat -Werror=format-security    -frtti -fexceptions  -isystem /Users/Bene/Library/Android/sdk/ndk-bundle/platforms/android-21/arch-arm64/usr/include -c  /Users/Bene/Dropbox/Dokumente/OpticalDesign/Beamerscope/Android/BeamerscopeIlloptimization/holoscope/src/main/jni/jni_qDPC.cpp -o /Users/Bene/Dropbox/Dokumente/OpticalDesign/Beamerscope/Android/BeamerscopeIlloptimization/holoscope/.externalNativeBuild/ndkBuild/release/obj/local/arm64-v8a/objs/native_microscope/jni_qDPC.o 
echo [arm64-v8a] "Compile++      ": "native_microscope <= jni_illpattern.cpp"
/Users/Bene/Library/Android/sdk/ndk-bundle/toolchains/aarch64-linux-android-4.9/prebuilt/darwin-x86_64/bin/aarch64-linux-android-g++ -MMD -MP -MF /Users/Bene/Dropbox/Dokumente/OpticalDesign/Beamerscope/Android/BeamerscopeIlloptimization/holoscope/.externalNativeBuild/ndkBuild/release/obj/local/arm64-v8a/objs/native_microscope/jni_illpattern.o.d -fpic -ffunction-sections -funwind-tables -fstack-protector-strong -no-canonical-prefixes  -g -fno-exceptions -fno-rtti -O2 -DNDEBUG  -I"/Users/Bene/Android/opencv3/sdk/native/jni/include/opencv" -I"/Users/Bene/Android/opencv3/sdk/native/jni/include" -I/Users/Bene/Android/opencv3/sdk/native/jni/include/ -I/Users/Bene/Dropbox/Dokumente/OpticalDesign/Beamerscope/Android/BeamerscopeIlloptimization/holoscope/src/main/jni -I/Users/Bene/Library/Android/sdk/ndk-bundle/sources/cxx-stl/gnu-libstdc++/4.9/include -I/Users/Bene/Library/Android/sdk/ndk-bundle/sources/cxx-stl/gnu-libstdc++/4.9/libs/arm64-v8a/include -I/Users/Bene/Library/Android/sdk/ndk-bundle/sources/cxx-stl/gnu-libstdc++/4.9/include/backward -I/Users/Bene/Dropbox/Dokumente/OpticalDesign/Beamerscope/Android/BeamerscopeIlloptimization/holoscope/src/main/jni -DANDROID -fPIC -DANDROID -fsigned-char -Wa,--noexecstack -Wformat -Werror=format-security    -frtti -fexceptions  -isystem /Users/Bene/Library/Android/sdk/ndk-bundle/platforms/android-21/arch-arm64/usr/include -c  /Users/Bene/Dropbox/Dokumente/OpticalDesign/Beamerscope/Android/BeamerscopeIlloptimization/holoscope/src/main/jni/jni_illpattern.cpp -o /Users/Bene/Dropbox/Dokumente/OpticalDesign/Beamerscope/Android/BeamerscopeIlloptimization/holoscope/.externalNativeBuild/ndkBuild/release/obj/local/arm64-v8a/objs/native_microscope/jni_illpattern.o 
echo [arm64-v8a] "Compile++      ": "native_microscope <= jni_illparameter.cpp"
/Users/Bene/Library/Android/sdk/ndk-bundle/toolchains/aarch64-linux-android-4.9/prebuilt/darwin-x86_64/bin/aarch64-linux-android-g++ -MMD -MP -MF /Users/Bene/Dropbox/Dokumente/OpticalDesign/Beamerscope/Android/BeamerscopeIlloptimization/holoscope/.externalNativeBuild/ndkBuild/release/obj/local/arm64-v8a/objs/native_microscope/jni_illparameter.o.d -fpic -ffunction-sections -funwind-tables -fstack-protector-strong -no-canonical-prefixes  -g -fno-exceptions -fno-rtti -O2 -DNDEBUG  -I"/Users/Bene/Android/opencv3/sdk/native/jni/include/opencv" -I"/Users/Bene/Android/opencv3/sdk/native/jni/include" -I/Users/Bene/Android/opencv3/sdk/native/jni/include/ -I/Users/Bene/Dropbox/Dokumente/OpticalDesign/Beamerscope/Android/BeamerscopeIlloptimization/holoscope/src/main/jni -I/Users/Bene/Library/Android/sdk/ndk-bundle/sources/cxx-stl/gnu-libstdc++/4.9/include -I/Users/Bene/Library/Android/sdk/ndk-bundle/sources/cxx-stl/gnu-libstdc++/4.9/libs/arm64-v8a/include -I/Users/Bene/Library/Android/sdk/ndk-bundle/sources/cxx-stl/gnu-libstdc++/4.9/include/backward -I/Users/Bene/Dropbox/Dokumente/OpticalDesign/Beamerscope/Android/BeamerscopeIlloptimization/holoscope/src/main/jni -DANDROID -fPIC -DANDROID -fsigned-char -Wa,--noexecstack -Wformat -Werror=format-security    -frtti -fexceptions  -isystem /Users/Bene/Library/Android/sdk/ndk-bundle/platforms/android-21/arch-arm64/usr/include -c  /Users/Bene/Dropbox/Dokumente/OpticalDesign/Beamerscope/Android/BeamerscopeIlloptimization/holoscope/src/main/jni/jni_illparameter.cpp -o /Users/Bene/Dropbox/Dokumente/OpticalDesign/Beamerscope/Android/BeamerscopeIlloptimization/holoscope/.externalNativeBuild/ndkBuild/release/obj/local/arm64-v8a/objs/native_microscope/jni_illparameter.o 
mkdir -p /Users/Bene/Dropbox/Dokumente/OpticalDesign/Beamerscope/Android/BeamerscopeIlloptimization/holoscope/.externalNativeBuild/ndkBuild/release/obj/local/arm64-v8a
echo [arm64-v8a] "Prebuilt       ": "libopencv_java3.so <= /Users/Bene/Android/opencv3/sdk/native/jni/../libs/arm64-v8a/"
cp -f /Users/Bene/Android/opencv3/sdk/native/jni/../libs/arm64-v8a/libopencv_java3.so /Users/Bene/Dropbox/Dokumente/OpticalDesign/Beamerscope/Android/BeamerscopeIlloptimization/holoscope/.externalNativeBuild/ndkBuild/release/obj/local/arm64-v8a/libopencv_java3.so
echo [arm64-v8a] "SharedLibrary  ": "libnative_microscope.so"
/Users/Bene/Library/Android/sdk/ndk-bundle/toolchains/aarch64-linux-android-4.9/prebuilt/darwin-x86_64/bin/aarch64-linux-android-g++ -Wl,-soname,libnative_microscope.so -shared --sysroot=/Users/Bene/Library/Android/sdk/ndk-bundle/platforms/android-21/arch-arm64 /Users/Bene/Dropbox/Dokumente/OpticalDesign/Beamerscope/Android/BeamerscopeIlloptimization/holoscope/.externalNativeBuild/ndkBuild/release/obj/local/arm64-v8a/objs/native_microscope/cvComplex.o /Users/Bene/Dropbox/Dokumente/OpticalDesign/Beamerscope/Android/BeamerscopeIlloptimization/holoscope/.externalNativeBuild/ndkBuild/release/obj/local/arm64-v8a/objs/native_microscope/common.o /Users/Bene/Dropbox/Dokumente/OpticalDesign/Beamerscope/Android/BeamerscopeIlloptimization/holoscope/.externalNativeBuild/ndkBuild/release/obj/local/arm64-v8a/objs/native_microscope/jni_qDPC.o /Users/Bene/Dropbox/Dokumente/OpticalDesign/Beamerscope/Android/BeamerscopeIlloptimization/holoscope/.externalNativeBuild/ndkBuild/release/obj/local/arm64-v8a/objs/native_microscope/jni_illpattern.o /Users/Bene/Dropbox/Dokumente/OpticalDesign/Beamerscope/Android/BeamerscopeIlloptimization/holoscope/.externalNativeBuild/ndkBuild/release/obj/local/arm64-v8a/objs/native_microscope/jni_illparameter.o /Users/Bene/Library/Android/sdk/ndk-bundle/sources/cxx-stl/gnu-libstdc++/4.9/libs/arm64-v8a/libgnustl_static.a -lgcc /Users/Bene/Dropbox/Dokumente/OpticalDesign/Beamerscope/Android/BeamerscopeIlloptimization/holoscope/.externalNativeBuild/ndkBuild/release/obj/local/arm64-v8a/libopencv_java3.so -no-canonical-prefixes  -Wl,--build-id -Wl,--no-undefined -Wl,-z,noexecstack -Wl,-z,relro -Wl,-z,now -Wl,--warn-shared-textrel -Wl,--fatal-warnings  -L/Users/Bene/Library/Android/sdk/ndk-bundle/platforms/android-21/arch-arm64/usr/lib -llog -ldl -lc -lm -o /Users/Bene/Dropbox/Dokumente/OpticalDesign/Beamerscope/Android/BeamerscopeIlloptimization/holoscope/.externalNativeBuild/ndkBuild/release/obj/local/arm64-v8a/libnative_microscope.so
mkdir -p /Users/Bene/Dropbox/Dokumente/OpticalDesign/Beamerscope/Android/BeamerscopeIlloptimization/holoscope/build/intermediates/ndkBuild/release/lib/arm64-v8a
echo [arm64-v8a] "Install        ": "libnative_microscope.so => /Users/Bene/Dropbox/Dokumente/OpticalDesign/Beamerscope/Android/BeamerscopeIlloptimization/holoscope/build/intermediates/ndkBuild/release/lib/arm64-v8a/libnative_microscope.so"
install -p /Users/Bene/Dropbox/Dokumente/OpticalDesign/Beamerscope/Android/BeamerscopeIlloptimization/holoscope/.externalNativeBuild/ndkBuild/release/obj/local/arm64-v8a/libnative_microscope.so /Users/Bene/Dropbox/Dokumente/OpticalDesign/Beamerscope/Android/BeamerscopeIlloptimization/holoscope/build/intermediates/ndkBuild/release/lib/arm64-v8a/libnative_microscope.so
/Users/Bene/Library/Android/sdk/ndk-bundle/toolchains/aarch64-linux-android-4.9/prebuilt/darwin-x86_64/bin/aarch64-linux-android-strip --strip-unneeded  /Users/Bene/Dropbox/Dokumente/OpticalDesign/Beamerscope/Android/BeamerscopeIlloptimization/holoscope/build/intermediates/ndkBuild/release/lib/arm64-v8a/libnative_microscope.so
echo [arm64-v8a] "Install        ": "libopencv_java3.so => /Users/Bene/Dropbox/Dokumente/OpticalDesign/Beamerscope/Android/BeamerscopeIlloptimization/holoscope/build/intermediates/ndkBuild/release/lib/arm64-v8a/libopencv_java3.so"
install -p /Users/Bene/Dropbox/Dokumente/OpticalDesign/Beamerscope/Android/BeamerscopeIlloptimization/holoscope/.externalNativeBuild/ndkBuild/release/obj/local/arm64-v8a/libopencv_java3.so /Users/Bene/Dropbox/Dokumente/OpticalDesign/Beamerscope/Android/BeamerscopeIlloptimization/holoscope/build/intermediates/ndkBuild/release/lib/arm64-v8a/libopencv_java3.so
/Users/Bene/Library/Android/sdk/ndk-bundle/toolchains/aarch64-linux-android-4.9/prebuilt/darwin-x86_64/bin/aarch64-linux-android-strip --strip-unneeded  /Users/Bene/Dropbox/Dokumente/OpticalDesign/Beamerscope/Android/BeamerscopeIlloptimization/holoscope/build/intermediates/ndkBuild/release/lib/arm64-v8a/libopencv_java3.so

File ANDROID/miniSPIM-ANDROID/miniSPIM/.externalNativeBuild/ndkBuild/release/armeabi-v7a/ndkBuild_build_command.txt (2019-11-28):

Executable : /Users/Bene/Library/Android/sdk/ndk-bundle/ndk-build
arguments : 
NDK_PROJECT_PATH=null
APP_BUILD_SCRIPT=/Users/Bene/Dropbox/Dokumente/OpticalDesign/Beamerscope/Android/BeamerscopeIlloptimization/holoscope/src/main/jni/Android.mk
NDK_APPLICATION_MK=/Users/Bene/Dropbox/Dokumente/OpticalDesign/Beamerscope/Android/BeamerscopeIlloptimization/holoscope/src/main/jni/Application.mk
APP_ABI=armeabi-v7a
NDK_ALL_ABIS=armeabi-v7a
NDEBUG=0
APP_PLATFORM=android-19
NDK_OUT=/Users/Bene/Dropbox/Dokumente/OpticalDesign/Beamerscope/Android/BeamerscopeIlloptimization/holoscope/.externalNativeBuild/ndkBuild/release/obj
NDK_LIBS_OUT=/Users/Bene/Dropbox/Dokumente/OpticalDesign/Beamerscope/Android/BeamerscopeIlloptimization/holoscope/build/intermediates/ndkBuild/release/lib
-n
jvmArgs :

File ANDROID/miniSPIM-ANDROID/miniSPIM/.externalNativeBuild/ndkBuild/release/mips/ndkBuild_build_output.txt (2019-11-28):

rm -f /Users/Bene/Dropbox/Dokumente/OpticalDesign/Beamerscope/Android/BeamerscopeIlloptimization/holoscope/build/intermediates/ndkBuild/release/lib/mips/lib*.so
rm -f /Users/Bene/Dropbox/Dokumente/OpticalDesign/Beamerscope/Android/BeamerscopeIlloptimization/holoscope/build/intermediates/ndkBuild/release/lib/mips/gdbserver
rm -f /Users/Bene/Dropbox/Dokumente/OpticalDesign/Beamerscope/Android/BeamerscopeIlloptimization/holoscope/build/intermediates/ndkBuild/release/lib/mips/gdb.setup
mkdir -p /Users/Bene/Dropbox/Dokumente/OpticalDesign/Beamerscope/Android/BeamerscopeIlloptimization/holoscope/.externalNativeBuild/ndkBuild/release/obj/local/mips/objs/native_microscope
echo [mips] "Compile++      ": "native_microscope <= cvComplex.cpp"
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

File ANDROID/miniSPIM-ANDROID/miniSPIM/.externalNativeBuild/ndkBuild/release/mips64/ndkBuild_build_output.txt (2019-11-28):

rm -f /Users/Bene/Dropbox/Dokumente/OpticalDesign/Beamerscope/Android/BeamerscopeIlloptimization/holoscope/build/intermediates/ndkBuild/release/lib/mips64/lib*.so
rm -f /Users/Bene/Dropbox/Dokumente/OpticalDesign/Beamerscope/Android/BeamerscopeIlloptimization/holoscope/build/intermediates/ndkBuild/release/lib/mips64/gdbserver
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

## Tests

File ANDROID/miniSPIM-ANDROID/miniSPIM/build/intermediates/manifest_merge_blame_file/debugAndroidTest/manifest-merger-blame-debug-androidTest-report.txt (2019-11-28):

1<?xml version="1.0" encoding="utf-8"?>
2<manifest xmlns:android="http://schemas.android.com/apk/res/android"
3    package="de.minispim.test" >
4
5    <uses-sdk
5-->/Users/bene/Dropbox/Dokumente/Promotion/PROJECTS/miniSPIM/ANDROID/miniSPIM-ANDROID/miniSPIM/build/intermediates/tmp/manifest/androidTest/debug/manifestMerger852973377580385522.xml:5:5-74
6        android:minSdkVersion="21"
6-->/Users/bene/Dropbox/Dokumente/Promotion/PROJECTS/miniSPIM/ANDROID/miniSPIM-ANDROID/miniSPIM/build/intermediates/tmp/manifest/androidTest/debug/manifestMerger852973377580385522.xml:5:15-41
7        android:targetSdkVersion="26" />
7-->/Users/bene/Dropbox/Dokumente/Promotion/PROJECTS/miniSPIM/ANDROID/miniSPIM-ANDROID/miniSPIM/build/intermediates/tmp/manifest/androidTest/debug/manifestMerger852973377580385522.xml:5:42-71
8
9    <instrumentation
9-->/Users/bene/Dropbox/Dokumente/Promotion/PROJECTS/miniSPIM/ANDROID/miniSPIM-ANDROID/miniSPIM/build/intermediates/tmp/manifest/androidTest/debug/manifestMerger852973377580385522.xml:11:5-15:61
10        android:name="android.test.InstrumentationTestRunner"
10-->/Users/bene/Dropbox/Dokumente/Promotion/PROJECTS/miniSPIM/ANDROID/miniSPIM-ANDROID/miniSPIM/build/intermediates/tmp/manifest/androidTest/debug/manifestMerger852973377580385522.xml:11:22-75
11        android:functionalTest="false"
11-->/Users/bene/Dropbox/Dokumente/Promotion/PROJECTS/miniSPIM/ANDROID/miniSPIM-ANDROID/miniSPIM/build/intermediates/tmp/manifest/androidTest/debug/manifestMerger852973377580385522.xml:14:22-52
12        android:handleProfiling="false"
12-->/Users/bene/Dropbox/Dokumente/Promotion/PROJECTS/miniSPIM/ANDROID/miniSPIM-ANDROID/miniSPIM/build/intermediates/tmp/manifest/androidTest/debug/manifestMerger852973377580385522.xml:13:22-53
13        android:label="Tests for de.minispim"
13-->/Users/bene/Dropbox/Dokumente/Promotion/PROJECTS/miniSPIM/ANDROID/miniSPIM-ANDROID/miniSPIM/build/intermediates/tmp/manifest/androidTest/debug/manifestMerger852973377580385522.xml:15:22-59
14        android:targetPackage="de.minispim" />
14-->/Users/bene/Dropbox/Dokumente/Promotion/PROJECTS/miniSPIM/ANDROID/miniSPIM-ANDROID/miniSPIM/build/intermediates/tmp/manifest/androidTest/debug/manifestMerger852973377580385522.xml:12:22-57
15
16    <application android:debuggable="true" >
16-->/Users/bene/Dropbox/Dokumente/Promotion/PROJECTS/miniSPIM/ANDROID/miniSPIM-ANDROID/miniSPIM/build/intermediates/tmp/manifest/androidTest/debug/manifestMerger852973377580385522.xml:7:5-9:19
16-->/Users/bene/Dropbox/Dokumente/Promotion/PROJECTS/miniSPIM/ANDROID/miniSPIM-ANDROID/miniSPIM/build/intermediates/tmp/manifest/androidTest/debug/manifestMerger852973377580385522.xml:7:18-43
17        <uses-library android:name="android.test.runner" />
17-->/Users/bene/Dropbox/Dokumente/Promotion/PROJECTS/miniSPIM/ANDROID/miniSPIM-ANDROID/miniSPIM/build/intermediates/tmp/manifest/androidTest/debug/manifestMerger852973377580385522.xml:8:9-60
17-->/Users/bene/Dropbox/Dokumente/Promotion/PROJECTS/miniSPIM/ANDROID/miniSPIM-ANDROID/miniSPIM/build/intermediates/tmp/manifest/androidTest/debug/manifestMerger852973377580385522.xml:8:23-57
18    </application>
19
20</manifest>

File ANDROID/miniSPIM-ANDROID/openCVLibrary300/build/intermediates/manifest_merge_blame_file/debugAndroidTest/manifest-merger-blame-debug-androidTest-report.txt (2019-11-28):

1<?xml version="1.0" encoding="utf-8"?>
2<manifest xmlns:android="http://schemas.android.com/apk/res/android"
3    package="org.opencv.test" >
4
5    <uses-sdk
5-->/Users/bene/Dropbox/Dokumente/Promotion/PROJECTS/miniSPIM/ANDROID/miniSPIM-ANDROID/openCVLibrary300/build/intermediates/tmp/manifest/androidTest/debug/manifestMerger6300380192544054112.xml:5:5-74
6        android:minSdkVersion="21"
6-->/Users/bene/Dropbox/Dokumente/Promotion/PROJECTS/miniSPIM/ANDROID/miniSPIM-ANDROID/openCVLibrary300/build/intermediates/tmp/manifest/androidTest/debug/manifestMerger6300380192544054112.xml:5:15-41
7        android:targetSdkVersion="26" />
7-->/Users/bene/Dropbox/Dokumente/Promotion/PROJECTS/miniSPIM/ANDROID/miniSPIM-ANDROID/openCVLibrary300/build/intermediates/tmp/manifest/androidTest/debug/manifestMerger6300380192544054112.xml:5:42-71
8
9    <instrumentation
9-->/Users/bene/Dropbox/Dokumente/Promotion/PROJECTS/miniSPIM/ANDROID/miniSPIM-ANDROID/openCVLibrary300/build/intermediates/tmp/manifest/androidTest/debug/manifestMerger6300380192544054112.xml:11:5-15:65
10        android:name="android.test.InstrumentationTestRunner"
10-->/Users/bene/Dropbox/Dokumente/Promotion/PROJECTS/miniSPIM/ANDROID/miniSPIM-ANDROID/openCVLibrary300/build/intermediates/tmp/manifest/androidTest/debug/manifestMerger6300380192544054112.xml:11:22-75
11        android:functionalTest="false"
11-->/Users/bene/Dropbox/Dokumente/Promotion/PROJECTS/miniSPIM/ANDROID/miniSPIM-ANDROID/openCVLibrary300/build/intermediates/tmp/manifest/androidTest/debug/manifestMerger6300380192544054112.xml:14:22-52
12        android:handleProfiling="false"
12-->/Users/bene/Dropbox/Dokumente/Promotion/PROJECTS/miniSPIM/ANDROID/miniSPIM-ANDROID/openCVLibrary300/build/intermediates/tmp/manifest/androidTest/debug/manifestMerger6300380192544054112.xml:13:22-53
13        android:label="Tests for org.opencv.test"
13-->/Users/bene/Dropbox/Dokumente/Promotion/PROJECTS/miniSPIM/ANDROID/miniSPIM-ANDROID/openCVLibrary300/build/intermediates/tmp/manifest/androidTest/debug/manifestMerger6300380192544054112.xml:15:22-63
14        android:targetPackage="org.opencv.test" />
14-->/Users/bene/Dropbox/Dokumente/Promotion/PROJECTS/miniSPIM/ANDROID/miniSPIM-ANDROID/openCVLibrary300/build/intermediates/tmp/manifest/androidTest/debug/manifestMerger6300380192544054112.xml:12:22-61
15
16    <application android:debuggable="true" >
16-->/Users/bene/Dropbox/Dokumente/Promotion/PROJECTS/miniSPIM/ANDROID/miniSPIM-ANDROID/openCVLibrary300/build/intermediates/tmp/manifest/androidTest/debug/manifestMerger6300380192544054112.xml:7:5-9:19
16-->/Users/bene/Dropbox/Dokumente/Promotion/PROJECTS/miniSPIM/ANDROID/miniSPIM-ANDROID/openCVLibrary300/build/intermediates/tmp/manifest/androidTest/debug/manifestMerger6300380192544054112.xml:7:18-43
17        <uses-library android:name="android.test.runner" />
17-->/Users/bene/Dropbox/Dokumente/Promotion/PROJECTS/miniSPIM/ANDROID/miniSPIM-ANDROID/openCVLibrary300/build/intermediates/tmp/manifest/androidTest/debug/manifestMerger6300380192544054112.xml:8:9-60
17-->/Users/bene/Dropbox/Dokumente/Promotion/PROJECTS/miniSPIM/ANDROID/miniSPIM-ANDROID/openCVLibrary300/build/intermediates/tmp/manifest/androidTest/debug/manifestMerger6300380192544054112.xml:8:23-57
18    </application>
19
20</manifest>

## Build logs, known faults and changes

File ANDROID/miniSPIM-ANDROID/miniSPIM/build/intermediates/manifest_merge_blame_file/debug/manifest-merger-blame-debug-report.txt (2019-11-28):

1<?xml version="1.0" encoding="utf-8"?>
2<manifest xmlns:android="http://schemas.android.com/apk/res/android"
3    package="de.minispim" >
4
5    <uses-sdk
6        android:minSdkVersion="21"
6-->/Users/bene/Dropbox/Dokumente/Promotion/PROJECTS/miniSPIM/ANDROID/miniSPIM-ANDROID/miniSPIM/src/main/AndroidManifest.xml
7        android:targetSdkVersion="26" />
7-->/Users/bene/Dropbox/Dokumente/Promotion/PROJECTS/miniSPIM/ANDROID/miniSPIM-ANDROID/miniSPIM/src/main/AndroidManifest.xml
8
9    <!-- A camera with RAW capability is required to use this application -->
10    <uses-feature android:name="android.hardware.camera" />
10-->/Users/bene/Dropbox/Dokumente/Promotion/PROJECTS/miniSPIM/ANDROID/miniSPIM-ANDROID/miniSPIM/src/main/AndroidManifest.xml:6:5-60
10-->/Users/bene/Dropbox/Dokumente/Promotion/PROJECTS/miniSPIM/ANDROID/miniSPIM-ANDROID/miniSPIM/src/main/AndroidManifest.xml:6:19-57
11    <uses-feature android:name="android.hardware.camera.raw" />
11-->/Users/bene/Dropbox/Dokumente/Promotion/PROJECTS/miniSPIM/ANDROID/miniSPIM-ANDROID/miniSPIM/src/main/AndroidManifest.xml:7:5-64
11-->/Users/bene/Dropbox/Dokumente/Promotion/PROJECTS/miniSPIM/ANDROID/miniSPIM-ANDROID/miniSPIM/src/main/AndroidManifest.xml:7:19-61
12
13    <!-- Min/target SDK versions (<uses-sdk>) managed by build.gradle -->
14    <uses-permission android:name="android.permission.CAMERA" />
14-->/Users/bene/Dropbox/Dokumente/Promotion/PROJECTS/miniSPIM/ANDROID/miniSPIM-ANDROID/miniSPIM/src/main/AndroidManifest.xml:11:5-64
14-->/Users/bene/Dropbox/Dokumente/Promotion/PROJECTS/miniSPIM/ANDROID/miniSPIM-ANDROID/miniSPIM/src/main/AndroidManifest.xml:11:22-62
15    <uses-permission android:name="android.permission.RECORD_AUDIO" />
15-->/Users/bene/Dropbox/Dokumente/Promotion/PROJECTS/miniSPIM/ANDROID/miniSPIM-ANDROID/miniSPIM/src/main/AndroidManifest.xml:12:5-70
15-->/Users/bene/Dropbox/Dokumente/Promotion/PROJECTS/miniSPIM/ANDROID/miniSPIM-ANDROID/miniSPIM/src/main/AndroidManifest.xml:12:22-68
16    <uses-permission android:name="android.permission.WRITE_EXTERNAL_STORAGE" />
16-->/Users/bene/Dropbox/Dokumente/Promotion/PROJECTS/miniSPIM/ANDROID/miniSPIM-ANDROID/miniSPIM/src/main/AndroidManifest.xml:13:5-80
16-->/Users/bene/Dropbox/Dokumente/Promotion/PROJECTS/miniSPIM/ANDROID/miniSPIM-ANDROID/miniSPIM/src/main/AndroidManifest.xml:13:22-78
17    <uses-permission android:name="android.permission.READ_EXTERNAL_STORAGE" />
17-->/Users/bene/Dropbox/Dokumente/Promotion/PROJECTS/miniSPIM/ANDROID/miniSPIM-ANDROID/miniSPIM/src/main/AndroidManifest.xml:14:5-80
17-->/Users/bene/Dropbox/Dokumente/Promotion/PROJECTS/miniSPIM/ANDROID/miniSPIM-ANDROID/miniSPIM/src/main/AndroidManifest.xml:14:22-77
18    <uses-permission android:name="android.permission.INTERNET" />
18-->/Users/bene/Dropbox/Dokumente/Promotion/PROJECTS/miniSPIM/ANDROID/miniSPIM-ANDROID/miniSPIM/src/main/AndroidManifest.xml:15:5-66
18-->/Users/bene/Dropbox/Dokumente/Promotion/PROJECTS/miniSPIM/ANDROID/miniSPIM-ANDROID/miniSPIM/src/main/AndroidManifest.xml:15:22-64
19    <uses-permission android:name="android.permission.ACCESS_WIFI_STATE" />
19-->/Users/bene/Dropbox/Dokumente/Promotion/PROJECTS/miniSPIM/ANDROID/miniSPIM-ANDROID/miniSPIM/src/main/AndroidManifest.xml:16:5-76
19-->/Users/bene/Dropbox/Dokumente/Promotion/PROJECTS/miniSPIM/ANDROID/miniSPIM-ANDROID/miniSPIM/src/main/AndroidManifest.xml:16:22-73
20    <uses-permission android:name="android.permission.ACCESS_NETWORK_STATE" />
20-->/Users/bene/Dropbox/Dokumente/Promotion/PROJECTS/miniSPIM/ANDROID/miniSPIM-ANDROID/miniSPIM/src/main/AndroidManifest.xml:17:5-78
20-->/Users/bene/Dropbox/Dokumente/Promotion/PROJECTS/miniSPIM/ANDROID/miniSPIM-ANDROID/miniSPIM/src/main/AndroidManifest.xml:17:22-76
21    <uses-permission android:name="android.permission.CHANGE_WIFI_STATE" />
21-->/Users/bene/Dropbox/Dokumente/Promotion/PROJECTS/miniSPIM/ANDROID/miniSPIM-ANDROID/miniSPIM/src/main/AndroidManifest.xml:18:5-75
21-->/Users/bene/Dropbox/Dokumente/Promotion/PROJECTS/miniSPIM/ANDROID/miniSPIM-ANDROID/miniSPIM/src/main/AndroidManifest.xml:18:22-73
22    <uses-permission android:name="android.permission.ACCESS_FINE_LOCATION" />
22-->/Users/bene/Dropbox/Dokumente/Promotion/PROJECTS/miniSPIM/ANDROID/miniSPIM-ANDROID/miniSPIM/src/main/AndroidManifest.xml:19:5-79
22-->/Users/bene/Dropbox/Dokumente/Promotion/PROJECTS/miniSPIM/ANDROID/miniSPIM-ANDROID/miniSPIM/src/main/AndroidManifest.xml:19:22-76
23    <uses-permission android:name="android.permission.ACCESS_COARSE_LOCATION" />
23-->/Users/bene/Dropbox/Dokumente/Promotion/PROJECTS/miniSPIM/ANDROID/miniSPIM-ANDROID/miniSPIM/src/main/AndroidManifest.xml:20:5-81
23-->/Users/bene/Dropbox/Dokumente/Promotion/PROJECTS/miniSPIM/ANDROID/miniSPIM-ANDROID/miniSPIM/src/main/AndroidManifest.xml:20:22-78
24    <!-- used on huawei p9/10 and for new devices? -->
25    <uses-permission android:name="android.permission.HW_CAMCFG_SERVICE" />
25-->/Users/bene/Dropbox/Dokumente/Promotion/PROJECTS/miniSPIM/ANDROID/miniSPIM-ANDROID/miniSPIM/src/main/AndroidManifest.xml:22:5-76
25-->/Users/bene/Dropbox/Dokumente/Promotion/PROJECTS/miniSPIM/ANDROID/miniSPIM-ANDROID/miniSPIM/src/main/AndroidManifest.xml:22:22-73
26    <uses-permission android:name="com.huawei.camera.permission.PRIVATE" />
26-->/Users/bene/Dropbox/Dokumente/Promotion/PROJECTS/miniSPIM/ANDROID/miniSPIM-ANDROID/miniSPIM/src/main/AndroidManifest.xml:23:5-76
26-->/Users/bene/Dropbox/Dokumente/Promotion/PROJECTS/miniSPIM/ANDROID/miniSPIM-ANDROID/miniSPIM/src/main/AndroidManifest.xml:23:22-73
27    <uses-permission android:name="huawei.android.permission.HW_SIGNATURE_OR_SYSTEM" />
27-->/Users/bene/Dropbox/Dokumente/Promotion/PROJECTS/miniSPIM/ANDROID/miniSPIM-ANDROID/miniSPIM/src/main/AndroidManifest.xml:24:5-88
27-->/Users/bene/Dropbox/Dokumente/Promotion/PROJECTS/miniSPIM/ANDROID/miniSPIM-ANDROID/miniSPIM/src/main/AndroidManifest.xml:24:22-85
28    <!-- used on huawei p9/10 and for new devices? -->
29    <uses-permission android:name="android.permission.WAKE_LOCK" />
29-->/Users/bene/Dropbox/Dokumente/Promotion/PROJECTS/miniSPIM/ANDROID/miniSPIM-ANDROID/miniSPIM/src/main/AndroidManifest.xml:26:5-67
29-->/Users/bene/Dropbox/Dokumente/Promotion/PROJECTS/miniSPIM/ANDROID/miniSPIM-ANDROID/miniSPIM/src/main/AndroidManifest.xml:26:22-65
30    <!-- uses-feature android:name="android.hardware.camera" android:required="true"/ -->
31    <!-- uses-feature android:name="android.hardware.camera.autofocus" android:required="false"/ -->
32    <!-- uses-feature android:name="android.hardware.sensor.compass" android:required="false"/ -->
33    <uses-permission android:name="android.permission.WAKE_LOCK" />
33-->/Users/bene/Dropbox/Dokumente/Promotion/PROJECTS/miniSPIM/ANDROID/miniSPIM-ANDROID/miniSPIM/src/main/AndroidManifest.xml:26:5-67
33-->/Users/bene/Dropbox/Dokumente/Promotion/PROJECTS/miniSPIM/ANDROID/miniSPIM-ANDROID/miniSPIM/src/main/AndroidManifest.xml:26:22-65
34    <uses-permission android:name="android.permission.ACCESS_NETWORK_STATE" />
34-->/Users/bene/Dropbox/Dokumente/Promotion/PROJECTS/miniSPIM/ANDROID/miniSPIM-ANDROID/miniSPIM/src/main/AndroidManifest.xml:17:5-78
34-->/Users/bene/Dropbox/Dokumente/Promotion/PROJECTS/miniSPIM/ANDROID/miniSPIM-ANDROID/miniSPIM/src/main/AndroidManifest.xml:17:22-76
35    <uses-permission android:name="android.permission.READ_PHONE_STATE" />
35-->/Users/bene/Dropbox/Dokumente/Promotion/PROJECTS/miniSPIM/ANDROID/miniSPIM-ANDROID/miniSPIM/src/main/AndroidManifest.xml:32:5-75
35-->/Users/bene/Dropbox/Dokumente/Promotion/PROJECTS/miniSPIM/ANDROID/miniSPIM-ANDROID/miniSPIM/src/main/AndroidManifest.xml:32:22-72
36
37    <uses-feature
37-->/Users/bene/Dropbox/Dokumente/Promotion/PROJECTS/miniSPIM/ANDROID/miniSPIM-ANDROID/miniSPIM/src/main/AndroidManifest.xml:34:5-78
38        android:glEsVersion="0x00020000"
38-->/Users/bene/Dropbox/Dokumente/Promotion/PROJECTS/miniSPIM/ANDROID/miniSPIM-ANDROID/miniSPIM/src/main/AndroidManifest.xml:34:19-51
39        android:required="true" />
39-->/Users/bene/Dropbox/Dokumente/Promotion/PROJECTS/miniSPIM/ANDROID/miniSPIM-ANDROID/miniSPIM/src/main/AndroidManifest.xml:34:52-75
40
41    <application
41-->/Users/bene/Dropbox/Dokumente/Promotion/PROJECTS/miniSPIM/ANDROID/miniSPIM-ANDROID/miniSPIM/src/main/AndroidManifest.xml:36:5-71:19
42        android:allowBackup="true"
42-->/Users/bene/Dropbox/Dokumente/Promotion/PROJECTS/miniSPIM/ANDROID/miniSPIM-ANDROID/miniSPIM/src/main/AndroidManifest.xml:37:9-35
43        android:debuggable="true"
44        android:icon="@drawable/microscope_icon"
44-->/Users/bene/Dropbox/Dokumente/Promotion/PROJECTS/miniSPIM/ANDROID/miniSPIM-ANDROID/miniSPIM/src/main/AndroidManifest.xml:38:9-49
45        android:label="@string/app_name"
45-->/Users/bene/Dropbox/Dokumente/Promotion/PROJECTS/miniSPIM/ANDROID/miniSPIM-ANDROID/miniSPIM/src/main/AndroidManifest.xml:39:9-41
46        android:supportsRtl="true"
46-->/Users/bene/Dropbox/Dokumente/Promotion/PROJECTS/miniSPIM/ANDROID/miniSPIM-ANDROID/miniSPIM/src/main/AndroidManifest.xml:41:9-35
47        android:testOnly="true"
48        android:theme="@android:style/Theme.Holo.Light" >
48-->/Users/bene/Dropbox/Dokumente/Promotion/PROJECTS/miniSPIM/ANDROID/miniSPIM-ANDROID/miniSPIM/src/main/AndroidManifest.xml:40:9-56
49        <service android:name="org.eclipse.paho.android.service.MqttService" />
49-->/Users/bene/Dropbox/Dokumente/Promotion/PROJECTS/miniSPIM/ANDROID/miniSPIM-ANDROID/miniSPIM/src/main/AndroidManifest.xml:42:9-80
49-->/Users/bene/Dropbox/Dokumente/Promotion/PROJECTS/miniSPIM/ANDROID/miniSPIM-ANDROID/miniSPIM/src/main/AndroidManifest.xml:42:18-77
50
51        <activity
51-->/Users/bene/Dropbox/Dokumente/Promotion/PROJECTS/miniSPIM/ANDROID/miniSPIM-ANDROID/miniSPIM/src/main/AndroidManifest.xml:43:9-51:20
52            android:name="de.minispim.activity.SplashActivity"
52-->/Users/bene/Dropbox/Dokumente/Promotion/PROJECTS/miniSPIM/ANDROID/miniSPIM-ANDROID/miniSPIM/src/main/AndroidManifest.xml:44:13-63
53            android:label="@string/app_name"
53-->/Users/bene/Dropbox/Dokumente/Promotion/PROJECTS/miniSPIM/ANDROID/miniSPIM-ANDROID/miniSPIM/src/main/AndroidManifest.xml:45:13-45
54            android:screenOrientation="portrait" >
54-->/Users/bene/Dropbox/Dokumente/Promotion/PROJECTS/miniSPIM/ANDROID/miniSPIM-ANDROID/miniSPIM/src/main/AndroidManifest.xml:46:13-49
55            <intent-filter>
55-->/Users/bene/Dropbox/Dokumente/Promotion/PROJECTS/miniSPIM/ANDROID/miniSPIM-ANDROID/miniSPIM/src/main/AndroidManifest.xml:47:13-50:29
56                <action android:name="android.intent.action.MAIN" />
56-->/Users/bene/Dropbox/Dokumente/Promotion/PROJECTS/miniSPIM/ANDROID/miniSPIM-ANDROID/miniSPIM/src/main/AndroidManifest.xml:48:17-69
56-->/Users/bene/Dropbox/Dokumente/Promotion/PROJECTS/miniSPIM/ANDROID/miniSPIM-ANDROID/miniSPIM/src/main/AndroidManifest.xml:48:25-66
57
58                <category android:name="android.intent.category.LAUNCHER" />
58-->/Users/bene/Dropbox/Dokumente/Promotion/PROJECTS/miniSPIM/ANDROID/miniSPIM-ANDROID/miniSPIM/src/main/AndroidManifest.xml:49:17-77
58-->/Users/bene/Dropbox/Dokumente/Promotion/PROJECTS/miniSPIM/ANDROID/miniSPIM-ANDROID/miniSPIM/src/main/AndroidManifest.xml:49:27-74
59            </intent-filter>
60        </activity>
61        <activity
61-->/Users/bene/Dropbox/Dokumente/Promotion/PROJECTS/miniSPIM/ANDROID/miniSPIM-ANDROID/miniSPIM/src/main/AndroidManifest.xml:52:9-55:20
62            android:name="de.minispim.activity.MainActivity"
62-->/Users/bene/Dropbox/Dokumente/Promotion/PROJECTS/miniSPIM/ANDROID/miniSPIM-ANDROID/miniSPIM/src/main/AndroidManifest.xml:53:13-61
63            android:screenOrientation="portrait" >
63-->/Users/bene/Dropbox/Dokumente/Promotion/PROJECTS/miniSPIM/ANDROID/miniSPIM-ANDROID/miniSPIM/src/main/AndroidManifest.xml:54:13-49
64        </activity>
65        <activity
65-->/Users/bene/Dropbox/Dokumente/Promotion/PROJECTS/miniSPIM/ANDROID/miniSPIM-ANDROID/miniSPIM/src/main/AndroidManifest.xml:56:9-59:20
66            android:name="de.minispim.activity.ZoomableImageActivity"
66-->/Users/bene/Dropbox/Dokumente/Promotion/PROJECTS/miniSPIM/ANDROID/miniSPIM-ANDROID/miniSPIM/src/main/AndroidManifest.xml:57:13-70
67            android:screenOrientation="portrait" >
67-->/Users/bene/Dropbox/Dokumente/Promotion/PROJECTS/miniSPIM/ANDROID/miniSPIM-ANDROID/miniSPIM/src/main/AndroidManifest.xml:58:13-49
68        </activity>
69        <activity
69-->/Users/bene/Dropbox/Dokumente/Promotion/PROJECTS/miniSPIM/ANDROID/miniSPIM-ANDROID/miniSPIM/src/main/AndroidManifest.xml:60:9-64:20
70            android:name="de.minispim.acquisition.AcquireResultActivity"
70-->/Users/bene/Dropbox/Dokumente/Promotion/PROJECTS/miniSPIM/ANDROID/miniSPIM-ANDROID/miniSPIM/src/main/AndroidManifest.xml:61:13-73
71            android:largeHeap="true"
71-->/Users/bene/Dropbox/Dokumente/Promotion/PROJECTS/miniSPIM/ANDROID/miniSPIM-ANDROID/miniSPIM/src/main/AndroidManifest.xml:62:13-37
72            android:screenOrientation="portrait" >
72-->/Users/bene/Dropbox/Dokumente/Promotion/PROJECTS/miniSPIM/ANDROID/miniSPIM-ANDROID/miniSPIM/src/main/AndroidManifest.xml:63:13-49
73        </activity>
74        <activity
74-->/Users/bene/Dropbox/Dokumente/Promotion/PROJECTS/miniSPIM/ANDROID/miniSPIM-ANDROID/miniSPIM/src/main/AndroidManifest.xml:65:9-69:20
75            android:name="de.minispim.acquisition.AcquireActivity"
75-->/Users/bene/Dropbox/Dokumente/Promotion/PROJECTS/miniSPIM/ANDROID/miniSPIM-ANDROID/miniSPIM/src/main/AndroidManifest.xml:66:13-67
76            android:largeHeap="true"
76-->/Users/bene/Dropbox/Dokumente/Promotion/PROJECTS/miniSPIM/ANDROID/miniSPIM-ANDROID/miniSPIM/src/main/AndroidManifest.xml:67:13-37
77            android:screenOrientation="portrait" >
77-->/Users/bene/Dropbox/Dokumente/Promotion/PROJECTS/miniSPIM/ANDROID/miniSPIM-ANDROID/miniSPIM/src/main/AndroidManifest.xml:68:13-49
78        </activity>
79        <!--
80 ATTENTION: This was auto-generated to add Google Play services to your project for
81     App Indexing.  See https://g.co/AppIndexing/AndroidStudio for more information.
82        -->
83        <meta-data
83-->[com.android.support:support-v13:26.1.0] /Users/bene/.gradle/caches/transforms-2/files-2.1/baa46286eba7cc6c8a706f0ddaa15535/support-v13-26.1.0/AndroidManifest.xml:26:9-28:38
84            android:name="android.support.VERSION"
84-->[com.android.support:support-v13:26.1.0] /Users/bene/.gradle/caches/transforms-2/files-2.1/baa46286eba7cc6c8a706f0ddaa15535/support-v13-26.1.0/AndroidManifest.xml:27:13-51
85            android:value="26.1.0" />
85-->[com.android.support:support-v13:26.1.0] /Users/bene/.gradle/caches/transforms-2/files-2.1/baa46286eba7cc6c8a706f0ddaa15535/support-v13-26.1.0/AndroidManifest.xml:28:13-35
86        <meta-data
86-->[android.arch.lifecycle:runtime:1.0.0] /Users/bene/.gradle/caches/transforms-2/files-2.1/2651008cd98233e6b4b850667bef3705/runtime-1.0.0/AndroidManifest.xml:25:9-27:47
87            android:name="android.arch.lifecycle.VERSION"
87-->[android.arch.lifecycle:runtime:1.0.0] /Users/bene/.gradle/caches/transforms-2/files-2.1/2651008cd98233e6b4b850667bef3705/runtime-1.0.0/AndroidManifest.xml:26:13-58
88            android:value="27.0.0-SNAPSHOT" />
88-->[android.arch.lifecycle:runtime:1.0.0] /Users/bene/.gradle/caches/transforms-2/files-2.1/2651008cd98233e6b4b850667bef3705/runtime-1.0.0/AndroidManifest.xml:27:13-44
89    </application>
90
91</manifest>

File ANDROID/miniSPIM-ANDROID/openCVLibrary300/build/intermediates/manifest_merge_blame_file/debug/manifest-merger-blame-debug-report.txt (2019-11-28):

1<?xml version="1.0" encoding="utf-8"?>
2<manifest xmlns:android="http://schemas.android.com/apk/res/android"
3    package="org.opencv"
4    android:versionCode="3000"
5    android:versionName="3.0.0" >
6
7    <uses-sdk
8        android:minSdkVersion="21"
8-->/Users/bene/Dropbox/Dokumente/Promotion/PROJECTS/miniSPIM/ANDROID/miniSPIM-ANDROID/openCVLibrary300/src/main/AndroidManifest.xml
9        android:targetSdkVersion="26" />
9-->/Users/bene/Dropbox/Dokumente/Promotion/PROJECTS/miniSPIM/ANDROID/miniSPIM-ANDROID/openCVLibrary300/src/main/AndroidManifest.xml
10
11</manifest>

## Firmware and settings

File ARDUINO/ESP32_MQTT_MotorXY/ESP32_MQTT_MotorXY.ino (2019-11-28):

/* Here ESP32 will keep 2 roles:
  1/ read data from DHT11/DHT22 sensor
  2/ control led on-off
  So it willpublish temperature topic and scribe topic bulb on/off
*/

#include <WiFi.h>
#include <PubSubClient.h>
#include <Stepper.h>

/* change it with your ssid-password */
const char* ssid = "Blynk";
const char* password = "12345678";
/* this is the IP of PC/raspberry where you installed MQTT Server
  on Wins use "ipconfig"
  on Linux use "ifconfig" to get its IP address */
const char* mqtt_server = "192.168.43.86";


/* create an instance of PubSubClient client */
WiFiClient espClient;
PubSubClient client(espClient);

/*LED GPIO pin*/
int LED_PIN = 2;

/*LASER GPIO pin*/
int LASER_PIN_PLUS = 22;
int LASER_PIN_MINUS = 23;

/*Lens GPIO pins*/
int LENS_X_PIN = 25;
int LENS_Z_PIN = 26;

///* topics - DON'T FORGET TO REGISTER THEM! */
#define LED_TOPIC         "led/on"
#define STEPPER_X_FWD     "stepper/x/fwd"
#define STEPPER_X_BWD     "stepper/x/bwd"
#define STEPPER_Y_FWD     "stepper/y/fwd"
#define STEPPER_Y_BWD     "stepper/y/bwd"



#define STEPS 200

#define CLIENT_ID "ESP32Client_minispim";


// create an instance of the stepper class, specifying
// the number of steps of the motor and the pins it's
// attached to
int motorPin_X[] = {12,27,14,26};
int motorPin_Y[] = {16,5,17,18};
unsigned int highSpeed = 1000;


// MQTT Stuff
long lastMsg = 0;
char msg[20];

void setup() {

  /* set led and laser as output to control led on-off */
  pinMode(LED_PIN, OUTPUT);
  
  // Visualize, that ESP is on!
  digitalWrite(LED_PIN, HIGH);
  delay(1000);
  digitalWrite(LED_PIN, LOW);

  // MOTOR x
  pinMode(motorPin_X[0], OUTPUT);
  pinMode(motorPin_X[1], OUTPUT);
  pinMode(motorPin_X[2], OUTPUT);
  pinMode(motorPin_X[3], OUTPUT);

    // MOTOR y
  pinMode(motorPin_Y[0], OUTPUT);
  pinMode(motorPin_Y[1], OUTPUT);
  pinMode(motorPin_Y[2], OUTPUT);
  pinMode(motorPin_Y[3], OUTPUT);

  
  Serial.begin(115200);
  // We start by connecting to a WiFi network
  Serial.println();
  Serial.print("Connecting to ");
  Serial.println(ssid);

  WiFi.begin(ssid, password);

  while (WiFi.status() != WL_CONNECTED) {
    delay(500);
    Serial.print(".");
  }
  
  Serial.println("");
  Serial.println("WiFi connected");
  Serial.println("IP address: ");
  Serial.println(WiFi.localIP());

  /* configure the MQTT server with IPaddress and port */
  client.setServer(mqtt_server, 1883);
  /* this receivedCallback function will be invoked
    when client received subscribed topic */
  client.setCallback(receivedCallback);

}

void loop() {
  /* if client was disconnected then try to reconnect again */
  if (!client.connected()) {
    mqttconnect();
  }
  /* this function will listen for incomming
    subscribed topic-process-invoke receivedCallback */
  client.loop();
}




void receivedCallback(char* topic, byte* payload, unsigned int length) {
  Serial.print("Message received: ");
  Serial.println(topic);

  // Convert pointer to int
  int payload_int = 0;
  for (int i = 0; i < length; i++) {
    char c = payload[i];
    if (c >= '0' && c <= '9')
      payload_int = payload_int * 10 + c - '0'; //einzelne Ziffern zu einem Integer zusammenfügen
    else {
      Serial.print ((int)c);
      Serial.println(" war so nicht erwartet");
    }
  }

  Serial.print("Value is : [");
  Serial.print(payload_int);
  Serial.print("]");



  // Just for debugging 
  if (String(topic) == LED_TOPIC)  {
    /* we got '1' -> on */
    if (payload_int == 1) {
      digitalWrite(LED_PIN, HIGH);
    } else {
      /* we got '0' -> on */
      digitalWrite(LED_PIN, LOW);
    }
  }

   // Catch the value for stepment of lens in X-direction
  if (String(topic) == STEPPER_X_FWD) {
    // Drive motor X in positive direction
    drive_left(highSpeed, motorPin_X,(int)payload_int);
    stop(motorPin_X);
    Serial.print("Motor is running in x for: ");
    Serial.print((int)payload_int);
    Serial.println();
  }

  // Catch the value for stepment of lens in Y-direction
  if (String(topic) == STEPPER_X_BWD) {
      // Drive motor X in positive direction
    drive_right(highSpeed, motorPin_X,(int)payload_int);
    stop(motorPin_X);
    Serial.print("Motor is running in x for: ");
    Serial.print((int)payload_int);
    Serial.println();
  }
     // Catch the value for stepment of lens in X-direction
  if (String(topic) == STEPPER_Y_FWD) {
    // Drive motor X in positive direction
    drive_left(highSpeed, motorPin_Y,(int)payload_int);
    stop(motorPin_Y);
    Serial.print("Motor is running in y for: ");
    Serial.print((int)payload_int);
    Serial.println();
  }

  // Catch the value for stepment of lens in Y-direction
  if (String(topic) == STEPPER_Y_BWD) {
      // Drive motor X in positive direction
    drive_right(highSpeed, motorPin_Y,(int)payload_int);
    stop(motorPin_Y);
    Serial.print("Motor is running in y for: ");
    Serial.print((int)payload_int);
    Serial.println();
  }

  
}

void mqttconnect() {
  /* Loop until reconnected */
  while (!client.connected()) {
    Serial.print("MQTT connecting ...");
    /* client ID */
    String clientId = CLIENT_ID;
    /* connect now */
    if (client.connect(clientId.c_str(), "username", "pi")) {
      Serial.println("connected");
      /* subscribe topic with default QoS 0*/
      client.subscribe(LED_TOPIC);
      client.subscribe(STEPPER_X_FWD);
      client.subscribe(STEPPER_X_BWD);
      client.subscribe(STEPPER_Y_FWD);
      client.subscribe(STEPPER_Y_BWD);

    } else {
      Serial.print("faiLED_PIN, status code =");
      Serial.print(client.state());
      Serial.println("try again in 5 seconds");
      /* Wait 5 seconds before retrying */
      delay(5000);
    }
  }
}








void drive_right(unsigned int motorSpeed, int motorPin[], int steps)
{ // 1

  int motorPin1 = motorPin[0];
  int motorPin2 = motorPin[1];
  int motorPin3 = motorPin[2];
  int motorPin4 = motorPin[3];

  for (int i = 0; i < steps; i++)
  {
    digitalWrite(motorPin4, HIGH);
    digitalWrite(motorPin3, LOW);
    digitalWrite(motorPin2, LOW);
    digitalWrite(motorPin1, LOW);
    delayMicroseconds(motorSpeed);

    // 2
    digitalWrite(motorPin4, HIGH);
    digitalWrite(motorPin3, HIGH);
    digitalWrite(motorPin2, LOW);
    digitalWrite(motorPin1, LOW);
    delayMicroseconds(motorSpeed);

    // 3
    digitalWrite(motorPin4, LOW);
    digitalWrite(motorPin3, HIGH);
    digitalWrite(motorPin2, LOW);
    digitalWrite(motorPin1, LOW);
    delayMicroseconds(motorSpeed);

    // 4
    digitalWrite(motorPin4, LOW);
    digitalWrite(motorPin3, HIGH);
    digitalWrite(motorPin2, HIGH);
    digitalWrite(motorPin1, LOW);
    delayMicroseconds(motorSpeed);

    // 5
    digitalWrite(motorPin4, LOW);
    digitalWrite(motorPin3, LOW);
    digitalWrite(motorPin2, HIGH);
    digitalWrite(motorPin1, LOW);
    delayMicroseconds(motorSpeed);

    // 6
    digitalWrite(motorPin4, LOW);
    digitalWrite(motorPin3, LOW);
    digitalWrite(motorPin2, HIGH);
    digitalWrite(motorPin1, HIGH);
    delayMicroseconds(motorSpeed);

    // 7
    digitalWrite(motorPin4, LOW);
    digitalWrite(motorPin3, LOW);
    digitalWrite(motorPin2, LOW);
    digitalWrite(motorPin1, HIGH);
    delayMicroseconds(motorSpeed);

    // 8
    digitalWrite(motorPin4, HIGH);
    digitalWrite(motorPin3, LOW);
    digitalWrite(motorPin2, LOW);
    digitalWrite(motorPin1, HIGH);
    delayMicroseconds(motorSpeed);
  }
}

void drive_left(unsigned int motorSpeed, int motorPin[], int steps)
{ // 1

  int motorPin1 = motorPin[0];
  int motorPin2 = motorPin[1];
  int motorPin3 = motorPin[2];
  int motorPin4 = motorPin[3];

  for (int i = 0; i < steps; i++)
  {
    // 1
    digitalWrite(motorPin1, HIGH);
    digitalWrite(motorPin2, LOW);
    digitalWrite(motorPin3, LOW);
    digitalWrite(motorPin4, LOW);
    delayMicroseconds(motorSpeed);

    // 2
    digitalWrite(motorPin1, HIGH);
    digitalWrite(motorPin2, HIGH);
    digitalWrite(motorPin3, LOW);
    digitalWrite(motorPin4, LOW);
    delayMicroseconds(motorSpeed);

    // 3
    digitalWrite(motorPin1, LOW);
    digitalWrite(motorPin2, HIGH);
    digitalWrite(motorPin3, LOW);
    digitalWrite(motorPin4, LOW);
    delayMicroseconds(motorSpeed);

    // 4
    digitalWrite(motorPin1, LOW);
    digitalWrite(motorPin2, HIGH);
    digitalWrite(motorPin3, HIGH);
    digitalWrite(motorPin4, LOW);
    delayMicroseconds(motorSpeed);

    // 5
    digitalWrite(motorPin1, LOW);
    digitalWrite(motorPin2, LOW);
    digitalWrite(motorPin3, HIGH);
    digitalWrite(motorPin4, LOW);
    delayMicroseconds(motorSpeed);

    // 6
    digitalWrite(motorPin1, LOW);
    digitalWrite(motorPin2, LOW);
    digitalWrite(motorPin3, HIGH);
    digitalWrite(motorPin4, HIGH);
    delayMicroseconds(motorSpeed);

    // 7
    digitalWrite(motorPin1, LOW);
    digitalWrite(motorPin2, LOW);
    digitalWrite(motorPin3, LOW);
    digitalWrite(motorPin4, HIGH);
    delayMicroseconds(motorSpeed);

    // 8
    digitalWrite(motorPin1, HIGH);
    digitalWrite(motorPin2, LOW);
    digitalWrite(motorPin3, LOW);
    digitalWrite(motorPin4, HIGH);
    delayMicroseconds(motorSpeed);
  }
}


void stop(int motorPin[])
{
  int motorPin1 = motorPin[0];
  int motorPin2 = motorPin[1];
  int motorPin3 = motorPin[2];
  int motorPin4 = motorPin[3];

  digitalWrite(motorPin4, LOW);
  digitalWrite(motorPin3, LOW);
  digitalWrite(motorPin2, LOW);
  digitalWrite(motorPin1, LOW);
}

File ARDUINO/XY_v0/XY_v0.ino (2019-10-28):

//const int motorPin1 = 6;  // Blue   - In 1
//const int motorPin2 = 7;  // Pink   - In 2
//const int motorPin3 = 8; // Yellow - In 3
//const int motorPin4 = 9; // Orange - In 4
//                          // Red    - pin 5 (VCC)


// Red    - pin
int motorPin_X[] = {2, 3, 4, 5};
int motorPin_Y[] = {9, 7, 8, 6};
int motorPin_Z[] = {13, 11, 12, 10};

//int motorPin_X[] = {13,12,14,27};
//int motorPin_Y[] = {26,25,23,32};
//int motorPin_Z[] = {2, 3, 4, 5};



unsigned int lowSpeed  = 10; // Notabene: nicht über 16000
unsigned int highSpeed =  20;
int amplitude = 20;

void setup() {
  pinMode(motorPin_X[0], OUTPUT);
  pinMode(motorPin_X[1], OUTPUT);
  pinMode(motorPin_X[2], OUTPUT);
  pinMode(motorPin_X[3], OUTPUT);
  pinMode(motorPin_Y[0], OUTPUT);
  pinMode(motorPin_Y[1], OUTPUT);
  pinMode(motorPin_Y[2], OUTPUT);
  pinMode(motorPin_Y[3], OUTPUT);
  pinMode(motorPin_Z[0], OUTPUT);
  pinMode(motorPin_Z[1], OUTPUT);
  pinMode(motorPin_Z[2], OUTPUT);
  pinMode(motorPin_Z[3], OUTPUT);
}

void loop()
{
  if (0) {
    drive_left(highSpeed, motorPin_X, 100);
    stop(motorPin_X);
    drive_right(highSpeed, motorPin_X, 100);
    stop(motorPin_X);
  }


  if (1) {
    drive_right(highSpeed, motorPin_Y, amplitude );
    stop(motorPin_Y);
    drive_left(highSpeed, motorPin_Y, amplitude );
    stop(motorPin_Y);
  }


  if (0) {
    drive_right(highSpeed, motorPin_Z, 50);
    stop(motorPin_Z);
    drive_left(highSpeed, motorPin_Z, 50);
    stop(motorPin_Z);
  }


}

void drive_right(unsigned int motorSpeed, int motorPin[], int steps)
{ // 1

  int motorPin1 = motorPin[0];
  int motorPin2 = motorPin[1];
  int motorPin3 = motorPin[2];
  int motorPin4 = motorPin[3];

  for (int i = 0; i < steps; i++)
  {
    digitalWrite(motorPin4, HIGH);
    digitalWrite(motorPin3, LOW);
    digitalWrite(motorPin2, LOW);
    digitalWrite(motorPin1, LOW);
    delay(motorSpeed);

    // 2
    digitalWrite(motorPin4, HIGH);
    digitalWrite(motorPin3, HIGH);
    digitalWrite(motorPin2, LOW);
    digitalWrite(motorPin1, LOW);
    delay(motorSpeed);

    // 3
    digitalWrite(motorPin4, LOW);
    digitalWrite(motorPin3, HIGH);
    digitalWrite(motorPin2, LOW);
    digitalWrite(motorPin1, LOW);
    delay(motorSpeed);

    // 4
    digitalWrite(motorPin4, LOW);
    digitalWrite(motorPin3, HIGH);
    digitalWrite(motorPin2, HIGH);
    digitalWrite(motorPin1, LOW);
    delay(motorSpeed);

    // 5
    digitalWrite(motorPin4, LOW);
    digitalWrite(motorPin3, LOW);
    digitalWrite(motorPin2, HIGH);
    digitalWrite(motorPin1, LOW);
    delay(motorSpeed);

    // 6
    digitalWrite(motorPin4, LOW);
    digitalWrite(motorPin3, LOW);
    digitalWrite(motorPin2, HIGH);
    digitalWrite(motorPin1, HIGH);
    delay(motorSpeed);

    // 7
    digitalWrite(motorPin4, LOW);
    digitalWrite(motorPin3, LOW);
    digitalWrite(motorPin2, LOW);
    digitalWrite(motorPin1, HIGH);
    delay(motorSpeed);

    // 8
    digitalWrite(motorPin4, HIGH);
    digitalWrite(motorPin3, LOW);
    digitalWrite(motorPin2, LOW);
    digitalWrite(motorPin1, HIGH);
    delay(motorSpeed);
  }
}

void drive_left(unsigned int motorSpeed, int motorPin[], int steps)
{ // 1

  int motorPin1 = motorPin[0];
  int motorPin2 = motorPin[1];
  int motorPin3 = motorPin[2];
  int motorPin4 = motorPin[3];

  for (int i = 0; i < steps; i++)
  {
    // 1
    digitalWrite(motorPin1, HIGH);
    digitalWrite(motorPin2, LOW);
    digitalWrite(motorPin3, LOW);
    digitalWrite(motorPin4, LOW);
    delay(motorSpeed);

    // 2
    digitalWrite(motorPin1, HIGH);
    digitalWrite(motorPin2, HIGH);
    digitalWrite(motorPin3, LOW);
    digitalWrite(motorPin4, LOW);
    delay(motorSpeed);

    // 3
    digitalWrite(motorPin1, LOW);
    digitalWrite(motorPin2, HIGH);
    digitalWrite(motorPin3, LOW);
    digitalWrite(motorPin4, LOW);
    delay(motorSpeed);

    // 4
    digitalWrite(motorPin1, LOW);
    digitalWrite(motorPin2, HIGH);
    digitalWrite(motorPin3, HIGH);
    digitalWrite(motorPin4, LOW);
    delay(motorSpeed);

    // 5
    digitalWrite(motorPin1, LOW);
    digitalWrite(motorPin2, LOW);
    digitalWrite(motorPin3, HIGH);
    digitalWrite(motorPin4, LOW);
    delay(motorSpeed);

    // 6
    digitalWrite(motorPin1, LOW);
    digitalWrite(motorPin2, LOW);
    digitalWrite(motorPin3, HIGH);
    digitalWrite(motorPin4, HIGH);
    delay(motorSpeed);

    // 7
    digitalWrite(motorPin1, LOW);
    digitalWrite(motorPin2, LOW);
    digitalWrite(motorPin3, LOW);
    digitalWrite(motorPin4, HIGH);
    delay(motorSpeed);

    // 8
    digitalWrite(motorPin1, HIGH);
    digitalWrite(motorPin2, LOW);
    digitalWrite(motorPin3, LOW);
    digitalWrite(motorPin4, HIGH);
    delay(motorSpeed);
  }
}


void stop(int motorPin[])
{ 
  
  int motorPin1 = motorPin[0];
  int motorPin2 = motorPin[1];
  int motorPin3 = motorPin[2];
  int motorPin4 = motorPin[3];

  digitalWrite(motorPin4, LOW);
  digitalWrite(motorPin3, LOW);
  digitalWrite(motorPin2, LOW);
  digitalWrite(motorPin1, LOW);
}

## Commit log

2019-10-28 Initial Commit.
    [00_Huawei_P9.ipt, 00_Laserpointer_450nm_blue.ipt, 00_Lens_f_25mm.0001.ipt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]
2019-11-28 Added the Android App.
    [110_Syrringeholder_XY_Stage.0001.ipt, 110_Syrringeholder_XY_Stage.ipt, 110_Syrringeholder_XY_Stage.stl]
2019-12-04 APP: Now the FOV is not cropped, added SNAP mode for LS measurements in APP
    [Assembly_miniSPIM_v1.0026.iam, Assembly_miniSPIM_v1.0027.iam, Assembly_miniSPIM_v1.iam]
